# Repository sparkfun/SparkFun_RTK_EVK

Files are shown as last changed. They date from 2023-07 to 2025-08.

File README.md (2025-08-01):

SparkFun RTK EVK
========================================

SparkFun RTK EVK (https://www.sparkfun.com/sparkfun-rtk-evk.html)

[*SparkFun RTK EVK (GPS-24342)*](https://www.sparkfun.com/sparkfun-rtk-evk.html)

Designed and manufactured in Boulder, Colorado, USA, the SparkFun RTK Evaluation Kit is the perfect development platform for your fixed or mobile high-precision positioning and navigation needs. In terms of connectivity, the SparkFun RTK EVK has the lot: WiFi / BT, Ethernet and cellular!

Under the hood, the RTK EVK is based on the Espressif ESP32-WROVER processor with 16MB flash and 8MB PSRAM. The GNSS is the excellent dual-band ZED-F9P from u-blox. The u-blox NEO-D9S provides L-Band reception and access to correction services such as PointPerfect. The u-blox LARA-R6001D provides worldwide cellular connectivity; insert your nano SIM into the front panel and away you go! A WIZnet W5500 provides 10 / 100 megabit Ethernet connectivity. Data storage is micro-SD. The OLED display is 128x64 pixels. The EVK supports multiple power options, including: USB-C; Power over Ethernet (PoE); and DC voltages in the range 9V - 36V. 

Documentation
--------------

* **[Hookup Guide](http://docs.sparkfun.com/SparkFun_RTK_EVK/)** - Hookup Guide for the RTK EVK hosted by GitHub pages.
* **[RTK Everywhere Product Manual](https://docs.sparkfun.com/SparkFun_RTK_Everywhere_Firmware/)** - RTK Everywhere product manual hosted by GitHub Pages.

*Need to download or print our hookup guide?*

* [Print *(Print to PDF)* from Single-Page View](http://docs.sparkfun.com/SparkFun_RTK_EVK/print_view)

Repository Contents
-------------------

* **[/docs](/docs/)** - Online documentation files
    * **[assets](/docs/assets/)** - Assets files
        * **[RTK_EVK_Enclosure](/docs/assets/RTK_EVK_Enclosure/)**
            * **[/Front_Panel](/Front_Panel/)** - Eagle design files (.brd, .sch) for the prototype (PCB) enclosure panel used to validate the dimensions
            * **[/Front_Sticker](/Front_Sticker/)** - DXF and PDF files for the front sticker
            * **[/Rear_Panel](/Rear_Panel/)** - Eagle design files (.brd, .sch) for the prototype (PCB) enclosure panel used to validate the dimensions
            * **[/Rear_Sticker](/Rear_Sticker/)** - DXF and PDF files for the rear sticker
        * **[board_files](/docs/assets/board_files/)** - Files for the product design
        * **[img/](/docs/assets/img/hookup_guide/)** - Images for hookup guide documentation
* **[/Example_Sketches](/Example_Sketches/)** - Arduino IDE code examples
* **[/Hardware](/Hardware/)** - Eagle design files (.brd, .sch)
* **[/Production](/Production/)** - PCB panel production files

Firmware
----------------

The RTK Everywhere firmware has its own [dedicated repo](https://github.com/sparkfun/SparkFun_RTK_Everywhere_Firmware) as listed below.

* **[RTK Everywhere Firmware](https://github.com/sparkfun/SparkFun_RTK_Everywhere_Firmware)**
* **[RTK Everywhere Firmware Binaries](https://github.com/sparkfun/SparkFun_RTK_Everywhere_Firmware_Binaries)**

Product Variants
----------------

* [GPS-24342](https://www.sparkfun.com/sparkfun-rtk-evk.html)- v1.1, Initial Release

Version History
---------------

* v1.1- Initial Release

License Information
-------------------

This product is ***open source***!

Please review the [LICENSE.md](./LICENSE.md) file for license information.

If you have any questions or concerns about licensing, please contact technical support on our [SparkFun forums](https://forum.sparkfun.com/viewforum.php?f=152).

Distributed as-is; no warranty is given.

- Your friends at SparkFun.

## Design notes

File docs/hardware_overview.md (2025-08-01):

The electronics of the SparkFun RTK EVK is enclosed in a custom extruded aluminum case with machined end panels and slotted flanges.

<div style="text-align: center;">
  <table>
    <tr style="vertical-align:middle;">
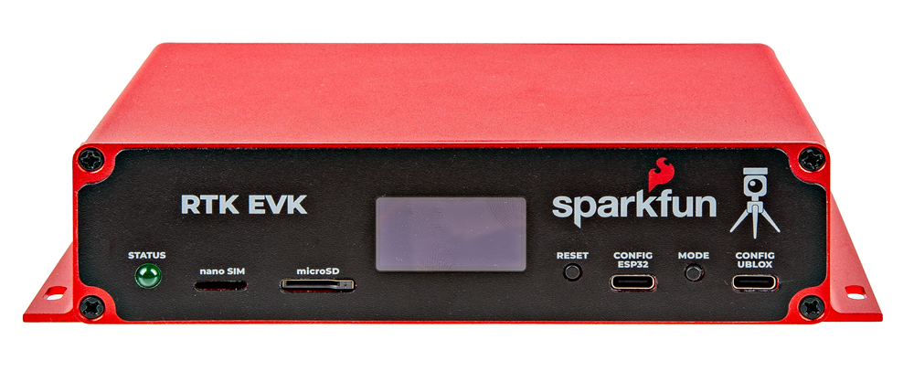
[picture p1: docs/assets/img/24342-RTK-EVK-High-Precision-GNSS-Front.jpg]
Front View
     <td style="text-align: center; vertical-align: middle; border: solid 1px #cccccc;"></td>
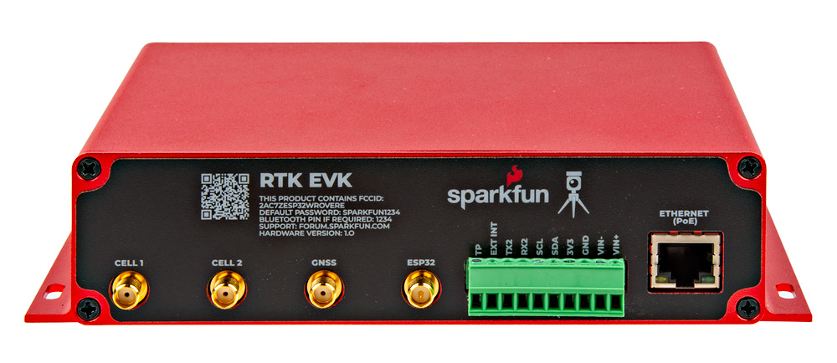
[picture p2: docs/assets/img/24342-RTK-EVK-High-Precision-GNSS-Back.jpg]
Back View
     <td style="text-align: center; vertical-align: middle; border: solid 1px #cccccc;"></td>
    </tr>
    <tr style="vertical-align:middle;">
     <td style="text-align: center; vertical-align: middle; border: solid 1px #cccccc;"><i>Front View</i></td>
     <td style="text-align: center; vertical-align: middle; border: solid 1px #cccccc;"><i>Back View</i></td>
    </tr>
  </table>
</div>

The image below shows a top and bottom view of the populated PCB without the enclosure.

<div style="text-align: center;">
  <table>
    <tr style="vertical-align:middle;">
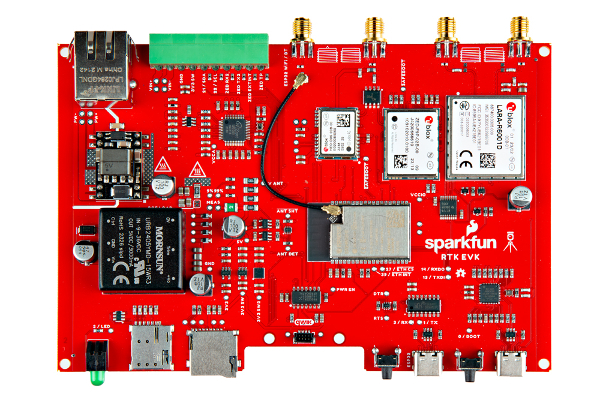
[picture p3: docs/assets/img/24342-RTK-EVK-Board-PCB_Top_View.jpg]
PCB Top View
     <td style="text-align: center; vertical-align: middle; border: solid 1px #cccccc;"></td>
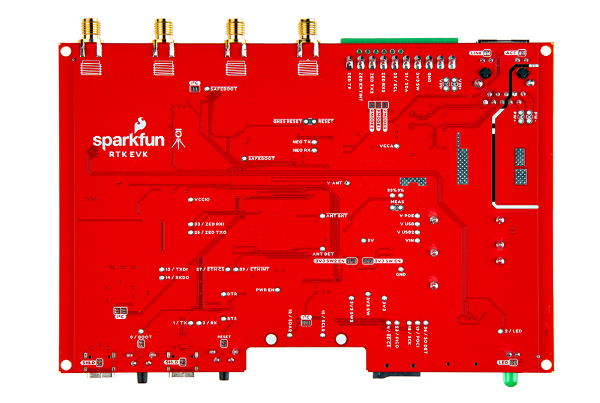
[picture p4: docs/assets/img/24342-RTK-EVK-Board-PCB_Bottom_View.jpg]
PCB Back View
     <td style="text-align: center; vertical-align: middle; border: solid 1px #cccccc;"></td>
    </tr>
    <tr style="vertical-align:middle;">
     <td style="text-align: center; vertical-align: middle; border: solid 1px #cccccc;"><i>PCB Top View</i></td>
     <td style="text-align: center; vertical-align: middle; border: solid 1px #cccccc;"><i>PCB Bottom View</i></td>
    </tr>
  </table>
</div>

### Power

The SparkFun RTK EVK can be powered from the connectors on the front or the back of the board. There is no internal battery. Schottky protection diodes and a resettable fuse are included to prevent conflicting voltages and overvoltage protection. Voltage is then regulated down to 3.3V through the three voltage regulators.

* **CONFIG ESP32** &mdash; The CONFIG ESP32 includes a USB C connector to power the RTK EVK. Users can also upload code or connect to the ESP32 to a serial terminal.
* **CONFIG UBLOX** &mdash; The CONFIG UBLOX includes a USB C connector to power the RTK EVK as well. A USB hub is connected to this port and connects to the ZED-F9P, NEO-D9S, and LARA-R6 for users that are interested in connecting them to u-center, m-center or updating the firmware.

<div style="text-align: center;">
  <table>
    <tr style="vertical-align:middle;">
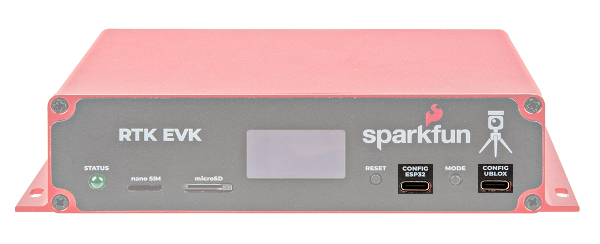
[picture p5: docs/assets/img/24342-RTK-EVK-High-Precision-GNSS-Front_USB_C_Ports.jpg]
USB Connectors Highlighted in Front
     <td style="text-align: center; vertical-align: middle; border: solid 1px #cccccc;"></td>
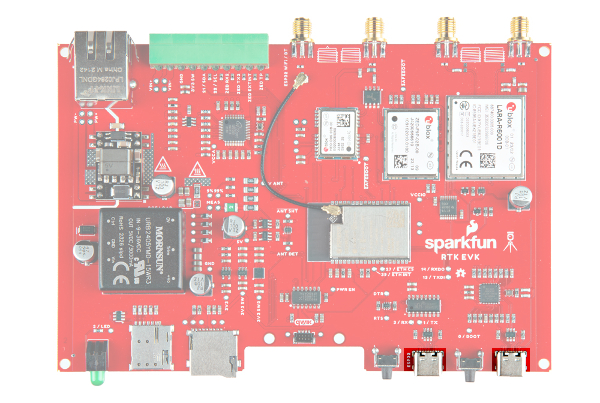
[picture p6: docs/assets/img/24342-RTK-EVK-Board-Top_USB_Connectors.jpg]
USB Connectors Highlighted PCB Top View
     <td style="text-align: center; vertical-align: middle; border: solid 1px #cccccc;"></td>
    </tr>
    <tr style="vertical-align:middle;">
     <td style="text-align: center; vertical-align: middle; border: solid 1px #cccccc;"><i>USB Connectors Highlighted in Front</i></td>
     <td style="text-align: center; vertical-align: middle; border: solid 1px #cccccc;"><i>USB Connectors Highlighted PCB Top View</i></td>
   </tr>
  </table>
</div>

Power can also be provided from the I/O screw terminals or PoE.

* **VIN+** &mdash; This terminal can be used to feed in external DC power between **+9V and +36V**. This is for users that want to power the unit from a vehicle battery or any other source in that voltage range. Connect VIN+ to the battery +ve. The voltage is first regulated to 5V by a fully-isolated DC-DC converter before being regulated again to 3.3V.
* **VIN-** &mdash; For external DC power, connect this terminal to the chassis, battery -ve or 0V. Note that there is no direct connection between VIN- and GND as the internal DC-DC converter is fully isolated. It is possible to link VIN- to the adjacent GND terminal, but doing so will bypass the voltage isolation and could introduce a ground loop.
* **GND** &mdash; The internal ground or 0V for the system.
* **Ethernet (PoE)** &mdash; The input voltage through the RJ45 connector can be between **+36V and +57V**. The voltage is first regulated down to 5V by the isolated PoE module before being regulated agin to 3.3V.

<div style="text-align: center;">
  <table>
    <tr style="vertical-align:middle;">
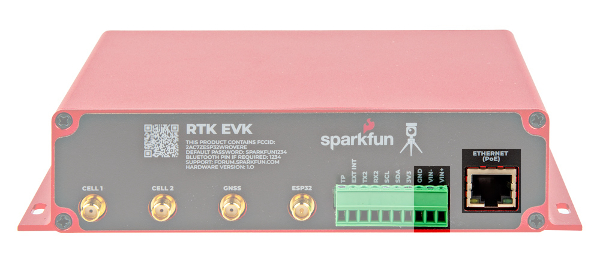
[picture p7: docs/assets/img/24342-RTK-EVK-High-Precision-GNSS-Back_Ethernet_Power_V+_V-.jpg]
USB Connector, Ethernet POE, and Power Input on Screw Terminals Highlighted in Back
     <td style="text-align: center; vertical-align: middle; border: solid 1px #cccccc;"></td>
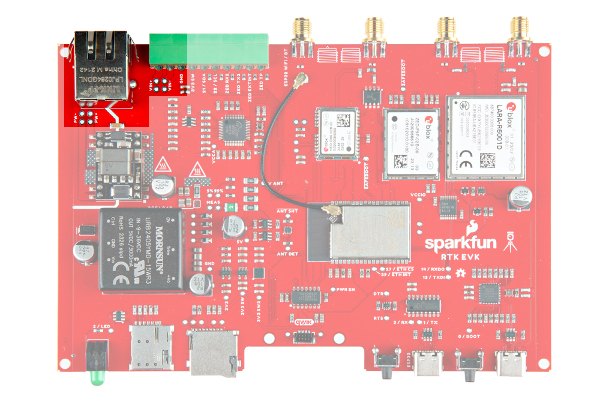
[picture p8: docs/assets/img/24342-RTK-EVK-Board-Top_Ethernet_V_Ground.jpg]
Ethernet POE, and Power Input on Screw Terminals Highlighted On PCB
     <td style="text-align: center; vertical-align: middle; border: solid 1px #cccccc;"></td>
    </tr>
    <tr style="vertical-align:middle;">
     <td style="text-align: center; vertical-align: middle; border: solid 1px #cccccc;"><i>USB Connector, Ethernet POE, and Power Input on Screw Terminals Highlighted in Back</i></td>
     <td style="text-align: center; vertical-align: middle; border: solid 1px #cccccc;"><i>Ethernet POE, and Power Input on Screw Terminals Highlighted on PCB</i></td>
    </tr>
    </tr>
  </table>
</div>

There is also an output power pin for 3.3V on the I/O screw terminal.

* **3V3** &mdash; This pin is the output of one of the 3.3V voltage regulators. Note that this is only connected to the secondary power. This net is also connected to the microSD card socket, ZED-F9P, NEO-D9S, USB Hub, MagJack RJ45 connector's LEDs, and WIZnet W5500.

<div style="text-align: center;">
  <table>
    <tr style="vertical-align:middle;">
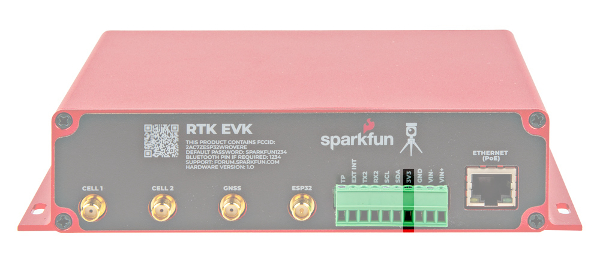
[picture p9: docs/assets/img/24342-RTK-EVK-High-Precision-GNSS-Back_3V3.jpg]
3.3V Input on Screw Terminals Highlighted in Back
     <td style="text-align: center; vertical-align: middle; border: solid 1px #cccccc;"></td>
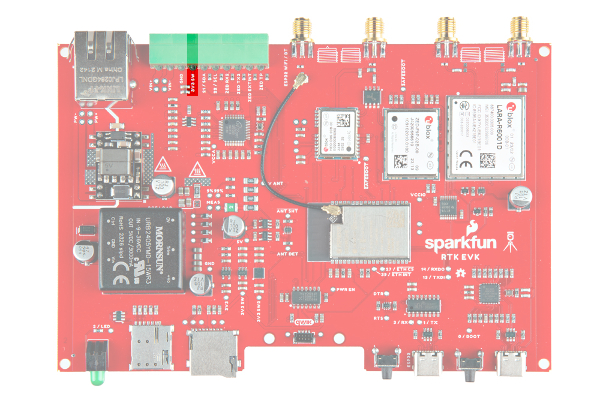
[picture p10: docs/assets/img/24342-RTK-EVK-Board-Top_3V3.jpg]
3.3V Input on Screw Terminals Highlighted on PCB
     <td style="text-align: center; vertical-align: middle; border: solid 1px #cccccc;"></td>
    </tr>
    <tr style="vertical-align:middle;">
     <td style="text-align: center; vertical-align: middle; border: solid 1px #cccccc;"><i>3.3V Input on Screw Terminals Highlighted in Back</i></td>
     <td style="text-align: center; vertical-align: middle; border: solid 1px #cccccc;"><i>3.3V Input on Screw Terminals Highlighted on PCB</i></td>
    </tr>
  </table>
</div>

### CH340 USB-to-Serial Converter

A CH340 USB-to-Serial converter is included between the USB-C connector and the ESP32. The chip can be used to send serial data between the RTK EVK and computer. You can view the output or configure the device through a serial terminal. You can also manually upload new firmware as well.

<div style="text-align: center;">
  <table>
    <tr style="vertical-align:middle;">
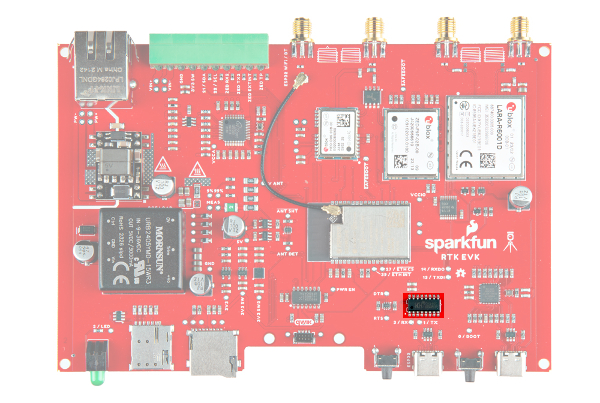
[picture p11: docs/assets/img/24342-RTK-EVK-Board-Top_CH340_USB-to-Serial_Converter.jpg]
CH340 USB-to-Serial Converter Highlighted
     <td style="text-align: center; vertical-align: middle; border: solid 1px #cccccc;"></td>
    </tr>
    <tr style="vertical-align:middle;">
     <td style="text-align: center; vertical-align: middle; border: solid 1px #cccccc;"><i>CH340 USB-to-Serial Converter Highlighted</i></td>
    </tr>
  </table>
</div>

The driver should automatically install on most operating systems. However, there is a wide range of operating systems out there. You may need to install drivers the first time you connect the chip to your computer's USB port or when there are operating system updates. For more information, check out our [How to Install CH340 Drivers Tutorial](https://learn.sparkfun.com/tutorials/how-to-install-ch340-drivers).

<div style="text-align: center">
  <table>
    <tr>
      <td style="text-align: center; vertical-align: middle; border: solid 1px #cccccc;">
        <a href="https://learn.sparkfun.com/tutorials/how-to-install-ch340-drivers">
          <div style="text-align: center">How to Install CH340 Drivers</div>
          <hr />
          <h3 style="text-align: left">
            <b>How to Install CH340 Drivers</b>
          </h3>
        </a>
      </td>
    </tr>
  </table>
</div>

### ESP32-WROVER Module

The [RTK Everywhere firmware](https://github.com/sparkfun/SparkFun_RTK_Everywhere_Firmware/tree/main/Firmware) is pre-loaded with the RTK EVK and flashed to the ESPRESSIF ESP32-WROVER module (with 16MB flash and 8MB PSRAM). The ESP32 handles all the processes. You can configure the EVK as a RTK base and push corrections to an NTRIP Caster. You can also configure the EVK as a RTK Rover and use corrections delivered over WiFi or Bluetooth. You can even update firmware over-the-air. For more information, we recommend checking out the [RTK Everywhere Product Manual](https://docs.sparkfun.com/SparkFun_RTK_Everywhere_Firmware/).

<div style="text-align: center;">
  <table>
    <tr style="vertical-align:middle;">
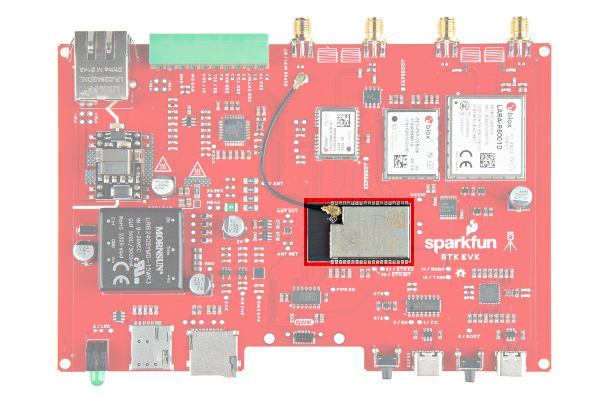
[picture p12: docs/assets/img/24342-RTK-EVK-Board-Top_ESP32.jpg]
ESP32 Highlighted
     <td style="text-align: center; vertical-align: middle; border: solid 1px #cccccc;"></td>
    </tr>
    <tr style="vertical-align:middle;">
     <td style="text-align: center; vertical-align: middle; border: solid 1px #cccccc;"><i>ESP32 Highlighted</i></td>
    </tr>
  </table>
</div>

!!! note
    The ESP32-WROVER module can only connect to a 2.4GHz WiFi network. Unfortunately, 5GHz is not supported on the ESP32-WROVER module.

For users that want to configure the ESP32 using a serial terminal, you will simply need to connect the CONFIG ESP32 to your computer's USB port. Once connected, open a serial terminal set to **115200 baud** and press any key to open the [serial configuration menu](https://docs.sparkfun.com/SparkFun_RTK_Everywhere_Firmware/configure_with_serial/#rtk-torch). Of course, this is only one method of adjusting the settings. You can also change the settings through WiFi, Bluetooth, and a text file saved on a microSD card.

### ESP32 Primary I<sup>2</sup>C Port

The screw terminal on the back includes an I<sup>2</sup>C port. This is connected to the ESP32&apos;s primary I<sup>2</sup>C port and is shared by the ZED-F9P and NEO-D9S.

* **SCL** &mdash; The ESP32 I<sup>2</sup>C bus clock on pin 22. The logic level is 3.3V. Currently, there are no pull-up resistors attached to this line. To configure, you will need to add a solder blob to the I<sup>2</sup>C jumper.
* **SDA** &mdash;ESP32 I<sup>2</sup>C bus data on pin 21. The logic level is 3.3V. Currently, there are no pull-up resistors attached to this line. To attach the 2.2k&ohm; pull-up resistors to the port, you will just need to add a solder blob to the I<sup>2</sup>C jumper.

!!! note
    3.3V and GND are also conveniently placed next to the SCL and SDA pins. These follow the same pinout as most of the SparkFun I<sup>2</sup>C breakout boards with PTHs.

<div style="text-align: center;">
  <table>
    <tr style="vertical-align:middle;">
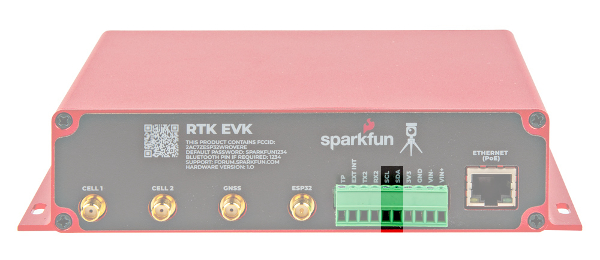
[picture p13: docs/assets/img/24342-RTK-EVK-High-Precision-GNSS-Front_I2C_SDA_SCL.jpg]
     <td style="text-align: center; vertical-align: middle; border: solid 1px #cccccc;"></td>
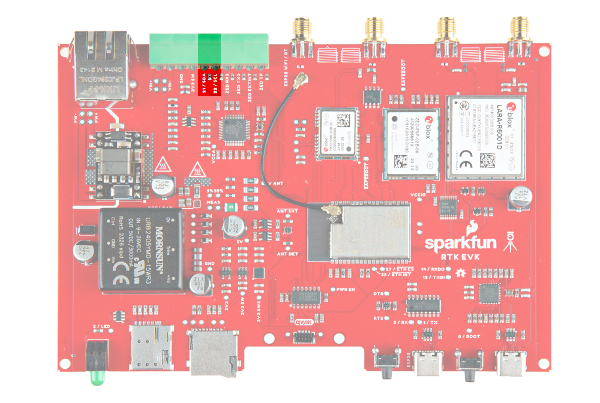
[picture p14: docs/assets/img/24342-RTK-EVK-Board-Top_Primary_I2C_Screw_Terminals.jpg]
     <td style="text-align: center; vertical-align: middle; border: solid 1px #cccccc;"></td>
    </tr>
    <tr style="vertical-align:middle;">
     <td style="text-align: center; vertical-align: middle; border: solid 1px #cccccc;"><i>I<sup>2</sup>C Port Highlighted</i></td>
     <td style="text-align: center; vertical-align: middle; border: solid 1px #cccccc;"><i>I<sup>2</sup>C Port Highlighted on PCB</i></td>
    </tr>
  </table>
</div>

The I<sup>2</sup>C peripherals connected to the primary I<sup>2</sup>C port and their address are listed below:

* ZED-F9P &mdash; 0x42 (default)
* NEO-D9S &mdash; 0x43 (default)

### ESP32 Secondary I<sup>2</sup>C Port

Inside of the enclosure, there is a Qwiic vertical port available. This is connected to the Qwiic OLED via a Qwiic cable. This port is connected to the ESP32's secondary I<sup>2</sup>C port with SCL connected to pin 15 and SDA connected to pin 12. The logic level is also 3.3V. Currently, there are no pull-up resistors attached to this line. To attach the 2.2k&ohm; pull-up resistors to the port, you will just need to add a solder blob to the I<sup>2</sup>C jumper.

<div style="text-align: center;">
  <table>
    <tr style="vertical-align:middle;">
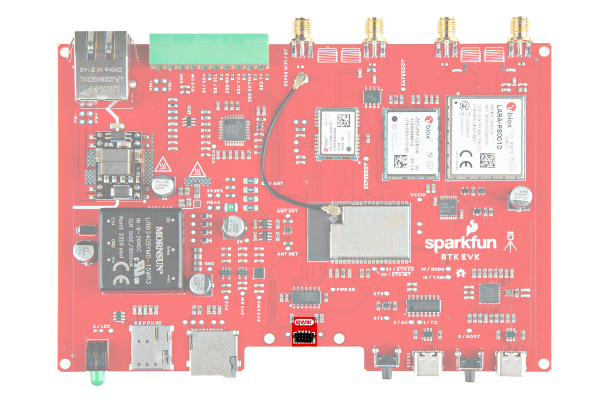
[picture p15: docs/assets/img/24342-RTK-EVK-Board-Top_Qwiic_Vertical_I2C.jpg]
     <td style="text-align: center; vertical-align: middle; border: solid 1px #cccccc;"></td>
    </tr>
    <tr style="vertical-align:middle;">
     <td style="text-align: center; vertical-align: middle; border: solid 1px #cccccc;"><i>I2C Port Highlighted</i></td>
    </tr>
  </table>
</div>

The I<sup>2</sup>C peripheral connected to the secondary I<sup>2</sup>C port and their address is listed below:

* Qwiic OLED - (1.3in., 128x64) &mdash; 0x3D (default)

### Qwiic OLED Display

The RTK EVK includes the SparkFun Qwiic OLED - (1.3in., 128x64). This is connected to the ESP32 via a Qwiic port contained within the enclosure. As stated earlier, the default address for the display is 0x3D. The display provides useful information about the RTK EVK without needing to connect to a serial terminal.

<div style="text-align: center;">
  <table>
    <tr style="vertical-align:middle;">
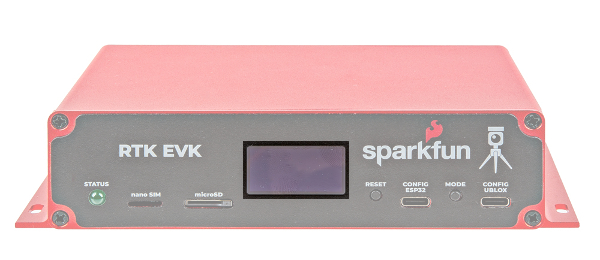
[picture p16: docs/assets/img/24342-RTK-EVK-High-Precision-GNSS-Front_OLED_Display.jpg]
OLED Display Highlighted
     <td style="text-align: center; vertical-align: middle; border: solid 1px #cccccc;"></td>
    </tr>
    <tr style="vertical-align:middle;">
     <td style="text-align: center; vertical-align: middle; border: solid 1px #cccccc;"><i>OLED Display Highlighted</i></td>
    </tr>
  </table>
</div>

Below show some of the possible outputs from the RTK EVK. The icons are explained further in the [RTK Everywhere Product Manual > Hardware > Displays](https://docs.sparkfun.com/SparkFun_RTK_Everywhere_Firmware/displays/).

The image below shows the Bluetooth MAC address of the RTK EVK on the upper left hand corner of the screen. If there is a Bluetooth connection, the Blueooth symbol will display. To the right is the WiFi symbol. To the right of the WiFi symbol is the icon indicating the selected dynamic model, in this case it's the default portable icon. On the upper far right, is the Ethernet connection symbol. Below the Bluetooth MAC address is the RTK float solution symbol. The number to the right indicates the horizontal position accuracy. In this case, there is an RTK float since the value is between 0.400 meters to 0.200 meters. To the right is the satellites in view symbol and number of satellites. The additional antenna lines indicates that the RTK EVK that there is successful reception and decryptions of L-band corrections. Finally, the rotating semi-circle indicates the RTK EVK firmware is running. This changes to a logging icon when data is being logged to microSD card.

<div style="text-align: center;">
  <table>
    <tr style="vertical-align:middle;">
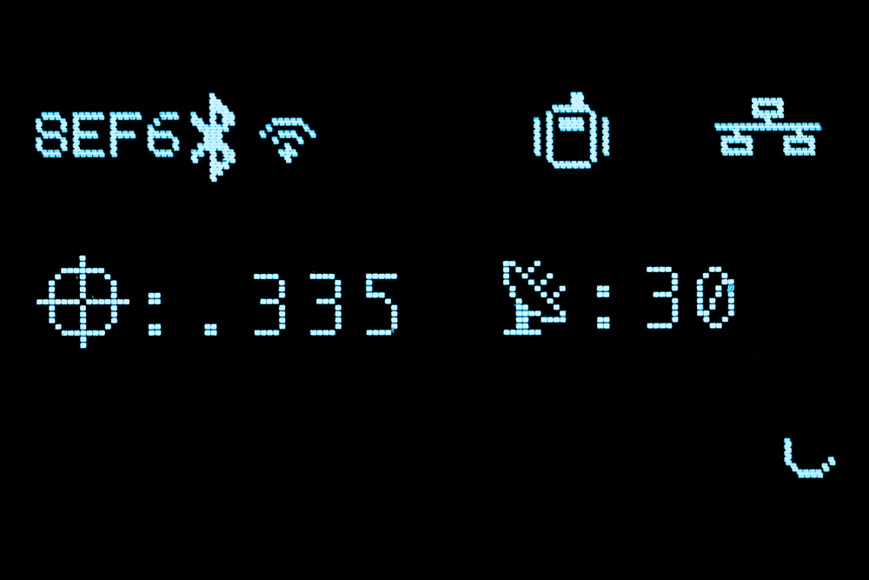
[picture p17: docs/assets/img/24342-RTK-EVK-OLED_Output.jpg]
OLED Output
     <td style="text-align: center; vertical-align: middle; border: solid 1px #cccccc;"></td>
    </tr>
    <tr style="vertical-align:middle;">
     <td style="text-align: center; vertical-align: middle; border: solid 1px #cccccc;"><i>OLED Display Output</i></td>
    </tr>
  </table>
</div>

The image below is similar to the previous display output. You&apos;ll notice a few differences. The arrow pointing down indicates that there are corrections being received. The Ethernet symbol is also not displaying since there was no Ethernet connection at that moment. The horizontal positional accuracy indicates that there is a RTK fixed solution with the double cross hairs since the value is below 0.200 meters. Finally, the display is showing 29 satellites in view and no L-band corrections.

<div style="text-align: center;">
  <table>
    <tr style="vertical-align:middle;">
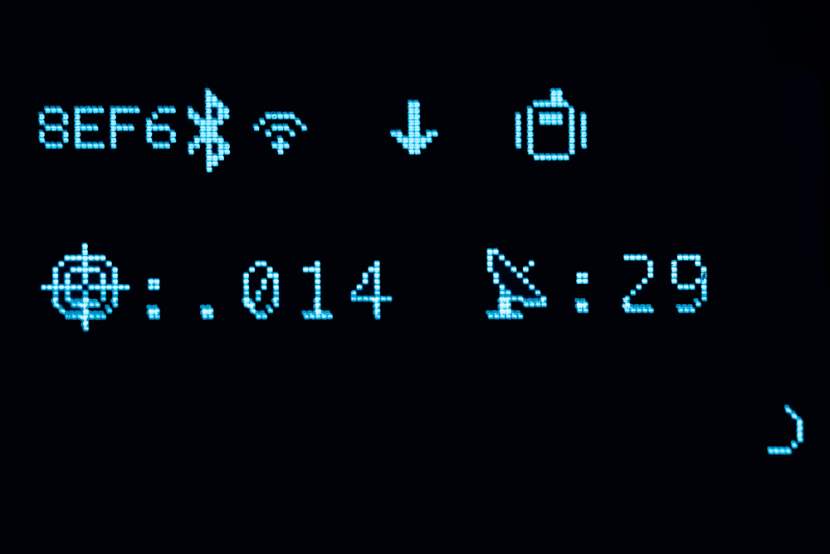
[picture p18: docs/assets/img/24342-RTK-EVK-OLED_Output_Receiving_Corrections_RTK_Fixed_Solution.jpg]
OLED Output with RTK Fixed Solution
     <td style="text-align: center; vertical-align: middle; border: solid 1px #cccccc;"></td>
    </tr>
    <tr style="vertical-align:middle;">
     <td style="text-align: center; vertical-align: middle; border: solid 1px #cccccc;"><i>OLED Display with RTK Fixed Solution</i></td>
    </tr>
  </table>
</div>

### ZED-F9P Module

The RTK EVK wouldn't be a an RTK without well... a high precision RTK. The RTK EVK includes a built-in u-blox ZED-F9P module for high precision GNSS. You will need to connect an active multiband antenna that is capable of receiving L1 and L2 signals. The ZED-F9P can be set as a base station or rover. There are several options to send or receive correction data depending on the mode: Ethernet, WiFi network, LTE cellular network, or the NEO-D9S. As stated earlier, the ZED-F9P is connected to the primary I<sup>2</sup>C port and uses the default address of 0x42.

<div style="text-align: center;">
  <table>
    <tr style="vertical-align:middle;">
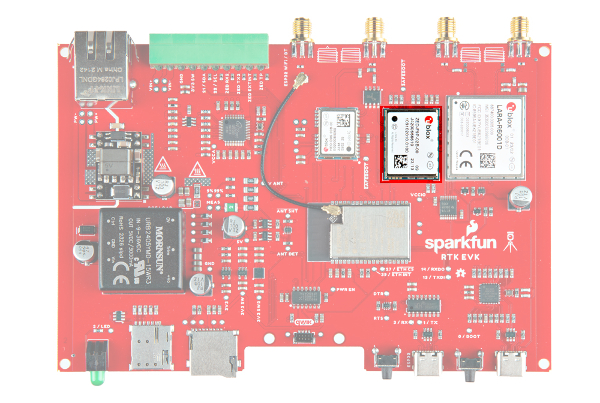
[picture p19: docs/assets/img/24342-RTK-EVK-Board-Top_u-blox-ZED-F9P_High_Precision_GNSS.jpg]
ZED-F9P Highlighted
     <td style="text-align: center; vertical-align: middle; border: solid 1px #cccccc;"></td>
    </tr>
    <tr style="vertical-align:middle;">
     <td style="text-align: center; vertical-align: middle; border: solid 1px #cccccc;"><i>ZED-F9P Highlighted</i></td>
    </tr>
  </table>
</div>

Below are a few specifications taken from the ZED-F9P&apos;s datasheet:

* Concurrent reception of GPS, GLONASS, Galileo, and BeiDou
* Receives both L1C/A and L2C bands
* 184-channel u-blox F9 engine
* Time to First Fix: 25s (cold), 2s (hot)
* Max Navigation Rate: 20Hz / 25Hz depending on mode
* Horizontal Position Accuracy: 2.5m without RTK; 0.010m with RTK
* Max Altitude: 50km (31 miles)
* Max Velocity: 500m/s (1118mph)

### ZED-F9P Secondary UART Port

The screw terminal on the back includes a UART port. This is connected to the ZED-F9P's secondary UART port (UART2) for users that want to connect to other high precision GNSS modules for correction data.

* **TX2** &mdash; The ZED-F9P's UART2 transmit pin. The logic level is 3.3V. Users can connect this pin to a radio module or directly to a high precision GNSS module's RX pin to provide correction data to other rovers.
* **RX2** &mdash; The ZED-F9P's UART2 receive pin. The logic level is 3.3V. Users can connect this pin to a radio module or directly to a high precision GNSS module's TX pin to receive correction data provided by another base station.

<div style="text-align: center;">
  <table>
    <tr style="vertical-align:middle;">
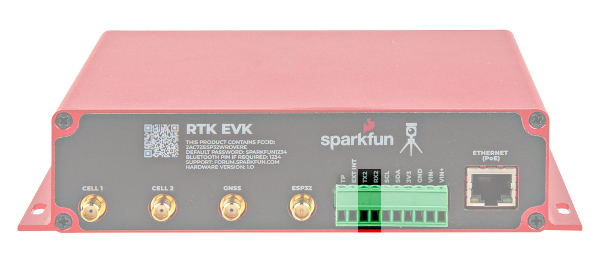
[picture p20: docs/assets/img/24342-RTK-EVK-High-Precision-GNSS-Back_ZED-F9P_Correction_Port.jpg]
ZED-F9P UART Correction Port Highlighted
     <td style="text-align: center; vertical-align: middle; border: solid 1px #cccccc;"></td>
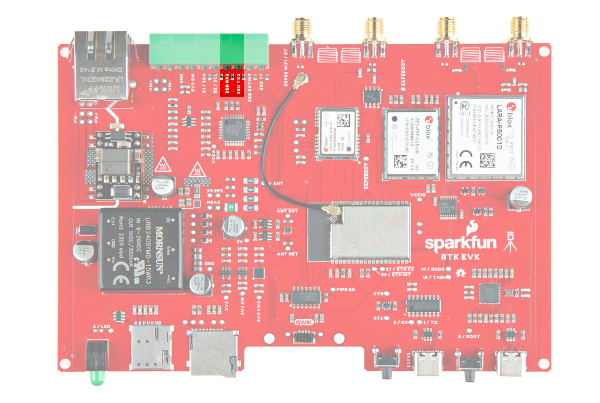
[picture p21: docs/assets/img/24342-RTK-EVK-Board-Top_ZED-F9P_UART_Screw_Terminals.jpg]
ZED-F9P UART Correction Port Highlighted on PCB
     <td style="text-align: center; vertical-align: middle; border: solid 1px #cccccc;"></td>
    </tr>
    <tr style="vertical-align:middle;">
     <td style="text-align: center; vertical-align: middle; border: solid 1px #cccccc;"><i>ZED-F9P UART Correction Port Highlighted</i></td>
     <td style="text-align: center; vertical-align: middle; border: solid 1px #cccccc;"><i>ZED-F9P UART Correction Port Highlighted on PCB</i></td>
    </tr>
  </table>
</div>

### ZED-F9P External Interrupt

The screw terminal on the back includes an external interrupt for the ZED-F9P. The interrupt can either be an input/output pin. This can be configured using u-center to bring the module out of deep sleep or to output an interrupt for various module states. In the RTK Everywhere firmware, this terminal can be used to trigger and log a UBX-TIM-TM2 timing message. The logic level is 3.3V.

<div style="text-align: center;">
  <table>
    <tr style="vertical-align:middle;">
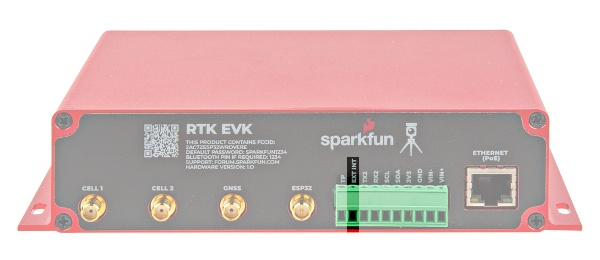
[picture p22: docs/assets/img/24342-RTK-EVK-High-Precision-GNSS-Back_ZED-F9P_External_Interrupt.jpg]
ZED-F9P External Interrupt Highlighted
     <td style="text-align: center; vertical-align: middle; border: solid 1px #cccccc;"></td>
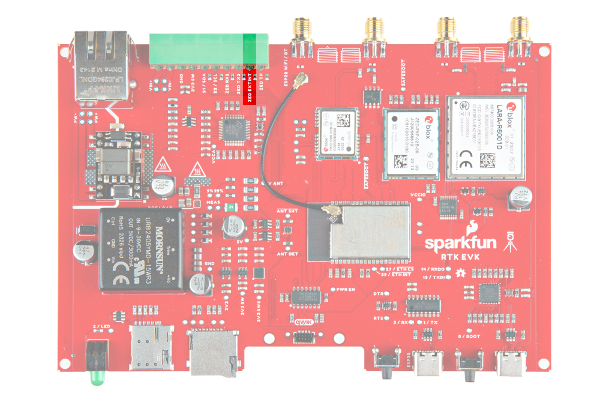
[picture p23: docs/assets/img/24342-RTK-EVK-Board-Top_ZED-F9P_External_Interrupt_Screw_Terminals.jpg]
ZED-F9P External Interrupt Highlighted on PCB
     <td style="text-align: center; vertical-align: middle; border: solid 1px #cccccc;"></td>
    </tr>
    <tr style="vertical-align:middle;">
     <td style="text-align: center; vertical-align: middle; border: solid 1px #cccccc;"><i>ZED-F9P External Interrupt Highlighted</i></td>
     <td style="text-align: center; vertical-align: middle; border: solid 1px #cccccc;"><i>ZED-F9P External Interrupt Highlighted on PCB</i></td>
    </tr>
  </table>
</div>

### ZED-F9P Time Pulse

The screw terminal on the back labeled as **TP** includes ZED-F9Ps time pulse output (i.e. the pulse-per-second or PPS output). This pulses at 1Hz when the module gets basic GPS/GNSS position lock and can be configured using the u-center. The logic level is 3.3V.

<div style="text-align: center;">
  <table>
    <tr style="vertical-align:middle;">
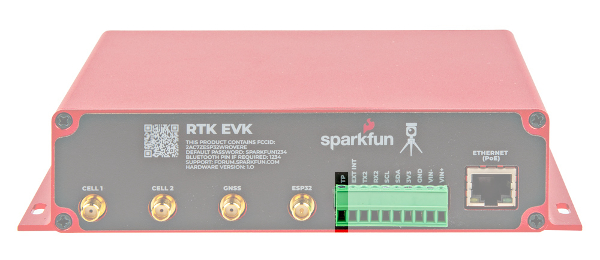
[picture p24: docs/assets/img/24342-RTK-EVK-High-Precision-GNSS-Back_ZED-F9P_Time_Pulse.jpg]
ZED-F9P Time Pulse Highlighted
     <td style="text-align: center; vertical-align: middle; border: solid 1px #cccccc;"></td>
     <td style="text-align: center; vertical-align: middle; border: solid 1px #cccccc;"><a href="../assets/img/24342-RTK-EVK-Board-Top_ZED-F9P_Time_Pulse_Screw_Terminals.jpg">ZED-F9P Time Pulse Highlighted on PCB</a></td>
    </tr>
    <tr style="vertical-align:middle;">
     <td style="text-align: center; vertical-align: middle; border: solid 1px #cccccc;"><i>ZED-F9P Time Pulse Highlighted</i></td>
     <td style="text-align: center; vertical-align: middle; border: solid 1px #cccccc;"><i>ZED-F9P Time Pulse Highlighted on PCB</i></td>
    </tr>
  </table>
</div>

### NEO-D9S

The RTK EVK includes the built-in u-blox NEO-D9S for correction data. You will need to connect an antenna that is capable of receiving signals from the L-band to access [u-blox PointPerfect correction service](https://www.u-blox.com/en/product/pointperfect). The NEO-D9S is connected to the primary I<sup>2</sup>C port and uses the default address of 0x43. You will need a service provider to access the correction data.

<div style="text-align: center;">
  <table>
    <tr style="vertical-align:middle;">
     <td style="text-align: center; vertical-align: middle; border: solid 1px #cccccc;"><a href="../assets/img/24342-RTK-EVK-Board-Top_u-blox-NEO-D9S_Correction_Data_Receiver.jpg">NEO-D9S Highlighted</a></td>
    </tr>
    <tr style="vertical-align:middle;">
     <td style="text-align: center; vertical-align: middle; border: solid 1px #cccccc;"><i>NEO-D9S Highlighted</i></td>
    </tr>
  </table>
</div>

Below are a few specifications taken from the NEO-D9S&apos;s datasheet:

* L-Band data receiver compliance: SESTB28A
* Frequency range: 1525 to 1559MHz
* Sensitivity: 133dBm
* Time to First Frame: <10s
* Receives PMP messages from Inmarsat Geosynchronous Satellites

### MicroSD Card Socket

The front of the RTK EVK includes a microSD card socket. Insert a microSD card into the socket until it clicks in place. Pushing the microSD card again will eject the memory card. This is connected to the ESP32&apos;s SPI port. Power is provided by the secondary power source. Users can manually flash the firmware binaries using the microSD card as opposed to over-the-air updates. Typically, the microSD card is for datalogging. The microSD card can also hold the user preferences for anyone that is interested in deploying multiple RTK EVKs with the same settings out in the field.

<div style="text-align: center;">
  <table>
    <tr style="vertical-align:middle;">
     <td style="text-align: center; vertical-align: middle; border: solid 1px #cccccc;"><a href="../assets/img/24342-RTK-EVK-High-Precision-GNSS-Front_MicroSD_Card_Slot.jpg">Back View</a></td>
     <td style="text-align: center; vertical-align: middle; border: solid 1px #cccccc;"><a href="../assets/img/24342-RTK-EVK-Board-Top_microSD_Card_Socket.jpg">Back View</a></td>
    </tr>
    <tr style="vertical-align:middle;">
     <td style="text-align: center; vertical-align: middle; border: solid 1px #cccccc;"><i>MicroSD Card Slot Highlighted</i></td>
     <td style="text-align: center; vertical-align: middle; border: solid 1px #cccccc;"><i>MicroSD Card Slot Highlighted on PCB</i></td>
    </tr>
  </table>
</div>

### LARA-R6 Cellular Module

The RTK EVK also includes the u-blox LARA-R6 cellular module for users that need to connect to a LTE cellular network. The module is connected to the ESP32 via UART.

<div style="text-align: center;">
  <table>
    <tr style="vertical-align:middle;">
     <td style="text-align: center; vertical-align: middle; border: solid 1px #cccccc;"><a href="../assets/img/24342-RTK-EVK-Board-Top_u-blox-LARA-R6_Cellular_Module.jpg">LARA-R6 Highlighted</a></td>
    </tr>
    <tr style="vertical-align:middle;">
     <td style="text-align: center; vertical-align: middle; border: solid 1px #cccccc;"><i>LARA-R6 Highlighted</i></td>
    </tr>
  </table>
</div>

Below are a few specifications taken from the LARA-R6&apos;s datasheet:

  * Region: Global
  * LTE FDD Bands: 1, 2, 3, 4, 5, 7, 8, 12, 13, 18, 19, 20, 26, & 28
  * Certifications and approvals:
  * PTCRB, GCF, FCC, ISED, RED, UKCA, NCC, RCM, Giteki, Anatel, KC, AT&T,
  * Verizon, T-Mobile, Deutsche Telekom, Telefonica, NTT DoCoMo, SBM, KDDI, Telstra

!!! note
    Although the LARA supports GSM/GPRS, the RTK EVK does not due to the high current required.

### Nano SIM Card Socket

To connect to an cellular network with the built-in u-blox LARA-R6 (specifically the LARA-R6001D), you will need a nano SIM card. The cellular module works with most major North American carriers (Verizon, T-Mobile, AT&T, etc.). Make sure to check with your network service provider for compatibility. You also may need approval with the service carrier before the service is activated. We recommend using the [Hologram SIM Card](https://www.sparkfun.com/products/17117). Insert the SIM with the contacts facing down, insert the edge with the chamfered corner first.

<div style="text-align: center;">
  <table>
    <tr style="vertical-align:middle;">
     <td style="text-align: center; vertical-align: middle; border: solid 1px #cccccc;"><a href="../assets/img/24342-RTK-EVK-High-Precision-GNSS-Front_Nano_SIM_Card_Slot.jpg">LED Highlighted</a></td>
     <td style="text-align: center; vertical-align: middle; border: solid 1px #cccccc;"><a href="../assets/img/24342-RTK-EVK-Board-Top_nano_SIM_Card_Socket.jpg">LED Highlighted</a></td>
    </tr>
    <tr style="vertical-align:middle;">
     <td style="text-align: center; vertical-align: middle; border: solid 1px #cccccc;"><i>Nano SIM Card Socket Highlighted</i></td>
     <td style="text-align: center; vertical-align: middle; border: solid 1px #cccccc;"><i>Nano SIM Card Socket Highlighted on PCB</i></td>
    </tr>
  </table>
</div>

### WIZnet W5500 IC, Ethernet Jack, and PoE

The RTK EVK includes a built-in Ethernet circuitry. You can connect an Ethernet cable to the back of the RTK EVK's RJ45 MagJack port. This connector includes status LEDs for Link and Activity. These LEDs can be disabled by cutting the jumpers on the back of the PCB. The port connects to the Power-over-Ethernet (PoE) module and WIZnet W5500 Ethernet transceiver. 10/100Mbps is supported with auto-negotiation. As stated earlier, the PoE module can be powered using the standard PoE voltages between +36V to +57V. Make sure to choose a PoE Ethernet Switch that meeds your needs. We have had good experience with the [TP Link TL-SG1005P](https://www.tp-link.com/us/business-networking/poe-switch/tl-sg1005p/) - available from many retailers including [Amazon](https://www.amazon.com/TP-Link-Compliant-Shielded-Optimization-TL-SG1005P/dp/B076HZFY3F).

<div style="text-align: center;">
  <table>
    <tr style="vertical-align:middle;">

     <td style="text-align: center; vertical-align: middle; border: solid 1px #cccccc;"><a href="../assets/img/24342-RTK-EVK-High-Precision-GNSS-Back_Ethernet_LEDs.jpg">Ethernet Jack</a></td>
     <td style="text-align: center; vertical-align: middle; border: solid 1px #cccccc;"><a href="../assets/img/24342-RTK-EVK-Board-Top_WIZnet_W5500_Ethernet_Jack_PoE_Module.jpg">WIZnet W5500 IC, Ethernet Jack, and PoE Module Highlighted</a></td>
    </tr>
    <tr style="vertical-align:middle;">
     <td style="text-align: center; vertical-align: middle; border: solid 1px #cccccc;"><i>Ethernet Jack Highlighted</i></td><td style="text-align: center; vertical-align: middle; border: solid 1px #cccccc;"><i>WIZnet W5500 IC, Ethernet Jack, and PoE Module Highlighted</i></td>
    </tr>
  </table>
</div>

### Antenna Connections

The back of the SparkFun RTK EVK includes a few connectors for cellular, GNSS, and WiFi antennas.

* **Cell 1** &mdash; The SMA Connector labeled as **Cell 1** is for the u-blox LARA-R6006. This connection represents the main RF input/output for LTE/3G/2G RF signals transmission and reception. This is intended to connect the LTE Hinged External Antenna - 698MHz-2.7GHz.
* **Cell 2** &mdash; The SMA Connector labled as **Cell 1** is for the u-blox LARA-R606. This connection represents the secondary RF input for LTE/3G Rx diversity and LTE MIMO 2x2 down-link RF signals reception. This is intended to connect the second LTE Hinged External Antenna - 698MHz-2.7GHz.
* **GNSS** &mdash; The SMA connector labeled as **GNSS** is for the u-blox ZED-F9P and NEO-D9S. This is connected to a GNSS splitter (Power Divider) and allows you to connect a single GNSS antenna for both modules. This is intended to connect an active multiband GNSS antenna using the SMA male to TNC male interface cable that is included in the kit. The RTK EVK provides 5V on this connector for an active multiband antenna instead of the usual 3.3V. Short-circuit and open-circuit detection is built into this connection as well. The following icons will flash whenever the RTK EVK does not detect an antenna (i.e. an open circuit) or if there is a short in the cable. Next to the icons will also indicate that there will be 0 satellites in view.

    <div style="text-align: center;">
      <table>
        <tr style="vertical-align:middle;">
         <td style="text-align: center; vertical-align: middle; border: solid 1px #cccccc;"><a href="../assets/img/24342-RTK-EVK-OLED_Antenna_Open_Highlighted.jpg">Antenna Open Circuit Highlighted</a></td>
         <td style="text-align: center; vertical-align: middle; border: solid 1px #cccccc;"><a href="../assets/img/24342-RTK-EVK-OLED_Antenna_Short_Highlighted.jpg">Antenna Short Circuit Highlighted</a></td>
        </tr>
        <tr style="vertical-align:middle;">
         <td style="text-align: center; vertical-align: middle; border: solid 1px #cccccc;"><i>Antenna Open Circuit Highlighted</i></td>
         <td style="text-align: center; vertical-align: middle; border: solid 1px #cccccc;"><i>Antenna Short Circuit Highlighted</i></td>
        </tr>
      </table>
    </div>

* **ESP32** &mdash; The RP-SMA connector labeled as **ESP32** is for the ESP32-WROVER. This is intended to connect the 2.4GHz WiFi/BT antenna.

<div style="text-align: center;">
  <table>
    <tr style="vertical-align:middle;">
     <td style="text-align: center; vertical-align: middle; border: solid 1px #cccccc;"><a href="../assets/img/24342-RTK-EVK-High-Precision-GNSS-Back_SMA_RPSMA_Antenna_Connectors.jpg">Antenna Connectors Highlighted on Back</a></td>
     <td style="text-align: center; vertical-align: middle; border: solid 1px #cccccc;"><a href="../assets/img/24342-RTK-EVK-Board-Top_SMA_RPSMA_Connectors.jpg">Antenna Connectors Highlighted on PCB</a></td>
    </tr>
    <tr style="vertical-align:middle;">
     <td style="text-align: center; vertical-align: middle; border: solid 1px #cccccc;"><i>Antenna Connectors Highlighted on Back</i></td>
     <td style="text-align: center; vertical-align: middle; border: solid 1px #cccccc;"><i>Antenna Connectors Highlighted on PCB</i></td>
    </tr>
  </table>
</div>

### Buttons

There are two buttons located on the front of the SparkFun RTK EVK.

* **RESET** &mdash; The reset button is available for users that need to manually reset the ESP32. The reset button sits flush against the front panel to prevent users from accidentally resetting the RTK EVK. You will need to press the button firmly or use a pen.
* **MODE** The mode button is available for users that want to change the mode. This button is connected to pin **0** on the ESP32 and can also be used as a boot button to set the ESP32 into bootloader mode when manually uploading code with the reset button.

<div style="text-align: center;">
  <table>
    <tr style="vertical-align:middle;">
     <td style="text-align: center; vertical-align: middle; border: solid 1px #cccccc;"><a href="../assets/img/24342-RTK-EVK-High-Precision-GNSS-Front_RESET_BOOT_MODE_Button.jpg">Reset and Mode/Boot Buttons Highlighted</a></td>
     <td style="text-align: center; vertical-align: middle; border: solid 1px #cccccc;"><a href="../assets/img/24342-RTK-EVK-Board-Top_Buttons.jpg">Reset and Mode/Boot Buttons Highlighted</a></td>
    </tr>
    <tr style="vertical-align:middle;">
     <td style="text-align: center; vertical-align: middle; border: solid 1px #cccccc;"><i>Reset and Mode/Boot Buttons Highlighted</i></td>
     <td style="text-align: center; vertical-align: middle; border: solid 1px #cccccc;"><i>Reset and Mode/Boot Buttons Highlighted on PCB</i></td>
    </tr>
  </table>
</div>

* **RTK Modes** &mdash; The available modes for the RTK Everywhere firmware are listed below. A single press brings up the mode menu. Press the button again to step through the available modes listed below. Pause on the highlighted mode then double-click to select it and change to that mode. For more information on the modes, make sure to check out the [RTK Everywhere Manual](https://docs.sparkfun.com/SparkFun_RTK_Everywhere_Firmware/).
    * **BASE**
        * This is the default mode as it is the mode we think most users will want to use - but you always surprise us with the novel ways you use our products!
        * The RTK EVK will perform a short 1-2 minute "survey-in" to establish the approximate position of the antenna (~1m accuracy).
        * It will then start generating RTCM correction data and - once configured - can send it to an NTRIP Caster over Ethernet or WiFi.
        * The RTCM data will also be output as 3.3V Serial (UART) data on the ZED-F9P TX2 I/O screw connection on the rear panel. You can connect a radio transceiver to that pin if desired.
        * You can establish the antenna position more accurately by collecting 'raw' satellite data for ~24 hours and post-processing it. You can find full instructions in the [RTK Everywhere Product Manual](https://docs.sparkfun.com/SparkFun_RTK_Everywhere_Firmware/menu_base/).
    * **ROVER**
        * The RTK EVK can of course also be used as a RTK Rover.
        * In Rover mode, the antenna position and other data is logged to microSD card.
        * Once configured, RTCM correction data can be received over Ethernet, WiFi or Bluetooth from a NTRIP Caster and used to achieve an accuracy of ~1.4cm under good conditions.
        * Use Rover mode to collect the 'raw' satellite data to establish your antenna's position accurately for Base mode.
    * **NTP**
        * The RTK EVK can also act as a Network Time Protocol Server - servicing NTP requests over Ethernet.
        * The firmware defaults to using DHCP to obtain an IP Address. But you can also configure it to use a fixed IP Address and can define the DNS, Gateway and Subnet Mask too.
        * You can find full instructions in the [RTK Everywhere Product Manual](https://docs.sparkfun.com/SparkFun_RTK_Everywhere_Firmware/menu_ntp/).
    * **Cfg Eth** (Configure-Via-Ethernet)
        * Abbreviated as "Cfg Eth", Configure-Via-Ethernet mode is a dedicated mode where the RTK EVK Station can be configured via a web page over Ethernet.
        * This mode works best with exclusive access to the WIZnet W5500 chip and the SPI bus and so the RTK EVK actually reboots when this mode is selected.
        * When leaving this mode - either by exiting the web page or by pressing the Mode button - the RTK EVK will reboot again into Base, Rover or NTP mode. The new mode is selected by the small drop-down box on the System tab.
        * You can find full instructions in the [RTK Everywhere Product Manual](https://docs.sparkfun.com/SparkFun_RTK_Everywhere_Firmware/menu_ethernet/).
    * **Cfg WiFi**
        * Abbreviated as "CfgWiFi", Configure-Via-WiFi mode is another dedicated mode where the RTK EVK can be configured via a web page over WiFi.
        * By default, the RTK EVK will appear as a WiFi Hot Spot / Access Point - but it can be configured to connect to your preferred WiFi network too.
        * The RTK EVK will reboot when leaving this mode - to apply any changes made.
        * You can find full instructions in the [RTK Everywhere Product Manual](https://docs.sparkfun.com/SparkFun_RTK_Everywhere_Firmware/menu_wifi/)** (Configure-Via-WiFi)
    * **Get Keys**
        * When there is an Ethernet or WiFi connection, the RTK EVK can access the PointPerfect system and automatically obtain keys to allow the decryption of corrections.
        * More details are provided in the [RTK Everywhere Product Manual](https://docs.sparkfun.com/SparkFun_RTK_Everywhere_Firmware/menu_pointperfect/)
    * **E-Pair** (ESP NOW Pairing)
        * Abbreviated as "E-Pair", ESP NOW is a way of linking two ESP32 processors via WiFi so that they can communicate with each other, line of sight up to approximately 250m.
        * The ESP NOW link allows a base to share correction data with a single rover.
        * More details are provided in the [RTK Everywhere Product Manual](https://docs.sparkfun.com/SparkFun_RTK_Everywhere_Firmware/menu_radios/)

    <div style="text-align: center;">
      <table>
        <tr style="vertical-align:middle;">
         <td style="text-align: center; vertical-align: middle; border: solid 1px #cccccc;"><a href="../assets/img/24342-RTK-EVK-Action-Screen_GIF_750ms.gif"><img src="../assets/img/24342-RTK-EVK-Action-Screen_GIF_750ms.gif" width="600px" height="600px" alt=OLED Cycling Through Modes"></a></td>
        </tr>
        <tr style="vertical-align:middle;">
         <td style="text-align: center; vertical-align: middle; border: solid 1px #cccccc;"><i>OLED Display Cycling Through Modes</i></td>
        </tr>
      </table>
    </div>

* **Bootloader Mode** &mdash; The boot button usually allows users to force the ESP32 into bootloader mode to manually upload new code to the ESP32.

### LEDs

There are three LEDs available:

* **STATUS** &mdash; The built-in STATUS LED is used to indicate when the BASE mode has completed its survey-in.
* **LINK** &mdash; The built-in LINK LED on the RJ45 MagJack connector is connected to the WIZnet 5500&apos;s LINKLED pin and is used to indicate when there is a Ethernet Link.
* **ACT** &mdash; The built-in ACT LED on the RJ45 MagJack connector is connected to the WIZnet 5500&apos;s ACTLED pin and used to indicate when there is Ethernet activity.

<div style="text-align: center;">
  <table>
    <tr style="vertical-align:middle;">
     <td style="text-align: center; vertical-align: middle; border: solid 1px #cccccc;"><a href="../assets/img/24342-RTK-EVK-High-Precision-GNSS-Front_LED.jpg">LEDs on Ethernet Connector</a></td>
     <td style="text-align: center; vertical-align: middle; border: solid 1px #cccccc;"><a href="../assets/img/24342-RTK-EVK-High-Precision-GNSS-Back_Ethernet_LEDs.jpg">LEDs on Ethernet Connector</a></td>
    </tr>
    <tr style="vertical-align:middle;">
     <td style="text-align: center; vertical-align: middle; border: solid 1px #cccccc;"><i>LED Highlighted</i></td>
     <td style="text-align: center; vertical-align: middle; border: solid 1px #cccccc;"><i>LEDs on Ethernet Connector Highlighted</i></td>
    </tr>
  </table>
</div>

### Jumpers

!!!note
    If this is your first time working with jumpers, check out the [How to Work with Jumper Pads and PCB Traces](https://learn.sparkfun.com/tutorials/how-to-work-with-jumper-pads-and-pcb-traces/all) tutorial for more information.

The RTK EVK includes various jumpers on the back of the PCB.

* **SHLD** &mdash; There are two jumpers labeled as SHLD on the back of the PCB. These jumpers connect the USB Type C connector's shield pin to GND. By default, these are closed. Cut this to isolate the USB Type C connector's shield pin for the ESP32 and the ZED-F9P.
* **MEAS** &mdash; To enable measurements and determine how much power the RTK EVK uses, we've added a NC (normally closed) jumper between the two MEAS PTH pins. By cutting this jumper, the voltage connecting to the 3.3V voltage regulator input is interrupted. Soldering in a male jumper or wires into the accompanying holes will give you the ability to insert a current meter and precisely monitor how much current your application is consuming.
* **VIN+** &mdash; The VIN+ jumper connects the I/O Screw Terminal to the 5V DC-DC converter's VIN+ pin. This is closed by default. Cut this trace to disable the connection.
* **VIN-** &mdash; The VIN- jumper connects the I/O Screw Terminal to the 5V DC-DC converter's VIN- pin. This is closed by default. Cut this trace to disable the connection.
* **PW+** &mdash; The PW+ jumper connects the RJ45 MagJack's PW+ pin to the DP9905 PoE's VIN+ pin. This is closed by default. Cut this trace to disable the connection.
* **PW-** &mdash; The PW- jumper connects the RJ45 MagJack's PW- pin to the DP9905 PoE's VIN- pin. This is closed by default. Cut this trace to disable the connection.
* <b><span STYLE="text-decoration:overline">GNSS Reset</span></b> &mdash; The GNSS reset jumper is open by default. Adding a solder blob will connect the reset button (which is currently only connected to the ESP32's reset pin) to the reset pins on both the ZED-F9P and NEO-D9S. Pulling the pin low by pressing the button will initiate a reset on the ZED-F9P and NEO-D9S. This will delete all information and trigger a cold start. As stated in the integration manual, this should only be used as a recovery option. Compared to the other jumpers, this jumper includes a 1x2 PTH. Users can also break off a [1x2 standard male header](https://www.sparkfun.com/products/116) and temporarily connect a [1x2 jumper](https://www.sparkfun.com/products/9044).
* **I<sup>2</sup>C** &mdash; This three way jumper labeled <code>I<sup>2</sup>C</code> will connect to two pull-up resistors to the I<sup>2</sup>C data and clock lines when closed. For advanced users that do not have pull-up resistors attached to the I<sup>2</sup>C lines on their microcontroller, make sure to close the jumpers with a little solder blob.
* **POE LOAD** &mdash; The POE LOAD creates a dummy load of 100mA on the DC/DC converter output. This is closed by default. Cut this trace to disable the dummy load.
* **WIZnet W5500 Mode Jumper** &mdash; For users that want to configure the WIZnet W5500 mode, there are three jumpers available to adjust the network mode. By default, the jumpers are set to 111 or "All capable, Auto-negotiation." For more information on the different modes, check out the WIZnet 5500 datasheet linked in the Resources.
    * **PMODE0** &mdash; Pulled high. Add as solder jumper to pull the pin low.
    * **PMODE1** &mdash; Pulled high. Add as solder jumper to pull the pin low.
    * **PMODE2** &mdash; Pulled high. Add as solder jumper to pull the pin low.
* **LED** &mdash; The LED jumper connects the status LED to the ESP32&apos;s pin 2. This is closed by default. Cut this trace to disable the status LED.
* **LINK** &mdash; The LINK jumper connects the RJ45 Link LED to the WIZnet 5500 LINKLED pin. This is closed by default. Cut this trace to disable the RJ45&apos;s Link LED.
* **ACT** &mdash;  The ACT jumper connects the RJ45 Activity LED to the WIZnet 5500 ACTLED pin. This is closed by default. Cut this trace to disable the RJ45&apos;s Link LED.
* **3V3 SW EN** &mdash; This three way jumper labeled **3V3 SW EN** enables the XC6222 3.3V/700mA voltage regulator for the RTK EVK's secondary power to provide power for the RJ45 MagJack LEDs, W5500, ZED-F9P, NEO-D9S, USB Hub, and Qwiic OLED.  By default, the trace is pulled high. Cut the trace and add a solder blob between the center pad and the other jumper to allow the ESP32 to toggle power using pin 32.
* **3V3 SW2 EN** &mdash; This three way jumper labeled **3V3 SW2 EN** enables the AP7361C 3.3V/1A voltage regulator for the RTK EVK's tertiary power to provide power for the LARA-R6. By default, the trace is pulled high. Cut the trace and add a solder blob between the center pad and the other jumper to allow the ESP32 to toggle power using pin 32.

<div style="text-align: center;">
  <table>
    <tr style="vertical-align:middle;">
     <td style="text-align: center; vertical-align: middle; border: solid 1px #cccccc;"><a href="../assets/img/24342-RTK-EVK-Board-Back_Jumpers-hi_res.jpg">Jumpers</a></td>
    </tr>
    <tr style="vertical-align:middle;">
     <td style="text-align: center; vertical-align: middle; border: solid 1px #cccccc;"><i>Jumpers</i></td>
    </tr>
  </table>
</div>

### Dimensions

The SparkFun RTK EVK is designed around the [Metal Enclosure - Custom Aluminum Extrusion (6in. x 4in. PCB)](https://www.sparkfun.com/products/22640). You can find the dimensions of the enclosure below.

<div style="text-align: center;">
  <table>
    <tr style="vertical-align:middle;">
     <td style="text-align: center; vertical-align: middle; border: solid 1px #cccccc;"><a href="../assets/img/RTK_EVK_Enclosure_Dimensions.jpg">Enclosure and Panel Dimensions</a></td>
    </tr>
    <tr style="vertical-align:middle;">
     <td style="text-align: center; vertical-align: middle; border: solid 1px #cccccc;"><i>Enclosure and Panel Dimensions</i></td>
    </tr>
  </table>
</div>

Within the enclosure is the RTK EVK PCB. You can find the board dimensions below.

<div style="text-align: center;">
  <table>
    <tr style="vertical-align:middle;">
     <td style="text-align: center; vertical-align: middle; border: solid 1px #cccccc;"><a href="../assets/img/24342_RTK_EVK_Board_Dimensions.png">Board Dimensions</a></td>
    </tr>
    <tr style="vertical-align:middle;">
     <td style="text-align: center; vertical-align: middle; border: solid 1px #cccccc;"><i>Board Dimensions</i></td>
    </tr>
  </table>
</div>

For users interested in the dimensions of the surveying antenna, it is also listed below from the [SPK6618H datasheet](https://cdn.sparkfun.com/assets/f/f/5/1/7/SparkFun_SPK6618H_Datasheet.pdf).

<div style="text-align: center;">
  <table>
    <tr style="vertical-align:middle;">
     <td style="text-align: center; vertical-align: middle; border: solid 1px #cccccc;"><a href="../assets/img/21801-Dimensional_Drawing_RTK_Mult-Band_Surveying_Antenna.jpg">SPK6618H Surveying Antenna Dimensions</a></td>
    </tr>
    <tr style="vertical-align:middle;">
     <td style="text-align: center; vertical-align: middle; border: solid 1px #cccccc;"><i>SPK6618H Surveying Antenna Dimensions</i></td>
    </tr>
  </table>
</div>

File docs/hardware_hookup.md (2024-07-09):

In this section, we'll go over how to connect to the SparkFun RTK EVK.

### Cellular Antenna

To take advantage of the LTE cellular network with the LARA-R6, you will need to connect to the two LTE antennas on the back panel. Insert the LTE Hinged External Antenna into the SMA connector labeled as **Cell 1** and rotate the threaded connector until it is finger tight. Repeat for the other SMA connector labeled as **Cell 2**. You will need to adjust the antenna as necessary depending on where you mount the RTK EVK.

<div style="text-align: center;">
  <table>
    <tr style="vertical-align:middle;">
     <td style="text-align: center; vertical-align: middle; border: solid 1px #cccccc;"><a href="../assets/img/24342-RTK-EVK-High-Precision-GNSS-Back_Cellular_Antenna_Connectors.jpg">LTE Cellular Antennas Ports Highlighted</a></td>
     <td style="text-align: center; vertical-align: middle; border: solid 1px #cccccc;"><a href="../assets/img/16432-698MHz-2.7GHz_LTE_Hinged_External_Antenna__with_SMA_Male_Connector-01.jpg">LTE Cellular Antennas Connected</a></td>
    </tr>
    <tr style="vertical-align:middle;">
     <td style="text-align: center; vertical-align: middle; border: solid 1px #cccccc;"><i>LTE Cellular Antenna</i></td>
     <td style="text-align: center; vertical-align: middle; border: solid 1px #cccccc;"><i>LTE Cellular Antenna Ports Highlighted</i></td>
    </tr>
  </table>
</div>

### Multi-Band GNSS Antenna

Of course, you will need to connect an active multi-band GNSS antenna to the RTK EVK. We recommend using the L1/L2/L5 Surveying Antenna (SPK6618H) that is included with the kit. This covers the L1 and L2 band for the ZED-F9P. This also includes a built-in ground plane to provide the best performance for GNSS. This antenna will also provide broad coverage of the L-Band for the correction signals. Insert the SMA connector from the interface cable to the SMA connector labeled as **GNSS**. Tighten the hex nut until it is finger tight. Connect the TNC connector side from the interface cable to the to the SPK6618H antenna. Tighten the threaded connector until it is finger tight.

<div style="text-align: center;">
  <table>
    <tr style="vertical-align:middle;">
     <td style="text-align: center; vertical-align: middle; border: solid 1px #cccccc;"><a href="../assets/img/24342-RTK-EVK-High-Precision-GNSS-Back_GNSS_Antenna_Connector.jpg">Cable and Survey Antenna Connected</a></td>
     <td style="text-align: center; vertical-align: middle; border: solid 1px #cccccc;"><a href="../assets/img/SparkFun_Reinforced_Interface_Cable_-_SMA_Male_to_TNC_Male_-_1.jpg">Cable</a></td>
     <td style="text-align: center; vertical-align: middle; border: solid 1px #cccccc;"><a href="../assets/img/SparkFun_GNSS_SPK6618H_Triband_Antenna_-_2.jpg">Survey Antenna</a></td>
    </tr>
    <tr style="vertical-align:middle;">
     <td style="text-align: center; vertical-align: middle; border: solid 1px #cccccc;"><i>GNSS Antenna Port Highlighted</i></td>
     <td style="text-align: center; vertical-align: middle; border: solid 1px #cccccc;"><i>Cable</i></td>
     <td style="text-align: center; vertical-align: middle; border: solid 1px #cccccc;"><i>Survey Antenna</i></td>
    </tr>
  </table>
</div>

You will need to mount the antenna in an area where it gest the best view of the sky (we recommend the roof). There is mounting hardware where you can permanently mount the antenna to a structure or support. There is also a magnetic mount to attach to a metal structure as well. For the scope of this tutorial, we will not go over the details of installing the antenna.

<div style="text-align: center;">
  <table>
    <tr style="vertical-align:middle;">
     <td style="text-align: center; vertical-align: middle; border: solid 1px #cccccc;"><a href="../assets/img/assembly-gnss-mount_location.jpg">Cable and Survey Antenna Connected</a></td>
    </tr>
    <tr style="vertical-align:middle;">
     <td style="text-align: center; vertical-align: middle; border: solid 1px #cccccc;"><i>Cable Connected and Survey Antenna Mounted on Magnetic Stand</i></td>
    </tr>
  </table>
</div>

### WiFi/Bluetooth Antenna

For WiFi and Bluetooth using the ESP32, you will need to connect the 2.4GHz Duck Antenna to the RPSMA connector labeled as **ESP32**. Insert the antenna into the RPSMA connector and tighten the threaded connector until it is finger tight.

<div style="text-align: center;">
  <table>
    <tr style="vertical-align:middle;">
     <td style="text-align: center; vertical-align: middle; border: solid 1px #cccccc;"><a href="../assets/img/24342-RTK-EVK-High-Precision-GNSS-Back_WiFI_Antenna_Connector.jpg"><img src="../assets/img/24342-RTK-EVK-High-Precision-GNSS-Back_WiFI_Antenna_Connector.jpg" width="600px" height="600px" alt="""></a></td>
    <td style="text-align: center; vertical-align: middle; border: solid 1px #cccccc;"><a href="../assets/img/00145-02-L.jpg">WiFi/Bluetooth Antenna</a></td>
   </tr>
    <tr style="vertical-align:middle;">
     <td style="text-align: center; vertical-align: middle; border: solid 1px #cccccc;"><i>WiFi/Bluetooth Connector Highlighted</i></td>
     <td style="text-align: center; vertical-align: middle; border: solid 1px #cccccc;"><i>WiFi/Bluetooth Antenna</i></td>
    </tr>
  </table>
</div>

!!! note
    For users that need an extension cable to mount the antenna to a location that is farther away from the RTK EVK, you could use the [Interface Cable - RP-SMA Male to RP-SMA Female (10M, RG58)](https://www.sparkfun.com/products/22038).

### Ethernet

For users that are connecting Ethernet or using power from the PoE, you will need to connect the Ethernet cable between the RTK EVK and your PoE network switch. Insert the Ethernet cable to the RJ45 MagJack connector until you hear a click. Then insert the other end into the network switch.

<div style="text-align: center;">
  <table>
    <tr style="vertical-align:middle;">
     <td style="text-align: center; vertical-align: middle; border: solid 1px #cccccc;"><a href="../assets/img/24342-RTK-EVK-High-Precision-GNSS-Back_Ethernet_LEDs.jpg">Ethernet Port Highlighted</a></td>
     <td style="text-align: center; vertical-align: middle; border: solid 1px #cccccc;"><a href="../assets/img/08915-03.jpg">Ethernet Cable</a></td>
    </tr>
    <tr style="vertical-align:middle;">
     <td style="text-align: center; vertical-align: middle; border: solid 1px #cccccc;"><i>Ethernet Port Highlighted</i></td>
     <td style="text-align: center; vertical-align: middle; border: solid 1px #cccccc;"><i>Ethernet Cable</i></td>
    </tr>
  </table>
</div>

### Connecting to the ESP32

You can connect to the ESP32 by inserting the USB-C connector into the port labeled as **CONFIG ESP32** and inserting the other end of the cable to your computer's USB port. This will power the RTK EVK, allow you to upload custom code, manually update the firmware binaries, or connect to a serial terminal.

<div style="text-align: center;">
  <table>
    <tr style="vertical-align:middle;">
     <td style="text-align: center; vertical-align: middle; border: solid 1px #cccccc;"><a href="../assets/img/24342-RTK-EVK-High-Precision-GNSS-Front_USB_ESP32.jpg">USB CONFIG ESP32 Port Highlighted</a></td>
     <td style="text-align: center; vertical-align: middle; border: solid 1px #cccccc;"><a href="../assets/img/15424-Reversible_USB_A_to_C_Cable_-_2m-01.jpg">USB C Cable</a></td>
    </tr>
    <tr style="vertical-align:middle;">
     <td style="text-align: center; vertical-align: middle; border: solid 1px #cccccc;"><i>USB CONFIG ESP32 Port Highlighted</i></td>
     <td style="text-align: center; vertical-align: middle; border: solid 1px #cccccc;"><i>USB C Cable</i></td>
    </tr>
  </table>
</div>

### Connecting to the u-blox Modules

You can connect to the ZED-F9P, NEO-D9S, or LARA-R6 by inserting the USB-C connector into the port labeled as **CONFIG UBLOX** and inserting the other end to your computer's USB port.  This will power the RTK EVK and allow you to connect the modules to u-center or m-center (for the LARA-R6).

<div style="text-align: center;">
  <table>
    <tr style="vertical-align:middle;">
     <td style="text-align: center; vertical-align: middle; border: solid 1px #cccccc;"><a href="../assets/img/24342-RTK-EVK-High-Precision-GNSS-Front_USB_ublox.jpg">USB CONFIG ESP32 Port Highlighted</a></td><td style="text-align: center; vertical-align: middle; border: solid 1px #cccccc;"><a href="../assets/img/15424-Reversible_USB_A_to_C_Cable_-_2m-01.jpg">USB C Cable</a></td>
    </tr>
    <tr style="vertical-align:middle;">
     <td style="text-align: center; vertical-align: middle; border: solid 1px #cccccc;"><i>USB CONFIG ESP32 Port Highlighted</i></td>
     <td style="text-align: center; vertical-align: middle; border: solid 1px #cccccc;"><i>USB C Cable</i></td>
    </tr>
  </table>
</div>

### Inserting a MicroSD Card

To insert a microSD card, slide the microSD card into the microSD socket until it clicks in place. Pushing the microSD card again will eject the memory card.

<div style="text-align: center;">
  <table>
    <tr style="vertical-align:middle;">
     <td style="text-align: center; vertical-align: middle; border: solid 1px #cccccc;"><a href="../assets/img/24342-RTK-EVK-High-Precision-GNSS-Front_MicroSD_Card_Slot.jpg">MicroSD Card Port Highlighted</a></td>
     <td style="text-align: center; vertical-align: middle; border: solid 1px #cccccc;"><a href="../assets/img/19041-microSD_Card_-_32GB__Class_10_-02.jpg">MicroSD Card Port Highlighted</a></td>
    </tr>
    <tr style="vertical-align:middle;">
     <td style="text-align: center; vertical-align: middle; border: solid 1px #cccccc;"><i>MicroSD Card Port Highlighted</i></td>
     <td style="text-align: center; vertical-align: middle; border: solid 1px #cccccc;"><i>MicroSD Card</i></td>
    </tr>
  </table>
</div>

### Inserting a Nano SIM Card

!!!note
    ####Activate Your Hologram SIM
    If you're using a SIM card from Hologram, you'll need to follow a few quick steps to activate your SIM card.
    <ol>
      <li><a href="https://dashboard.hologram.io/">Log in</a> to your Hologram account, or <a href="https://dashboard.hologram.io/account/register">create one</a>.</li>
      <li>Click the blue <strong>+ Activate SIM</strong> button in the upper-right-corner of your Dashboard.</li>
      <br>
      <p style="text-align:center;"> <a href="https://cdn.sparkfun.com/assets/learn_tutorials/8/1/6/hologram-activate-sim.png">Activate hologram SIM</a></p>
      <br>
      <li>Select your plan – in most cases “Maker Flexible” is the way to go, but you can upgrade.</li>
      <li>Enter your SIM card’s CCID. This number can be found printed on both your nano-SIM card and in the larger digits below the bar code. Then select continue.</li>
      <li>Next you can decide whether to enable auto-refill or not and continue. Finally, you’ll be greeted with a summary page – hit “Activate” and you’re ready to go!</li>
    </ol>
    <p>For more help activating your Hologram SIM card, check out their <a  href="https://hologram.io/docs/guide/connect/connect-device/">Connect Your Device</a> documentation.</p>

To take advantage of the LARA-R6, insert the nano SIM card into the nano SIM socket until it clicks. In this case, we used a [Hologram card](https://www.sparkfun.com/products/17117). Insert the SIM with the contacts facing down, insert the edge with the chamfered corner first.

<div style="text-align: center;">
  <table>
    <tr style="vertical-align:middle;">
     <td style="text-align: center; vertical-align: middle; border: solid 1px #cccccc;"><a href="../assets/img/24342-RTK-EVK-High-Precision-GNSS-Front_Nano_SIM_Card_Slot.jpg">Nano SIM Card Socket Highlighted</a></td>
     <td style="text-align: center; vertical-align: middle; border: solid 1px #cccccc;"><a href="../assets/img/17117-Hologram_eUICC_SIM_Card-01.jpg">Nano SIM Card Socket Highlighted</a></td>
    </tr>
    <tr style="vertical-align:middle;">
     <td style="text-align: center; vertical-align: middle; border: solid 1px #cccccc;"><i>Nano SIM Card Socket Highlighted</i></td>
     <td style="text-align: center; vertical-align: middle; border: solid 1px #cccccc;"><i>Nano SIM Card</i></td>
    </tr>
  </table>
</div>

!!!note
    You will need to remove the nano SIM card from the 3-in-1 SIM card holder when you initially receive the Hologram card. Just "punch" out the pre-cut nano SIM card size out by pushing it out with your fingers. Make sure to avoid touching the gold contacts with your bare hands.

### Inserting a Wire into the I/O Screw Terminal

To connect to a pin on the screw terminal block, insert a [stripped wire of any length](https://learn.sparkfun.com/tutorials/working-with-wire/how-to-strip-a-wire) into the I/O screw terminal. Of course, you could use jumper wires with pins as well. Secure the wire by tightening the screw using a precision 2.5mm flathead screw driver. Test the connection by gently pulling the wires to ensure that they are secure.

<div style="text-align: center;">
  <table>
    <tr style="vertical-align:middle;">
     <td style="text-align: center; vertical-align: middle; border: solid 1px #cccccc;"><a href="../assets/img/24342-RTK-EVK_Screw_Terminal_Wire.jpg">Wire Inserted into I/O and Screw Being Tightened</a></td>
    </tr>
    <tr style="vertical-align:middle;">
     <td style="text-align: center; vertical-align: middle; border: solid 1px #cccccc;"><i>Wire Inserted into I/O and Screw Being Tightened</i></td>
    </tr>
  </table>
</div>

If necessary, users can remove the terminal block off by wiggling the connector or using a spudger. When ready, users can slide the I/O terminal block back into the socket.

<div style="text-align: center;">
  <table>
    <tr style="vertical-align:middle;">
     <td style="text-align: center; vertical-align: middle; border: solid 1px #cccccc;"><a href="../assets/img/24342-RTK-EVK-Removing_IO_Screw_Terminal_Block.jpg">I/O Screw Terminal Block Removed</a></td>
    </tr>
    <tr style="vertical-align:middle;">
     <td style="text-align: center; vertical-align: middle; border: solid 1px #cccccc;"><i>I/O Screw Terminal Block Removed</i></td>
    </tr>
  </table>
</div>

!!! tip
    Don't have spudger? A good substitute includes a flathead screw driver, plastic card, or the PCB ruler. Using a tool will make it easier to remove the I/O terminal block.

### Connecting a Radio Transceiver

Users can connect a radio transceiver to the ZED-F9P UART2 port for correction data. We recommend using a [breadboard to JST-GHR-06V cable](https://www.sparkfun.com/products/23353) to connect the SiK Telemetry Radio. Note that the cable is included with the LoRaSerial Kit.

<div class="grid cards col-4" markdown>
<!-- ----------WHITE SPACE BETWEEN PRODUCTS---------- -->
-   <a href="https://www.sparkfun.com/products/19032">
      <figure markdown>
        SiK Telemetry Radio V3 - 915MHz, 100mW
      </figure>
    </a>

    ---

    <a href="https://www.sparkfun.com/products/19032">
      <b>SiK Telemetry Radio V3 - 915MHz, 100mW</b>
      <br />
      WRL-19032
    </a>
<!-- ----------WHITE SPACE BETWEEN PRODUCTS---------- -->
-   <a href="https://www.sparkfun.com/products/20029">
      <figure markdown>
        SparkFun LoRaSerial Kit - 915MHz (Enclosed)
      </figure>
    </a>

    ---

    <a href="https://www.sparkfun.com/products/20029">
      <b>SparkFun LoRaSerial Kit - 915MHz (Enclosed)</b>
      <br />
      KIT-20029
    </a>
<!-- ----------WHITE SPACE BETWEEN PRODUCTS---------- -->
-   <a href="https://www.sparkfun.com/products/23353">
      <figure markdown>
        Breadboard to JST-GHR-06V Cable - 6-Pin x 1.25mm Pitch (For LoRaSerial)
      </figure>
    </a>

    ---

    <a href="https://www.sparkfun.com/products/23353">
      <b>Breadboard to JST-GHR-06V Cable - 6-Pin x 1.25mm Pitch (For LoRaSerial)</b>
      <br />
      CAB-23353
    </a>
<!-- ----------WHITE SPACE BETWEEN PRODUCTS---------- -->
</div>

For users with the using a telemetry radio, you will need to connect the UART pins and ground to the screw terminal block. Note that this connection is only for the serial UART connection. To power, we recommend using an external 5V voltage source since 5V is not broken out. While there is a 3V3 pin available, the voltage will not be enough to fully power the radio module. One method is connecting a micro-B USB cable and 5V USB wall adapter to the Telemetry Radio.

<div style="text-align: center;">
    <table>
        <tr>
            <th style="text-align: center; border: solid 1px #cccccc;">RTK EVK<br />UART Pinout
            </th>
            <th style="text-align: center; border: solid 1px #cccccc;">Telemetry<br />UART Pinout
            </th>
        </tr>
        <tr>        
            <td style="text-align: center; border: solid 1px #cccccc;" bgcolor="#d4edda"><font color="#000000">ZED TX2</font>
            </td>
            <td style="text-align: center; border: solid 1px #cccccc;" bgcolor="#d4edda"><font color="#000000">RX</font>
            </td>
        </tr>
        <tr>
            <td style="text-align: center; border: solid 1px #cccccc;" bgcolor="#ffdaaf"><font color="#000000">ZED RX2</font>
            <td style="text-align: center; border: solid 1px #cccccc;" bgcolor="#ffdaaf"><font color="#000000">TX</font>
            </td>
        </tr>
        <tr>
            <td style="text-align: center; border: solid 1px #cccccc;" bgcolor="#DDDDDD"><font color="#000000">GND</font>
            </td>
            <td style="text-align: center; border: solid 1px #cccccc;" bgcolor="#DDDDDD"><font color="#000000">GND</font>
            </td>
        </tr>
    </table>
</div>

For users with the LoRaSerial, you will also be connecting the UART pins and ground to the screw terminal block. To power, we also recommend using an external 5V voltage source for power such as a USB C cable and 5V USB wall adapter.

<div style="text-align: center;">
    <table>
        <tr>
            <th style="text-align: center; border: solid 1px #cccccc;">RTK EVK<br />UART Pinout
            </th>
            <th style="text-align: center; border: solid 1px #cccccc;">LoRaSerial<br />UART Pinout
            </th>
        </tr>
        <tr>        
            <td style="text-align: center; border: solid 1px #cccccc;" bgcolor="#d4edda"><font color="#000000">ZED TX2</font>
            </td>
            <td style="text-align: center; border: solid 1px #cccccc;" bgcolor="#d4edda"><font color="#000000">RXI</font>
            </td>
        </tr>
        <tr>
            <td style="text-align: center; border: solid 1px #cccccc;" bgcolor="#ffdaaf"><font color="#000000">ZED RX2</font>
            <td style="text-align: center; border: solid 1px #cccccc;" bgcolor="#ffdaaf"><font color="#000000">TXO</font>
            </td>
        </tr>
        <tr>
            <td style="text-align: center; border: solid 1px #cccccc;" bgcolor="#DDDDDD"><font color="#000000">GND</font>
            </td>
            <td style="text-align: center; border: solid 1px #cccccc;" bgcolor="#DDDDDD"><font color="#000000">GND</font>
            </td>
        </tr>
    </table>
</div>

### Connecting via PTH

There are various PTHs throughout the PCB. Most are used with the testbeds for quality control but they are available for you to connect! For temporary connections to the PTHs, you could use IC hooks to test out the pins. However, you'll need to solder headers or wires of your choice to the board for a secure connection. You can choose between [header pins and jumper wires](https://learn.sparkfun.com/tutorials/how-to-solder-through-hole-soldering/all), or [stripping wire and soldering the wire](https://learn.sparkfun.com/tutorials/working-with-wire/all) directly to the board.

<div class="grid cards col-4" markdown>

-   <a href="https://learn.sparkfun.com/tutorials/how-to-solder-through-hole-soldering/all">
      <figure markdown>
        How to Solder: Through Hole Soldering
      </figure>
    </a>

    ---

    <a href="https://learn.sparkfun.com/tutorials/how-to-solder-through-hole-soldering/all">
      <b>How to Solder: Through Hole Soldering</b>
    </a>
<!-- ----------WHITE SPACE BETWEEN GRID CARDS---------- -->

-   <a href="https://learn.sparkfun.com/tutorials/working-with-wire/all">
      <figure markdown>
        Working with Wire
      </figure>
    </a>

    ---

    <a href="https://learn.sparkfun.com/tutorials/working-with-wire/all">
      <b>Working with Wire</b>
    </a>
<!-- ----------WHITE SPACE BETWEEN GRID CARDS---------- -->
</div>

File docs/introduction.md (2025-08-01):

The [SparkFun RTK EVK (Evaluation Kit)](https://www.sparkfun.com/sparkfun-rtk-evk.html) is the perfect development platform for your fixed or mobile high-precision positioning and navigation needs. In terms of connectivity, the SparkFun RTK EVK has the lot: WiFi / BT, Ethernet and LTE cellular! We called it the EVK (Evaluation Kit) as it truly covers all the options: L1 + L2 RTK GNSS, with L-Band correction built-in if needed, running on an agile processor with memory to spare!

<div class="grid cards desc" markdown>

- <figure markdown>
    SparkFun RTK EVK (GPS-24342) (https://www.sparkfun.com/sparkfun-rtk-evk.html)
		</figure>

    <center>
    [Purchase from SparkFun :fontawesome-solid-cart-plus:{ .heart }](https://www.sparkfun.com/sparkfun-rtk-evk.html){ .md-button .md-button--primary }
    </center>

- <iframe width="560" height="315" src="https://www.youtube.com/embed/1y_HtYCKhMY?si=tVzyihl2rgQKZFzz" title="YouTube video player" frameborder="0" allow="accelerometer; autoplay; clipboard-write; encrypted-media; gyroscope; picture-in-picture; web-share" referrerpolicy="strict-origin-when-cross-origin" allowfullscreen></iframe>

</div>

In this tutorial we'll go over the hardware, assembly, and how get started with the SparkFun RTK.

### Kit Contents

The SparkFun RTK EVK comes with everything you need to get up and running. Our kit includes:

* 1x Cased GNSS Receiver
* 1x L1/L2/L5 GNSS Surveying Antenna
* 1x Reinforced RG58 TNC-SMA Cable (10m)
* 1x RPSMA WiFi / Bluetooth Antenna
* 2x SMA LTE Cellular Antennas
* 1x 32GB microSD Card (Class 10)
* 1x USB-C Power Supply (5V, 1A wall charger)
* 1x USB-C Cable (A to C, 2m)
* 1x Ethernet Cable (CAT-6, 1m)
* 1x Hologram eUICC nano-SIM card

<div style="text-align: center;">
  <table>
    <tr style="vertical-align:middle;">
     <td style="text-align: center; vertical-align: middle; border: solid 1px #cccccc;"><a href="../assets/img/24342-RTK-EVK-Kit-Contents_Cropped.jpg">SparkFun RTK EVK and Included Parts</a></td>
    </tr>
    <tr>
      <td style="text-align: center; vertical-align: middle; border: solid 1px #cccccc;"><i>What's in the Box?</i>
      </td>
    </tr>
  </table>
</div>

#### GNSS Mounting Accessories

Depending on where you are installing the SparkFun RTK EVK, you also might need some mounting accessories to mount the GNSS antenna. You will want to mount the antenna in a location with the best view to of the sky (i.e. a roof).

<div class="grid cards col-4" markdown>

<!-- ----------WHITE SPACE BETWEEN PRODUCTS---------- -->
-   <a href="https://www.sparkfun.com/products/21257">
      <figure markdown>
        GNSS Magnetic Antenna Mount - 5/8
      <br />
      GPS-21257
    </a>
<!-- ----------WHITE SPACE BETWEEN PRODUCTS---------- -->
-   <a href="https://www.sparkfun.com/products/22197">
      <figure markdown>
        GNSS Antenna Mounting Hardware Kit
      </figure>
    </a>

    ---

    <a href="https://www.sparkfun.com/products/22197">
      <b>GNSS Antenna Mounting Hardware Kit</b>
      <br />
      KIT-22197
    </a>
<!-- ----------WHITE SPACE BETWEEN PRODUCTS---------- -->
</div>

The RTK EVK comes with a custom extruded aluminum enclosure. The slotted flanges make it easy to install and secure the enclosure in many locations. If you are going to permanently install it up on a roof, you're going to need a suitable weatherproof box too. We found that the [Orbit 57095](https://www.orbitonline.com/products/gray-outdoor-timer-cabinet) - also [available from Amazon](https://www.amazon.com/Orbit-57095-Weather-Resistant-Outdoor-Mounted-Controller/dp/B000VYGMF2) - was a good one back when we put together our first [DIY GNSS Reference Station](https://learn.sparkfun.com/tutorials/how-to-build-a-diy-gnss-reference-station#mini-computer-setup-option-1).

<div class="grid cards" style="width:500px; margin: 0 auto;" markdown>
<!-- ----------WHITE SPACE BETWEEN GRID CARDS---------- -->
-   <a href="https://learn.sparkfun.com/tutorials/how-to-build-a-diy-gnss-reference-station">
      <figure markdown>
        How to Build a DIY GNSS Reference Station
      </figure>
    </a>

    ---

    <a href="https://learn.sparkfun.com/tutorials/how-to-build-a-diy-gnss-reference-station">
      <b>How to Build a DIY GNSS Reference Station</b>
    </a>
<!-- ----------WHITE SPACE BETWEEN GRID CARDS---------- -->
</div>

!!! note "AC Not Required!"
    The Orbit enclosure comes with a built-in power outlet, but you don't actually need it! The RTK EVK can be powered by Power-over-Ethernet (PoE), meaning all you really need to run up to the roof is a standard 8-core CAT-6 Ethernet cable. Choose a PoE Ethernet Switch that meets your needs. We have had good experiences with the [TP-Link TL-SG1005P](https://www.tp-link.com/us/business-networking/poe-switch/tl-sg1005p/) - available from many retailers including [Amazon](https://www.amazon.com/TP-Link-Compliant-Shielded-Optimization-TL-SG1005P/dp/B076HZFY3F).

#### GNSS Interface Cable

The following interface cables are great if say you are mounting the SparkFun RTK EVK in your home on a desk or lab bench and installing the antenna outdoors.

<div class="grid cards col-4" markdown>

<!-- ----------WHITE SPACE BETWEEN PRODUCTS---------- -->
-   <a href="https://www.sparkfun.com/products/21281">
      <figure markdown>
        Interface Cable - SMA Female to SMA Male (10m, RG58)
      </figure>
    </a>

    ---

    <a href="https://www.sparkfun.com/products/21281">
      <b>Interface Cable - SMA Female to SMA Male (10m, RG58)</b>
      <br />
      CAB-21281
    </a>
<!-- ----------WHITE SPACE BETWEEN PRODUCTS---------- -->
-   <a href="https://www.sparkfun.com/products/22038">
      <figure markdown>
        Interface Cable - RP-SMA Male to RP-SMA Female (10M, RG58)
      </figure>
    </a>

    ---

    <a href="https://www.sparkfun.com/products/22038">
      <b>Interface Cable - RP-SMA Male to RP-SMA Female (10M, RG58)</b>
      <br />
      CAB-22038
    </a>
<!-- ----------WHITE SPACE BETWEEN PRODUCTS---------- -->
</div>

#### Memory Cards

Finally, if you're going to be logging a lot of data, you might want to stock up on 32GB microSD cards too. The RTK EVK can log 'raw' GNSS data messages (RAWX and SFRBX) at 4Hz if desired. At that rate, you're logging about 10kB per second, close to 40MB per hour or 1GB per day!

<div class="grid cards" style="width:500px; margin: 0 auto;" markdown>

<!-- ----------WHITE SPACE BETWEEN PRODUCTS---------- -->
-   <a href="https://www.sparkfun.com/products/19041">
      <figure markdown>
        microSD Card - 32GB (Class 10)
      </figure>
    </a>

    ---

    <a href="https://www.sparkfun.com/products/19041">
      <b>microSD Card - 32GB (Class 10)</b>
      <br />
      COM-19041
    </a>
<!-- ----------WHITE SPACE BETWEEN PRODUCTS---------- -->
</div>

### Tools

Below are a few tools and accessories that you may need when connecting to the I/O terminal block on the back of the RTK EVK.

<div class="grid cards col-4" markdown>

<!-- ----------WHITE SPACE BETWEEN PRODUCTS---------- -->
-   <a href="https://www.sparkfun.com/products/25568">
      <figure markdown>
        iFixit Moray Driver Kit
      </figure>
    </a>

    ---

    <a href="https://www.sparkfun.com/products/25568">
      <b>iFixit Moray Driver Kit</b>
      <br />
      TOL-25568
    </a>
<!-- ----------WHITE SPACE BETWEEN PRODUCTS---------- -->
-   <a href="https://www.sparkfun.com/products/12630">
      <figure markdown>
        Wire Strippers - 30AWG (Hakko)
      </figure>
    </a>

    ---

    <a href="https://www.sparkfun.com/products/12630">
      <b>Wire Strippers - 30AWG (Hakko)</b>
      <br />
      TOL-12630
    </a>
<!-- ----------WHITE SPACE BETWEEN PRODUCTS---------- -->
-   <a href="https://www.sparkfun.com/products/11367">
      <figure markdown>
        Hook-Up Wire - Assortment (Solid Core, 22 AWG)
      </figure>
    </a>

    ---

    <a href="https://www.sparkfun.com/products/11367">
      <b>Hook-Up Wire - Assortment (Solid Core, 22 AWG)</b>
      <br />
      PRT-11367
    </a>
<!-- ----------WHITE SPACE BETWEEN PRODUCTS---------- -->
</div>

### Suggested Reading

If you aren’t familiar with the following concepts, we also recommend checking out a few of these tutorials before continuing.

<div class="grid cards col-4" markdown>
<!-- ----------WHITE SPACE BETWEEN GRID CARDS---------- -->
-   <a href="https://learn.sparkfun.com/tutorials/what-is-gps-rtk">
      <figure markdown>
        What is GPS RTK?
      </figure>
    </a>

    ---

    <a href="https://learn.sparkfun.com/tutorials/what-is-gps-rtk">
      <b>What is GPS RTK?</b>
    </a>
<!-- ----------WHITE SPACE BETWEEN GRID CARDS---------- -->
-   <a href="https://learn.sparkfun.com/tutorials/getting-started-with-u-center-for-u-blox">
      <figure markdown>
        Getting Started with U-Center for u-blox
      </figure>
    </a>

    ---

    <a href="https://learn.sparkfun.com/tutorials/getting-started-with-u-center-for-u-blox">
      <b>Getting Started with U-Center for u-blox</b>
    </a>
<!-- ----------WHITE SPACE BETWEEN GRID CARDS---------- -->
-   <a href="https://learn.sparkfun.com/tutorials/gps-rtk2-hookup-guide">
      <figure markdown>
        GPS-RTK2 Hookup Guide
      </figure>
    </a>

    ---

    <a href="https://learn.sparkfun.com/tutorials/gps-rtk2-hookup-guide">
      <b>GPS-RTK2 Hookup Guide</b>
    </a>
<!-- ----------WHITE SPACE BETWEEN GRID CARDS---------- -->
-   <a href="https://learn.sparkfun.com/tutorials/setting-up-a-rover-base-rtk-system">
      <figure markdown>
        Setting up a Rover Base RTK System
      </figure>
    </a>

    ---

    <a href="https://learn.sparkfun.com/tutorials/setting-up-a-rover-base-rtk-system">
      <b>Setting up a Rover Base RTK System</b>
    </a>
<!-- ----------WHITE SPACE BETWEEN GRID CARDS---------- -->
-   <a href="https://learn.sparkfun.com/tutorials/how-to-build-a-diy-gnss-reference-station">
      <figure markdown>
        How to Build a DIY GNSS Reference Station
      </figure>
    </a>

    ---

    <a href="https://learn.sparkfun.com/tutorials/how-to-build-a-diy-gnss-reference-station">
      <b>How to Build a DIY GNSS Reference Station</b>
    </a>
<!-- ----------WHITE SPACE BETWEEN GRID CARDS---------- -->
</div>

You may also be interested in the following blog posts on GNSS technologies.

<div class="grid cards col-4" markdown align="center">

-   <a href="https://www.sparkfun.com/news/4276">
	<figure markdown>
	Tutorial Thumbnail
	</figure>

	---

	**GPS vs GNSS**</a>

-   <a href="https://www.sparkfun.com/news/7138">
	<figure markdown>
	Tutorial Thumbnail
	</figure>

	---

	**What is Correction Data?**</a>

-   <a href="https://www.sparkfun.com/news/7533">
	<figure markdown>
	Tutorial Thumbnail
	</figure>

	---

	**Real-Time Kinematics Explained**</a>

-   <a href="https://www.sparkfun.com/news/7401">
	<figure markdown>
	Tutorial Thumbnail
	</figure>

	---

	**New Video: Unlocking High-Precision RTK Positioning**</a>

</div>

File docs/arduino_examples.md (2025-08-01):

!!! arduino
    This example assumes you are using the latest version of the Arduino IDE on your desktop. If this is your first time using the Arduino IDE, library, or board add-on, please review the following tutorials.

    - [Installing the Arduino IDE](https://learn.sparkfun.com/tutorials/installing-arduino-ide)
    - [Installing Board Definitions in the Arduino IDE](https://learn.sparkfun.com/tutorials/installing-board-definitions-in-the-arduino-ide)
    - [Installing an Arduino Library](https://learn.sparkfun.com/tutorials/installing-an-arduino-library)

!!! note
    If you've never connected an CH340 device to your computer before, you may need to install drivers for the USB-to-serial converter. Check out our section on "[How to Install CH340 Drivers](https://learn.sparkfun.com/tutorials/how-to-install-ch340-drivers)" for help with the installation.

    - [How to Install CH340 Drivers](https://learn.sparkfun.com/tutorials/how-to-install-ch340-drivers/all)

Besides the 6x examples for the LARA-R6 cellular module, you will also notice several other examples such as using the ZED-F9P, NEO-D9S, Qwiic OLED, LEDs, antenna open/short circuit detection, Ethernet, WiFi, and datalogging using the microSD card. Head to the [SparkFun RTK EVK GitHub Repo](https://github.com/sparkfun/SparkFun_RTK_EVK/tree/main/Example_Sketches) to grab the files or download the .ZIP by clicking the button below.

<div style="text-align: center"><a href="https://github.com/sparkfun/SparkFun_RTK_EVK/archive/refs/heads/main.zip" target="rtk_evk_arduino_example_sketches" class="md-button">GitHub SparkFun RTK EVK Repo: Arduino Example Sketches</a></div>

For the scope of this tutorial, we will upload one of the examples to get started. After downloading the files, unzip the files and head to the following folder: **SparkFun_RTK_EVK-main** > **Example Sketches**. Let&apos;s test the connection between the ESP32-WROVER and LARA-R6 by clicking on the **8_1_LARA_UART_Test** > **8_1_LARA_UART_Test.ino**.

!!! note
    Some examples may include additional header files. You'll need to click on the example that has the same title as the folder's title. Certain examples may also require an additional Arduino Library. Make sure to check the example to see if there is a `#include` with the Arduino Library name near the top before compiling.  You may also need to update the examples to provide any secret keys, accounts, or passwords.

Then select the associated board definition (in this case the **ESP32 Wrover Module**) and COM port. With a USB C cable connected to the **CONFIG ESP32** port, click on the upload button. Opening the [Arduino Serial Terminal](https://learn.sparkfun.com/tutorials/terminal-basics/arduino-serial-monitor-windows-mac-linux) at **115200** baud, the output will provide the model and SIM card information.

!!! note
    At the time of writing, we used the following:
    <br />
    <ul>
      <li> Arduino IDE v2.3.2</li>
      <li>esp32 by Espressif v3.0.1</li>
      <li>u-blox Cellular library by SparkFun v1.0.1</li>
    </ul>

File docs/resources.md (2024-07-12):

Now that you've successfully got your SparkFun RTK EVK up and running, it's time to incorporate it into your own project! For more information, check out the resources below:

* [Schematic (PDF)](../assets/board_files/SparkFun_RTK_EVK_Schematic_v1_1.pdf)
* [Eagle Files (ZIP)](../assets/board_files/Eagle_Files-RTK_EVK_v1_1.zip)
* [Board Dimensions (PNG)](../assets/img/24342_RTK_EVK_Board_Dimensions.png)
* [Case Dimensions (ZIP)](../assets/RTK_EVK_Enclosure.zip)
* [RTK Everywhere Product Manual](https://docs.sparkfun.com/SparkFun_RTK_Everywhere_Firmware/)
* Datasheets
    * [ESP32-WROOM](../assets/component_documentation/esp32-wrover-e_esp32-wrover-ie_datasheet_en.pdf)
    * [ZED-F9P](../assets/component_documentation/ZED-F9P-02B_DataSheet_UBX-21023276.pdf)
    * [NEO-D9S](../assets/component_documentation/NEO-D9S-00B_DataSheet_UBX-18012996.pdf)
    * [LARA-R6](../assets/component_documentation/LARA-R6_DataSheet_UBX-21004391.pdf)
* Integration Manuals
    * [ZED-F9P](../assets/component_documentation/ZED-F9P_IntegrationManual_UBX-18010802.pdf)
    * [NEO-D9S](../assets/component_documentation/NEO-D9S_IntegrationManual_UBX-19026111.pdf)
    * [LARA-R6](../assets/component_documentation/LARA-R6-L6_SysIntegrManual_UBX-21010011.pdf)
* [LARA-R6 AT Commands Manual](../assets/component_documentation/LARA-R6-L6_ATCommands_UBX-21046719.pdf)
* [LARA-R6 firmware update package links and instructions](https://www.u-blox.com/sites/default/files/documents/LARA-R6-L6-01B-IP_IN_UBXDOC-686885345-1861.pdf)
    * Section 8 of the document contains links to m-center, EasyFlash and the USB driver
    * The firmware itself is available in the [u-blox documentation & resources](https://www.u-blox.com/en/product/lara-r6-series?legacy=Current#Documentation-&-resources). Be sure to select the **LARA-R6001D-01B-00**.
* [RTK Everywhere Firmware](https://github.com/sparkfun/SparkFun_RTK_Everywhere_Firmware)
* [RTK Everywhere Firmware Binaries](https://github.com/sparkfun/SparkFun_RTK_Everywhere_Firmware_Binaries)
* [Additional ESP32 Code Examples](https://github.com/sparkfun/SparkFun_RTK_EVK/tree/main/Example_Sketches)
* [GitHub Hardware Repo](https://github.com/sparkfun/SparkFun_RTK_EVK)
* [SFE Product Showcase](https://www.youtube.com/watch?v=1y_HtYCKhMY)

For user that are taking advantage of the Zero-Touch RTK for correction services, make sure to click on the link below! This link will allow you to register, reactivate, or cancel your RTK EVK's correction service.

* [SparkFun RTK EVK Correction Service Registration & Renewal](https://www.sparkfun.com/rtk_evk_registration)

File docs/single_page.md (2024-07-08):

---
hide:
  - navigation
  - toc
icon: fontawesome/solid/scroll
---

# Introduction
--8<-- "./docs/introduction.md"

# Hardware Overview
--8<-- "./docs/hardware_overview.md"

# Hardware Hookup
--8<-- "./docs/hardware_hookup.md"

# RTK Everywhere Firmware
--8<-- "./docs/product_manual.md"

# Arduino Examples
--8<-- "./docs/arduino_examples.md"

# Troubleshooting
--8<-- "./docs/troubleshooting.md"

# Resources
--8<-- "./docs/resources.md"

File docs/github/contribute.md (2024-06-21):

# Contribute: Help Fix our Mistake!
Spot something wrong? Feel free to contribute our open-source design and documentation. 

## Improve our Documentation
All of this documentation can be modified by you! Please help us make it better.

* These pages are contained in the [`docs` folder of the SparkFun RTK EVK repository](https://github.com/sparkfun/SparkFun_RTK_EVK/tree/main/docs).

### Submit a Correction
1. Fork this repo
2. Add your corrections or improvements to the markdown file
3. File a pull request with your changes, and enjoy making the ~~words~~ ~~worlds~~ world a better place.
    * Once received, the documentation specialist will automatically be notified.
    * We will review your suggested improvements to make sure they are correct and fit within our documentation standards.

## Improve our Hardware Design
All of our designs are open-source! Please help us make it better.

* Our board design files are contained in the [`Hardware` folder of the SparkFunRTK EVK Repository](https://github.com/sparkfun/SparkFun_RTK_EVK/tree/main/Hardware).

### Submit a Design Improvement
1. Fork this repo
2. Add your design improvements
3. File a pull request with your changes, and enjoy making the ~~words~~ ~~worlds~~ world a better place.
    * Once received, the engineer in charge of the original design will automatically be notified.
    * We will review your suggested improvements, if they are within our board design standards and meet our product design requirements, we will flag these changes for our next board revision. *(Please note, that even if your suggestion is accepted, these changes may not be immediate. We may have to cycle through our current product inventory first.)*

## Contributors
Let's provided some recognition to the contributors for this project!

GitHub Contributors Image
<br>


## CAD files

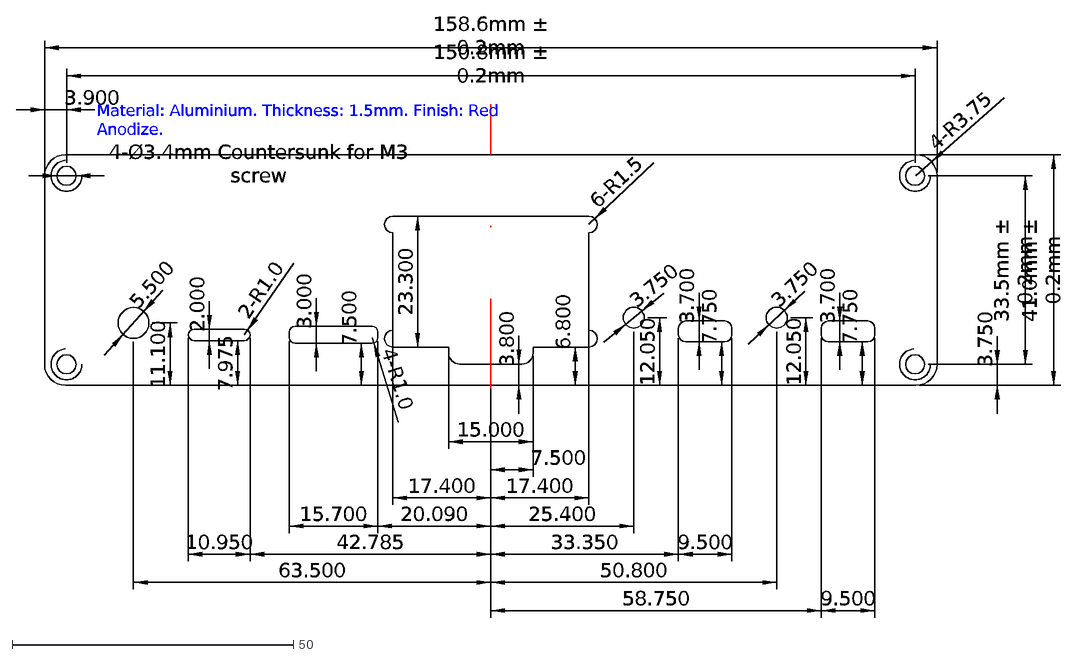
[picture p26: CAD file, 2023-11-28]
docs/assets/RTK_EVK_Enclosure/Front_Panel/RTK_EVK_Front_Panel.dxf
158.6mm ± 0.2mm
150.8mm ± 0.2mm
3.900
Material: Aluminium. Thickness: 1.5mm. Finish: Red Anodize.
3.750
33.5mm ± 0.2mm
41.0mm ± 0.2mm
4-Ø3.4mm Countersunk for M3 screw
4-R3.75
15.000
7.500
17.400
3.800
6.800
23.300
6-R1.5
33.350
9.500
58.750
25.400
50.800
12.050
7.750
3.700
20.090
15.700
3.000
4-R1.0
42.785
10.950
2-R1.0
7.975
2.000
63.500
5.500
11.100

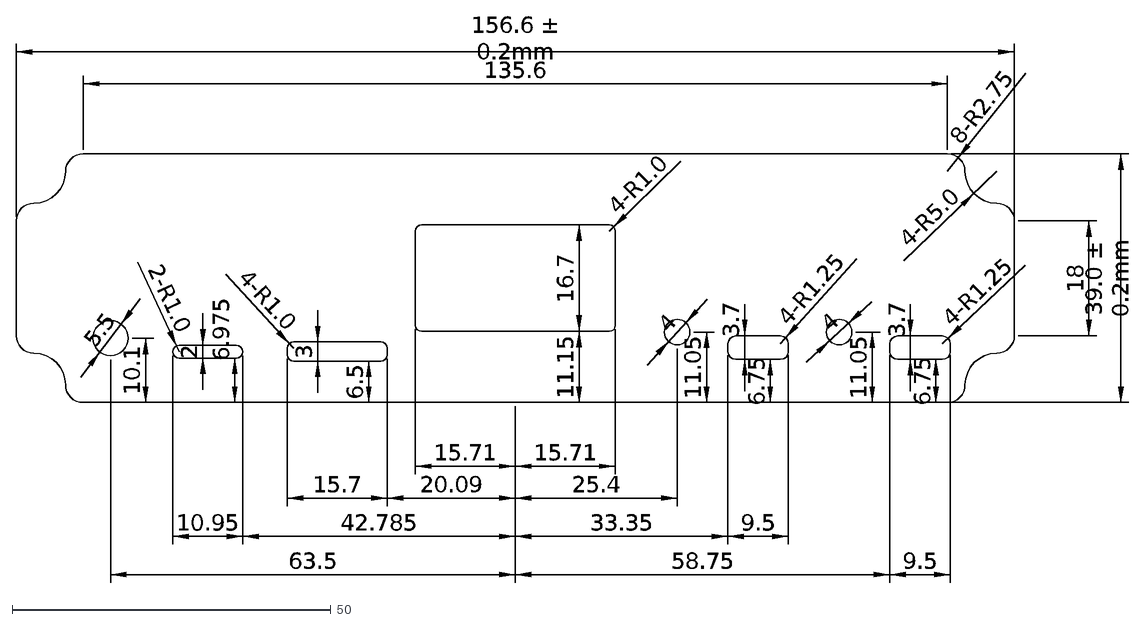
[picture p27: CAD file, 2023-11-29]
docs/assets/RTK_EVK_Enclosure/Front_Sticker/RTK_EVK_Front_Sticker_Dimensions.dxf
135.6
18
15.71
11.15
16.7
4-R1.0
25.4
11.05
33.35
9.5
58.75
6.75
3.7
4
4-R1.25
4-R5.0
8-R2.75
20.09
15.7
6.5
3
10.95
42.785
6.975
2
2-R1.0
63.5
10.1
5.5
156.6 ± 0.2mm
39.0 ± 0.2mm

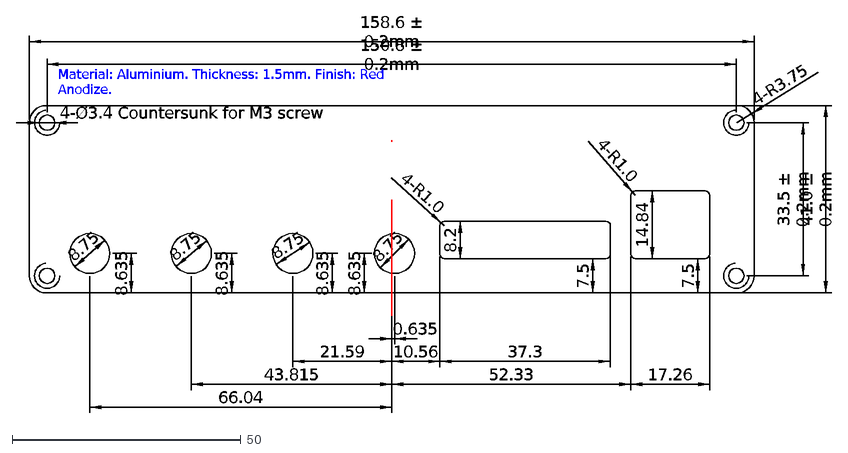
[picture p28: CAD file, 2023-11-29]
docs/assets/RTK_EVK_Enclosure/Rear_Panel/RTK_EVK_Rear_Panel.dxf
4-R3.75
158.6 ± 0.2mm
150.8 ± 0.2mm
4-Ø3.4 Countersunk for M3 screw
Material: Aluminium. Thickness: 1.5mm. Finish: Red Anodize.
33.5 ± 0.2mm
41.0 ± 0.2mm
0.635
21.59
43.815
66.04
8.635
8.75
10.56
37.3
52.33
17.26
7.5
8.2
14.84
4-R1.0

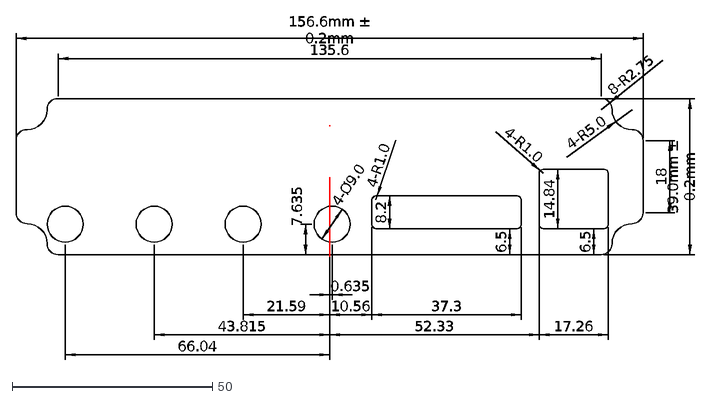
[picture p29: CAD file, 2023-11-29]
docs/assets/RTK_EVK_Enclosure/Rear_Sticker/RTK_EVK_Rear_Sticker_Dimensions.dxf
135.6
4-R5.0
8-R2.75
156.6mm ± 0.2mm
18
39.0mm ± 0.2mm
0.635
7.635
4-Ø9.0
21.59
43.815
66.04
10.56
37.3
6.5
8.2
4-R1.0
52.33
17.26
14.84

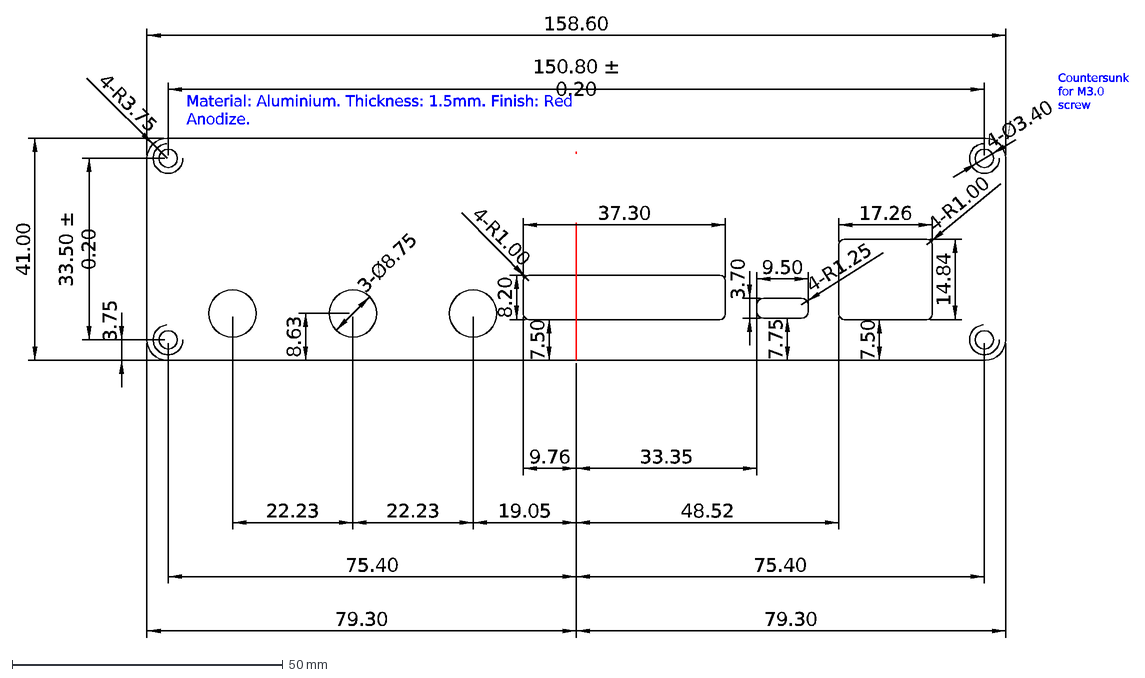
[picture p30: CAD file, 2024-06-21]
docs/assets/RTK_EVK_Enclosure/SparkFun_HF-A_Custom_Enclosure_Drawings/SparkFun_HF-A_Custom__Rear_Panel__v3.dxf
158.60
4-R3.75
150.80 ± 0.20
33.50 ± 0.20
41.00
9.76
37.30
7.50
8.20
4-R1.00
33.35
9.50
7.75
3.70
48.52
17.26
14.84
4-R1.25
19.05
22.23
8.63
79.30
75.40
3.75
3-Ø8.75
4-Ø3.40
Countersunk for M3.0 screw
Material: Aluminium. Thickness: 1.5mm. Finish: Red Anodize.

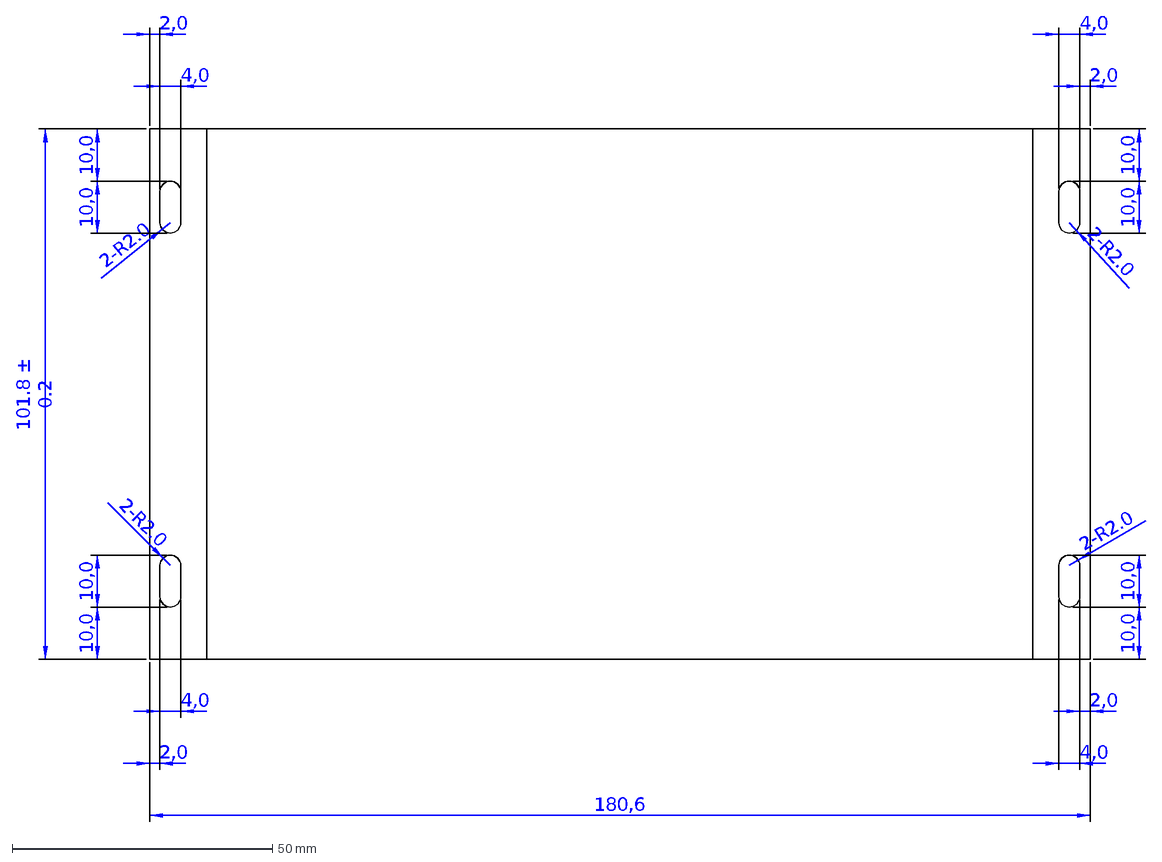
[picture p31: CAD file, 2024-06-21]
docs/assets/RTK_EVK_Enclosure/SparkFun_HF-A_Custom_Enclosure_Drawings/SparkFun_HF-A_Custom__Top_View__v3.dxf
101.8 ± 0.2
10,0
4,0
2,0
180,6
2-R2.0

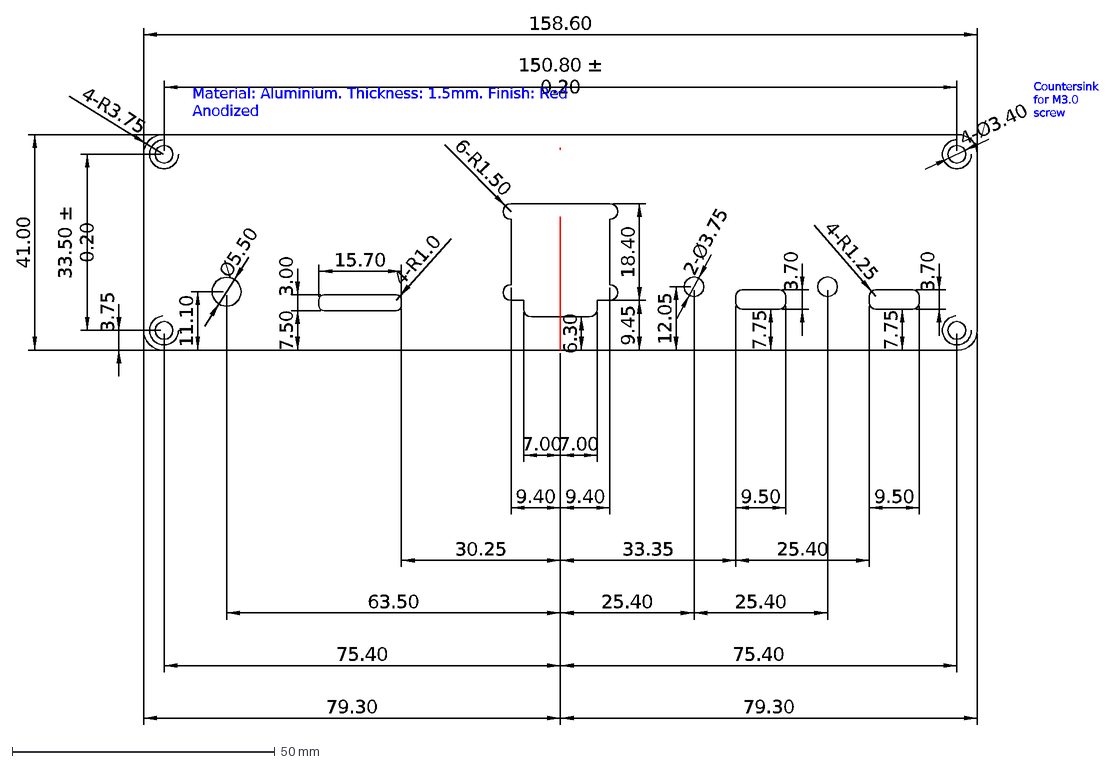
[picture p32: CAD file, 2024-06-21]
docs/assets/RTK_EVK_Enclosure/SparkFun_HF-A_Custom_Enclosure_Drawings/SparkFun_HF-A_Custom__Front_Panel__v3.dxf
41.00
158.60
4-R3.75
63.50
11.10
Ø5.50
25.40
3.00
15.70
30.25
7.50
4-R1.0
33.35
9.50
3.70
7.75
4-R1.25
12.05
2-Ø3.75
7.00
9.40
6.30
9.45
18.40
6-R1.50
4-Ø3.40
Countersink for M3.0 screw
33.50 ± 0.20
150.80 ± 0.20
3.75
75.40
79.30
Material: Aluminium. Thickness: 1.5mm. Finish: Red Anodized

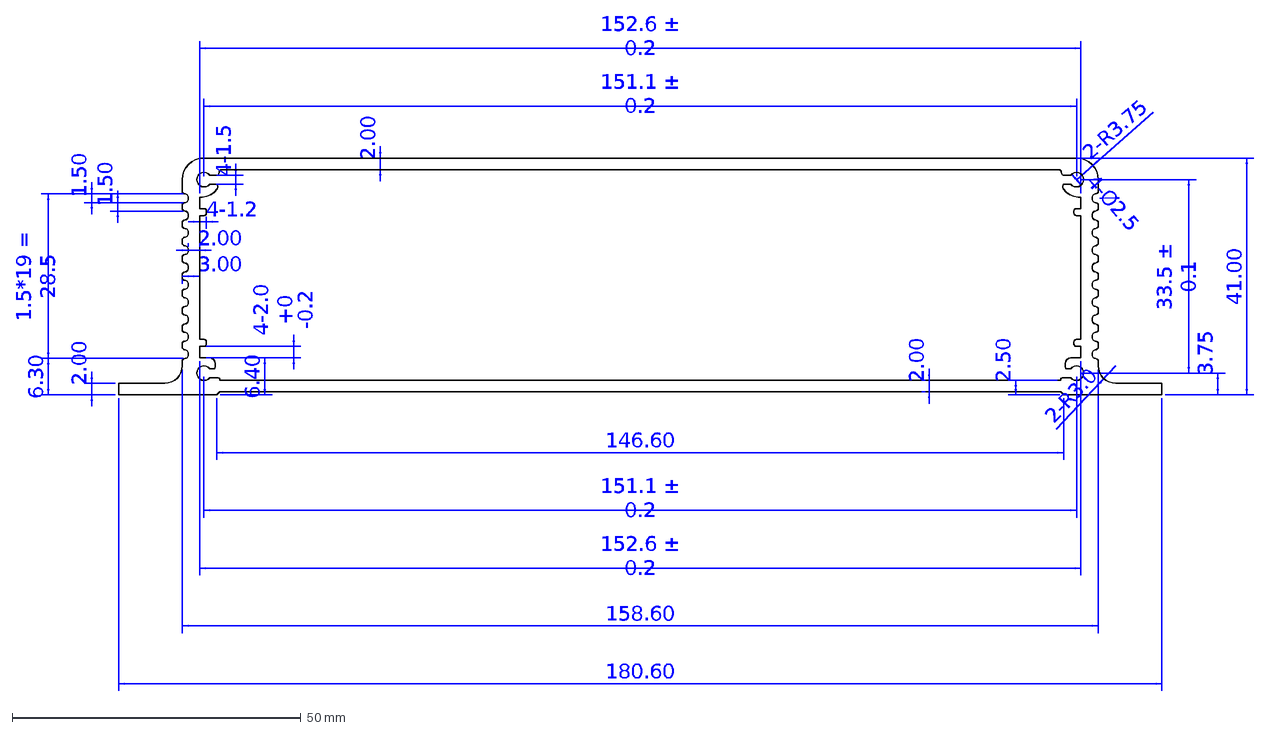
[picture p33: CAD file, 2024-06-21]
docs/assets/RTK_EVK_Enclosure/SparkFun_HF-A_Custom_Enclosure_Drawings/SparkFun_HF-A_Custom__Crossection__v3.dxf
1.5*19 = 28.5
6.30
1.50
180.60
158.60
3.00
4-1.5
4-1.2
2.00
2-R3.75
4-Ø2.5
6.40
4-2.0+0^-0.2
151.1 ± 0.2
152.6 ± 0.2
2.50
33.5 ± 0.1
3.75
41.00
146.60
2-R3.0

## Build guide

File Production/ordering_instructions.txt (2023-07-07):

panel size, 166x126mm
PCB thickness, 1.6mm
number of layers, 4
controlled impedance, JLC7628
material, TG155
soldermask color, Red
silkscreen color, White
oz copper, 1oz
finish, HASL lead free
stencils, top
pcs per panel, 1
min trace width, 0.1524mm / 0.0060in
min drill size, 0.3000mm / 0.0118in
filename to layer stackup 1/2/3/4: GTL, GL2, GL3, GBL

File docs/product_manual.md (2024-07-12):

The SparkFun RTK EVK runs on universal firmware created by SparkFun called RTK Everywhere. You can find its source through the [RTK Everywhere GitHub repo](https://github.com/sparkfun/SparkFun_RTK_Everywhere_Firmware).

<div style="text-align: center;">
  <table>
    <tr style="vertical-align:middle;">
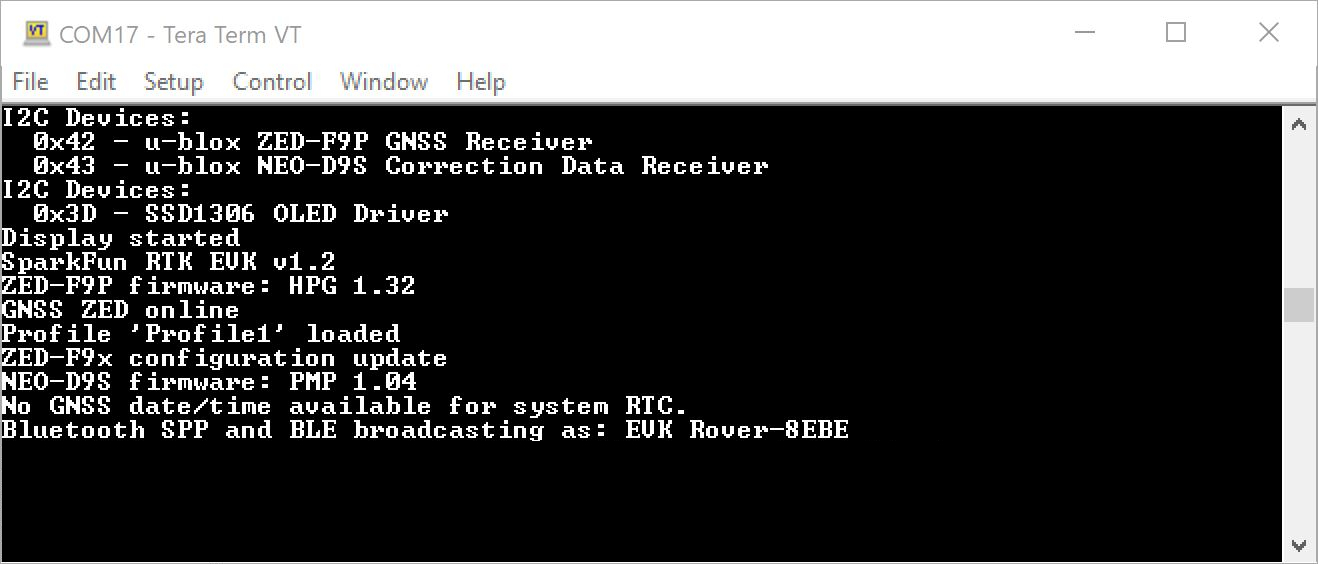
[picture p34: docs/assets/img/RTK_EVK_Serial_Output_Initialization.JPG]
Screenshot Firmware through Serial Terminal
     <td style="text-align: center; vertical-align: middle; border: solid 1px #cccccc;"></td>
    </tr>
    <tr style="vertical-align:middle;">
     <td style="text-align: center; vertical-align: middle; border: solid 1px #cccccc;"><i>Screenshot Firmware through Serial Terminal</i></td>
    </tr>
  </table>
</div>

Make sure to check out the Quick Start Guide for the RTK EVK for a summary of how to get it connected over Bluetooth. You will also find more information about navigating through the configuration menu, updating firmware, and more in the product manual!

<div style="text-align: center">
  <a href="https://docs.sparkfun.com/SparkFun_RTK_Everywhere_Firmware/quickstart-evk/" target="rtk_everywhere_product_manual" class="md-button">RTK Everywhere Product Manual: Quickstart Guide</a>
</div>

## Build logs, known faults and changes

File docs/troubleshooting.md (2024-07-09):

### General Troubleshooting Help

!!! note
    <span class="glyphicon glyphicon-question-sign" aria-hidden="true"></span>
        <strong> Not working as expected and need help? </strong> <br /><br />

    If you need technical assistance and more information on a product that is not working as you expected, we recommend heading on over to the <a href="https://www.sparkfun.com/technical_assistance">SparkFun Technical Assistance</a> page for some initial troubleshooting. <br /><br />

    <div style="text-align: center"><a href="https://www.sparkfun.com/technical_assistance" target="sfe_technical_assistance" class="md-button">SparkFun Technical Assistance Page</a></div>

    If you don't find what you need there, the <a href="https://forum.sparkfun.com/">SparkFun Forums</a> are a great place to find and ask for help. If this is your first visit, you'll need to <a href="https://forum.sparkfun.com/ucp.php?mode=register">create a Forum Account</a> to search product forums and post questions.<br /><br />

    <div style="text-align: center"><a href="https://forum.sparkfun.com/ucp.php?mode=register" class="md-button">Create New Forum Account</a>&nbsp;&nbsp;&nbsp;<a href="https://forum.sparkfun.com/viewforum.php?f=116" class="md-button md-button--primary">Log Into SparkFun Forums</a></div>

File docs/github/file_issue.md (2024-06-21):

# Did we make a mistake?

Spot something wrong? Please let us know. 

!!! attention
    This is not where customers should seek assistance on a product. If you require technical assistance or have questions about a product that is not working as expected, please head over to the [SparkFun Technical Assistance](https://www.sparkfun.com/technical_assistance) page for some initial troubleshooting.
    <center>
    [SparkFun Technical Assistance Page](https://www.sparkfun.com/technical_assistance){ .md-button .md-button--primary }
    </center>

    If you can't find what you need there, you'll need a [Forum Account](https://forum.sparkfun.com/ucp.php?mode=register) to search product forums and post questions.

## Discrepancies in the Documentation

All of this documentation can be modified by you! Please help us make it better.

* The documentation files for these pages are contained in the [`docs` folder of the SparkFun RTK EVK repository](https://github.com/sparkfun/SparkFun_RTK_EVK/tree/main/docs).

### Spot something wrong?
If a section of the documentation is incorrect, please [open an issue](https://github.com/sparkfun/SparkFun_RTK_EVK/issues) and let us know.

### Do you have a suggested correction?
1. With a GitHub account, fork this repo
2. Add your correction(s) or improvement(s) to the markdown file(s)
3. File a pull request with your changes, and enjoy making the ~~words~~ ~~worlds~~ world a better place.
    * Once received, the documentation specialist will automatically be notified.
    * We will review your suggested improvement(s) to make sure they are correct and fit within our documentation standards.

## Problems in the Hardware Design

All of our designs are open-source! Please help us make it better.

* Our board design files are contained in the [`Hardware` folder of the SparkFun RTK EVK repository](https://github.com/sparkfun/SparkFun_RTK_EVK/tree/main/Hardware).

### Does something not make sense?
If part of the design is confusing, please [open an issue](https://github.com/sparkfun/SparkFun_RTK_EVK/issues) and let us know.

### Did we forget to include an important function of the board?
* Please keep in mind that we may intentionally exclude certain functions of the board to meet our product design requirements. *(For example, our Qwiic Micro boards are intended to fit on a small board layout and only use I<sup>2</sup>C communication; therefore, we may not have the SPI and interrupt pins available for users.)*
* If part of the board's functionality is missing, please [open an issue](https://github.com/sparkfun/SparkFun_RTK_EVK/issues) and file a feature request.

### Do you wish to contribute directly to improving the board design?
1. With a GitHub account, Fork this repo
2. Add your design improvement(s)
3. File a pull request with your changes, and enjoy making the ~~words~~ ~~worlds~~ world a better place.
    * Once received, the engineer in charge of the original design will automatically be notified.
    * We will review your suggested improvement(s), if they are within our board design standards and meet our product design requirements, we will flag these changes for our next board revision. *(Please note, that even if your suggestion is accepted, these changes may not be immediate. We may have to cycle through our current product inventory first.)*

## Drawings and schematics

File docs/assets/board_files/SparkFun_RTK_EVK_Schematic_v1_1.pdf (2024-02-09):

# IOA27 12 SCK2/IOA14 13 POCI2/IOA12 14 PICO2/IOA13 16 PICO3/IO23 37 SCL/IO22 36

# TX-IO1 35 RX-IO3 34 SDA/IO21 33 POCI3/IO19 31 SCK3/IO18 30 CS3/IO5 29

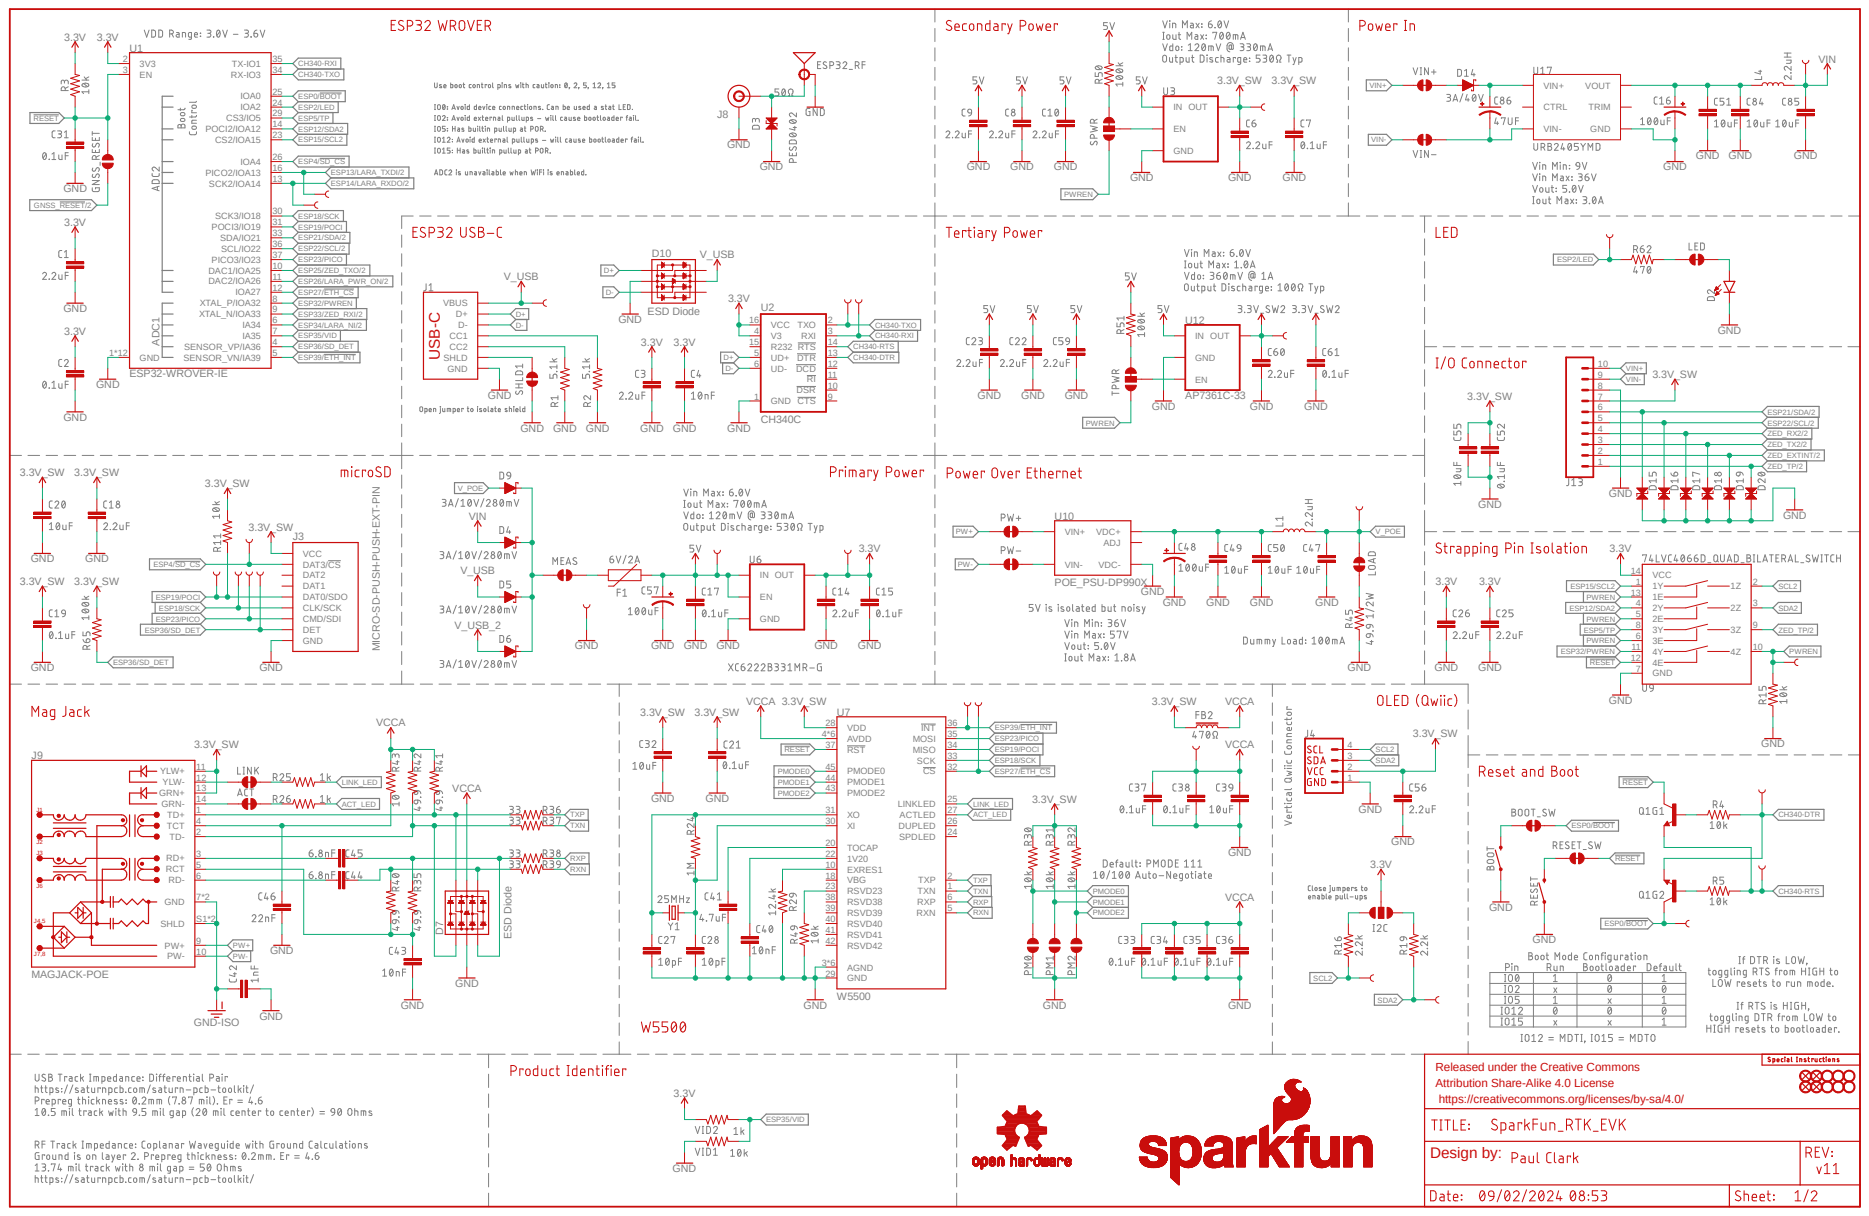
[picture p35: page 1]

DAT2 DAT1 CLK/SCK DET VCC
DAT3/CS CMD/SDI DAT0/SDO

VDC- VDC+ ADJ VIN- VIN+ U10 D⁷

U7 TD+ 1 TCT 4 TD- 2 RD+ 3 RCT 5 RD- 6 GND 7*2 SHLD S1*2 PW+ 9 PW- 10 YLW+ 11 YLW- 12 GRN+ 13 GRN- 14

TXN 1 TXP 2 RXN 5 RXP 6 EXRES1 10 AVDD 4*6 VBG 18 TOCAP 20

Released under the Creative Commons
Attribution Share-Alike 4.0 License
https://creativecommons.org/licenses/by-sa/4.0/

# VCC 51*3 GND 1*51 PWR_ON 15 RESET_N 18 VUSB_DET 17 USB_D- 28 USB_D+ 29

I2S_WA 34 I2S_TXD 35 I2S_CLK 36 I2S_RXD 37 GPIO6 19 GPIO4 25 GPIO3 24 SCL 27 SDA 26 GPIO2 23 | SIM_RST 40 SIM_CLK 38 SIM_IO 39 VSIM 41 GPIO5 42 V_INT 4 | ANT_DET 59 ANT 56 GPIO1 16 | ANT2 62

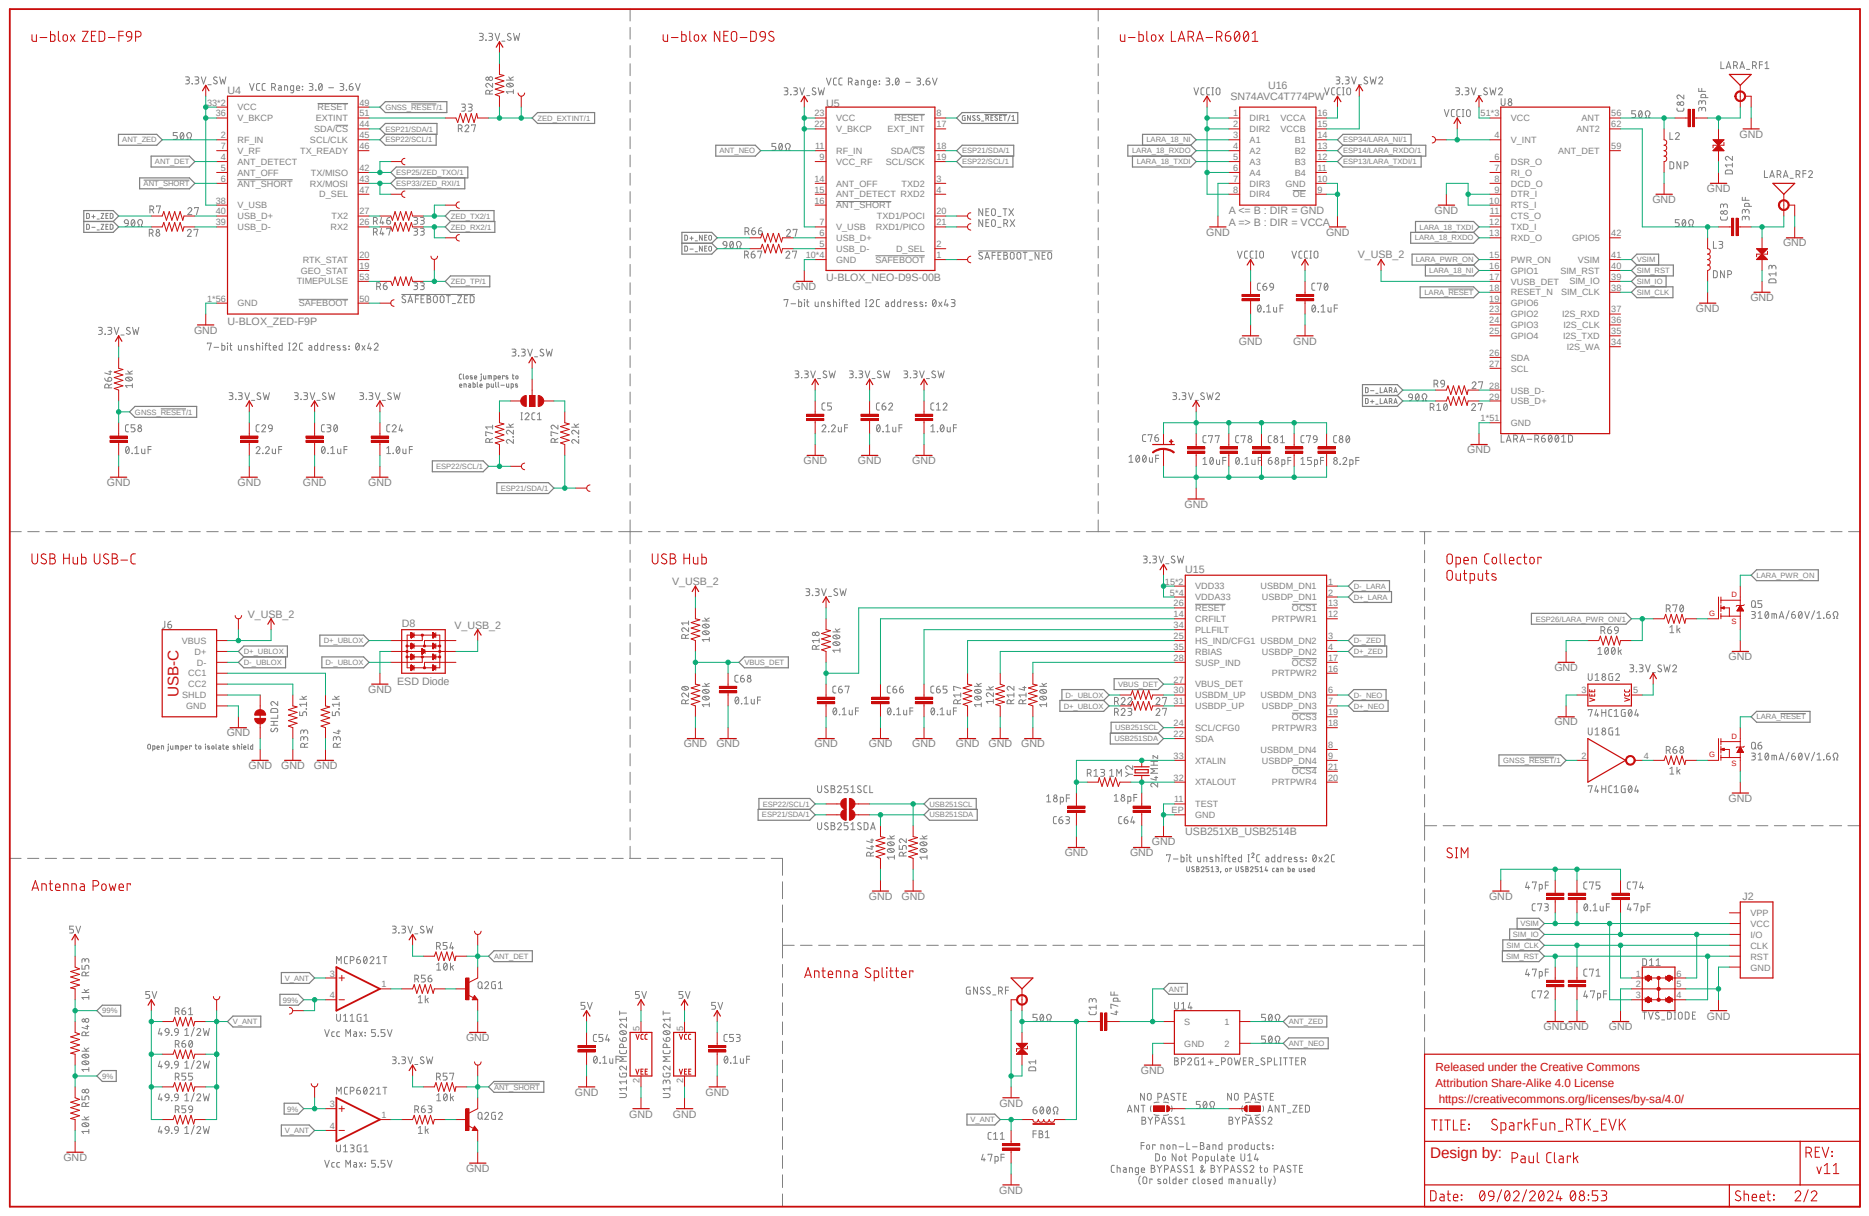
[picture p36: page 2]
A <= B : DIR = GND A => B : DIR = VCCA; GND; U-BLOX_ZED-F9P; U-BLOX_NEO-D9S-00B; GND GND; V_USB_2; ESD Diode; USB251XB_USB2514B; GND GND GND; SN74AVC4T774PW; GNDGND; TXD_I 12 RXD_O 13 RTS_I 10 CTS_O 11 DTR_I 9 DSR_O 6 RI_O 7 DCD_O 8; GND 1*56; VCC 33*2; RESET 49 TX/MISO 42 RX/MOSI 43 SDA/CS 44 SCL/CLK 45 TX_READY 46 D_SEL 47 SAFEBOOT 50 EXTINT 51 TIMEPULSE 53 RF_IN 2 ANT_DETECT 4 ANT_OFF 5 ANT_SHORT 6 V_RF 7; GEO_STAT 19 RTK_STAT 20 V_BKCP 36 V_USB 38 USB_D- 39 USB_D+ 40; GND 10*4 VCC 23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

V_USB_2
VBUS CC1 D+D- CC2 SHLD
Design by: USB⁻C

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

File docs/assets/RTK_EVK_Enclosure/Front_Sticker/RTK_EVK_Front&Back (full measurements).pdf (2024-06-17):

## FRONT

## Pantone 1795 C

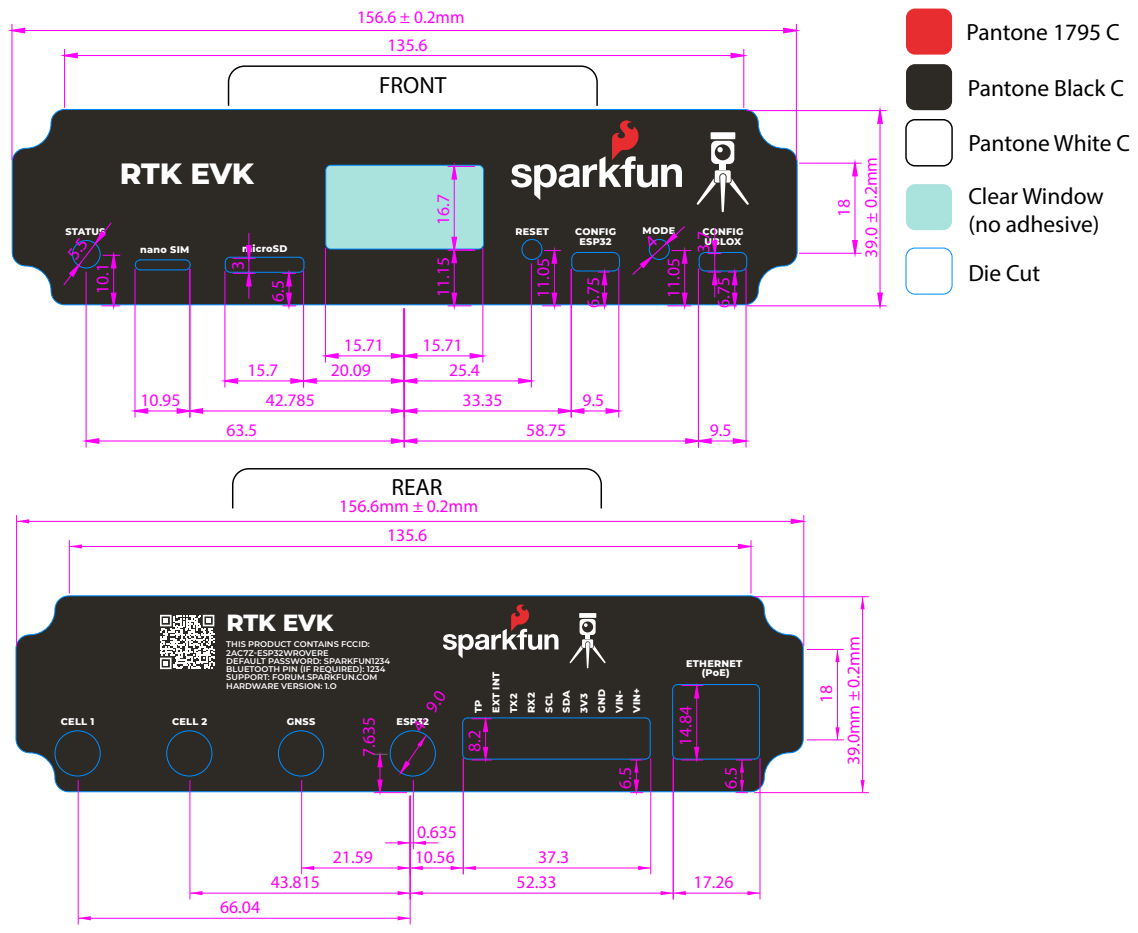
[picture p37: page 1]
REAR; Pantone Black C; Pantone White C; Clear Window (no adhesive); Die Cut; RTK EVK; nano SIM; microSD; STATUS; RESET; CONFIG; ESP32; CONFIG UBLOX; MODE; ETHERNET (PoE); CELL 1; CELL 2; GNSS; EXT INT; SCL; SDA; GND; VIN-; VIN+

THIS PRODUCT CONTAINS FCCID:
2AC7Z-ESP32WROVERE
DEFAULT PASSWORD: SPARKFUN1234
BLUETOOTH PIN (IF REQUIRED): 1234
SUPPORT: FORUM.SPARKFUN.COM
HARDWARE VERSION: 1.O

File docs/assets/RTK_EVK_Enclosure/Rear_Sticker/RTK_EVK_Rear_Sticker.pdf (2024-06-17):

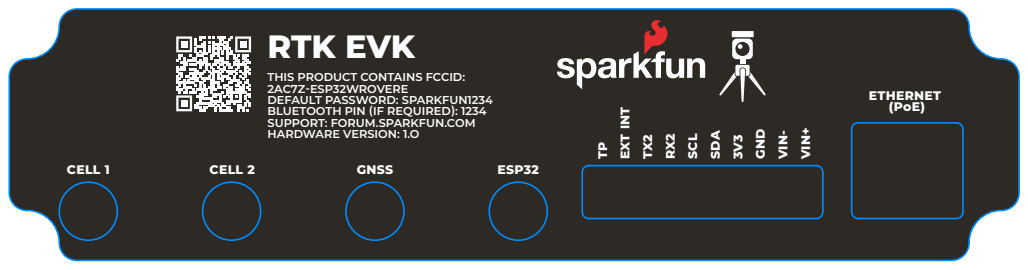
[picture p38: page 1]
RTK EVK; ETHERNET (PoE); CELL 1; CELL 2; GNSS; ESP32; EXT INT; SCL; SDA; GND; VIN-; VIN+

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

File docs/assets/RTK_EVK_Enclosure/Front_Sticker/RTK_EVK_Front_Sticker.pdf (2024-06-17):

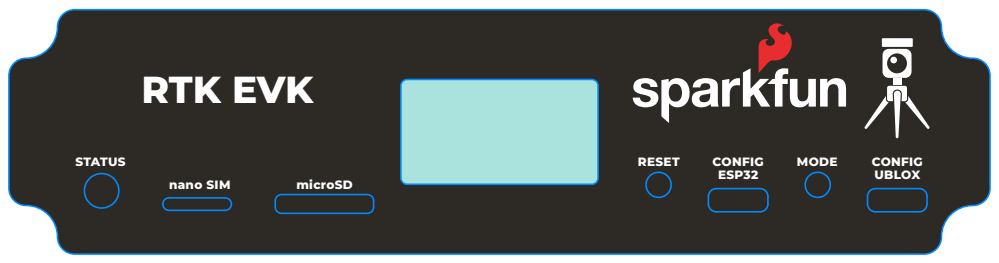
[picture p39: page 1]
RTK EVK; nano SIM; microSD; STATUS; RESET; CONFIG; ESP32; CONFIG UBLOX; MODE

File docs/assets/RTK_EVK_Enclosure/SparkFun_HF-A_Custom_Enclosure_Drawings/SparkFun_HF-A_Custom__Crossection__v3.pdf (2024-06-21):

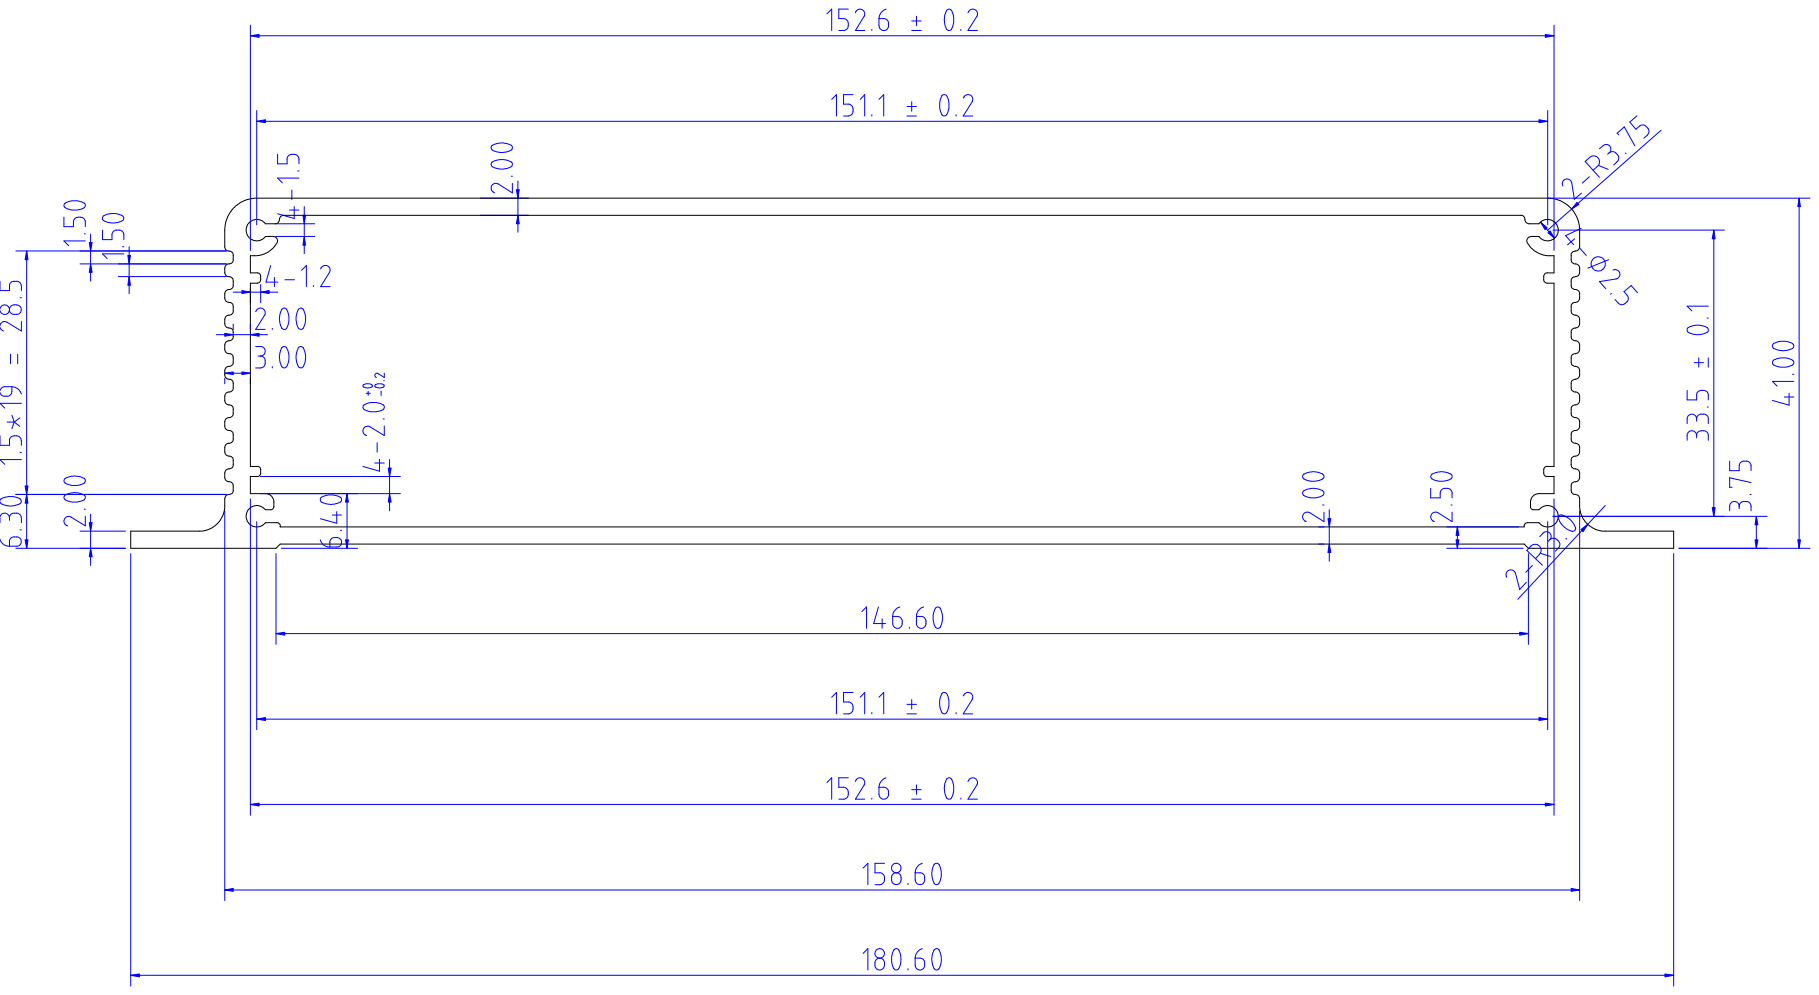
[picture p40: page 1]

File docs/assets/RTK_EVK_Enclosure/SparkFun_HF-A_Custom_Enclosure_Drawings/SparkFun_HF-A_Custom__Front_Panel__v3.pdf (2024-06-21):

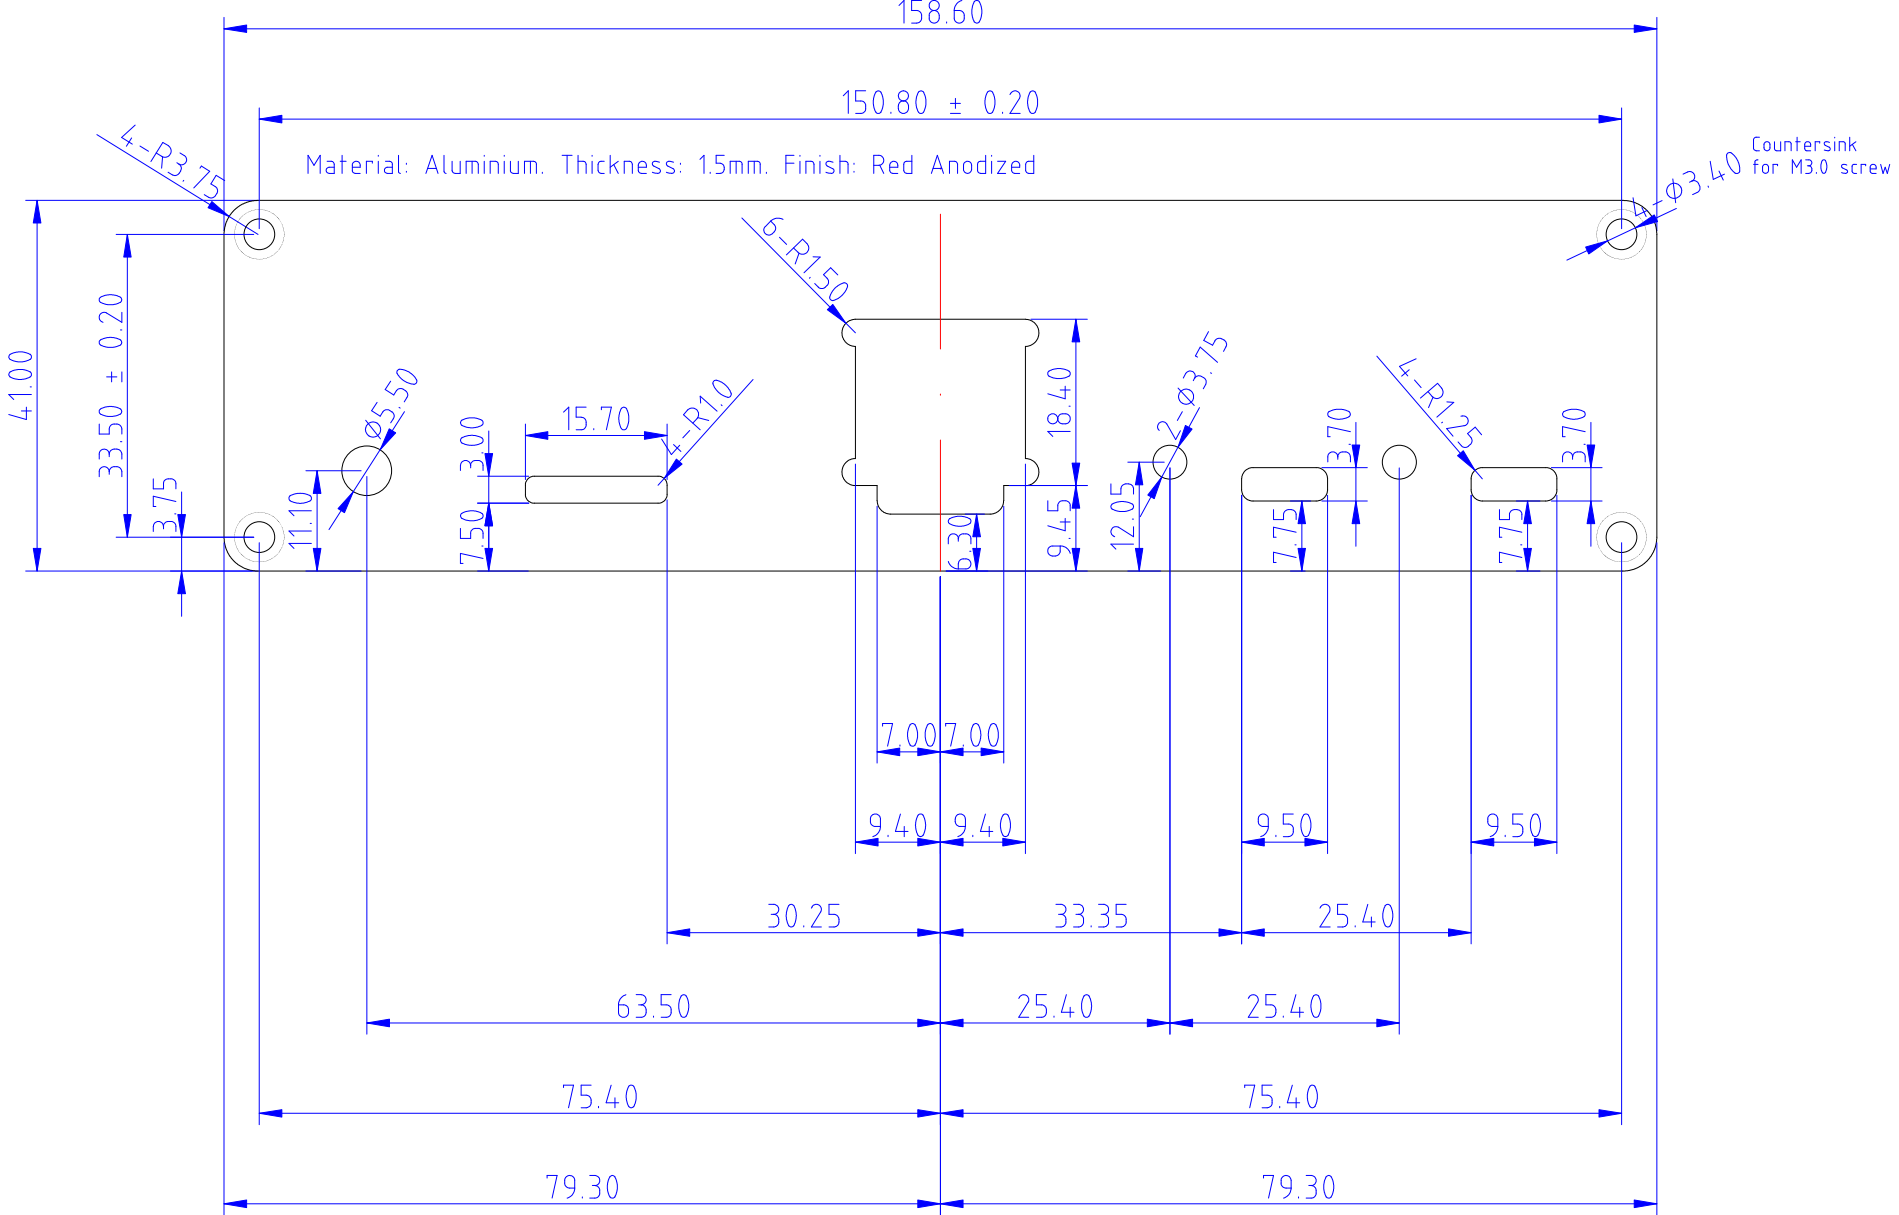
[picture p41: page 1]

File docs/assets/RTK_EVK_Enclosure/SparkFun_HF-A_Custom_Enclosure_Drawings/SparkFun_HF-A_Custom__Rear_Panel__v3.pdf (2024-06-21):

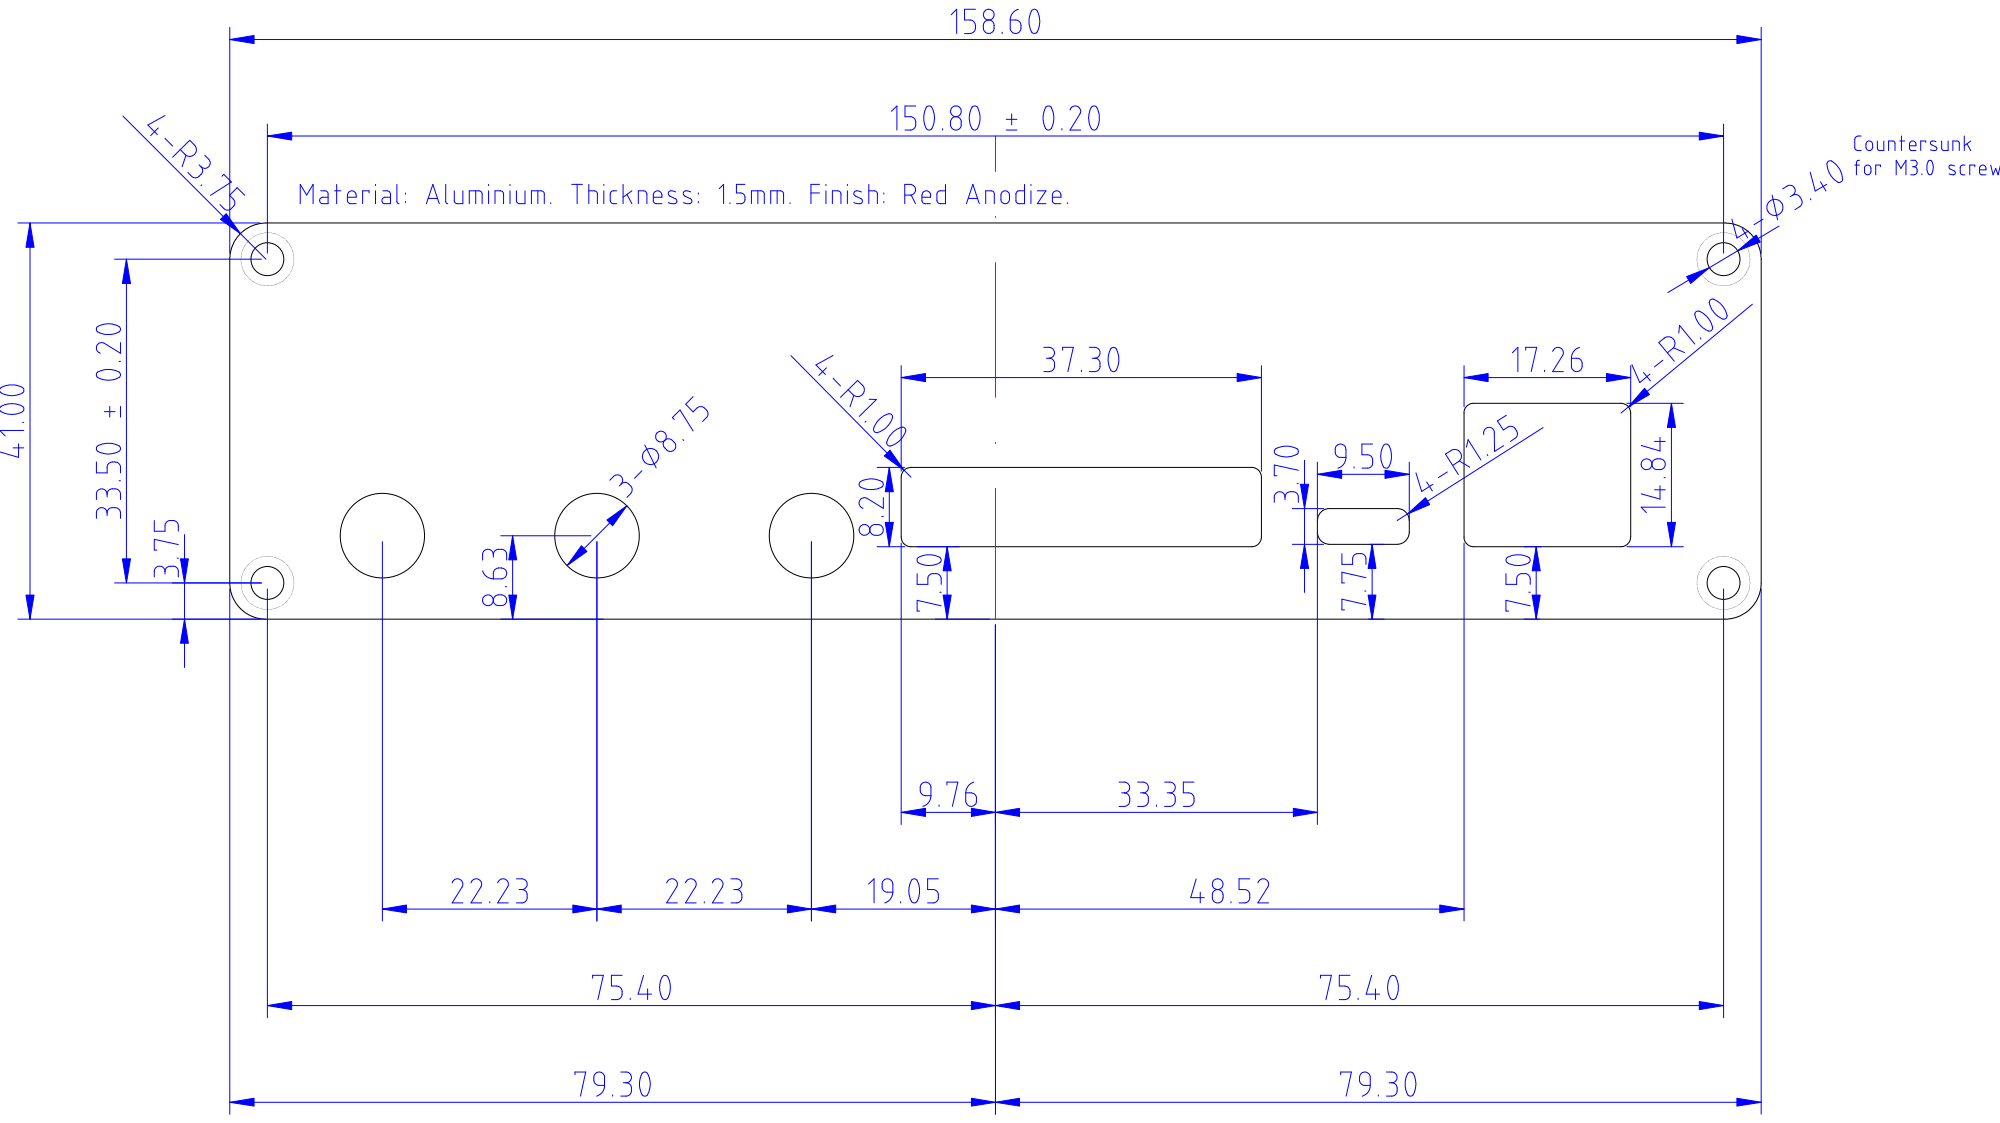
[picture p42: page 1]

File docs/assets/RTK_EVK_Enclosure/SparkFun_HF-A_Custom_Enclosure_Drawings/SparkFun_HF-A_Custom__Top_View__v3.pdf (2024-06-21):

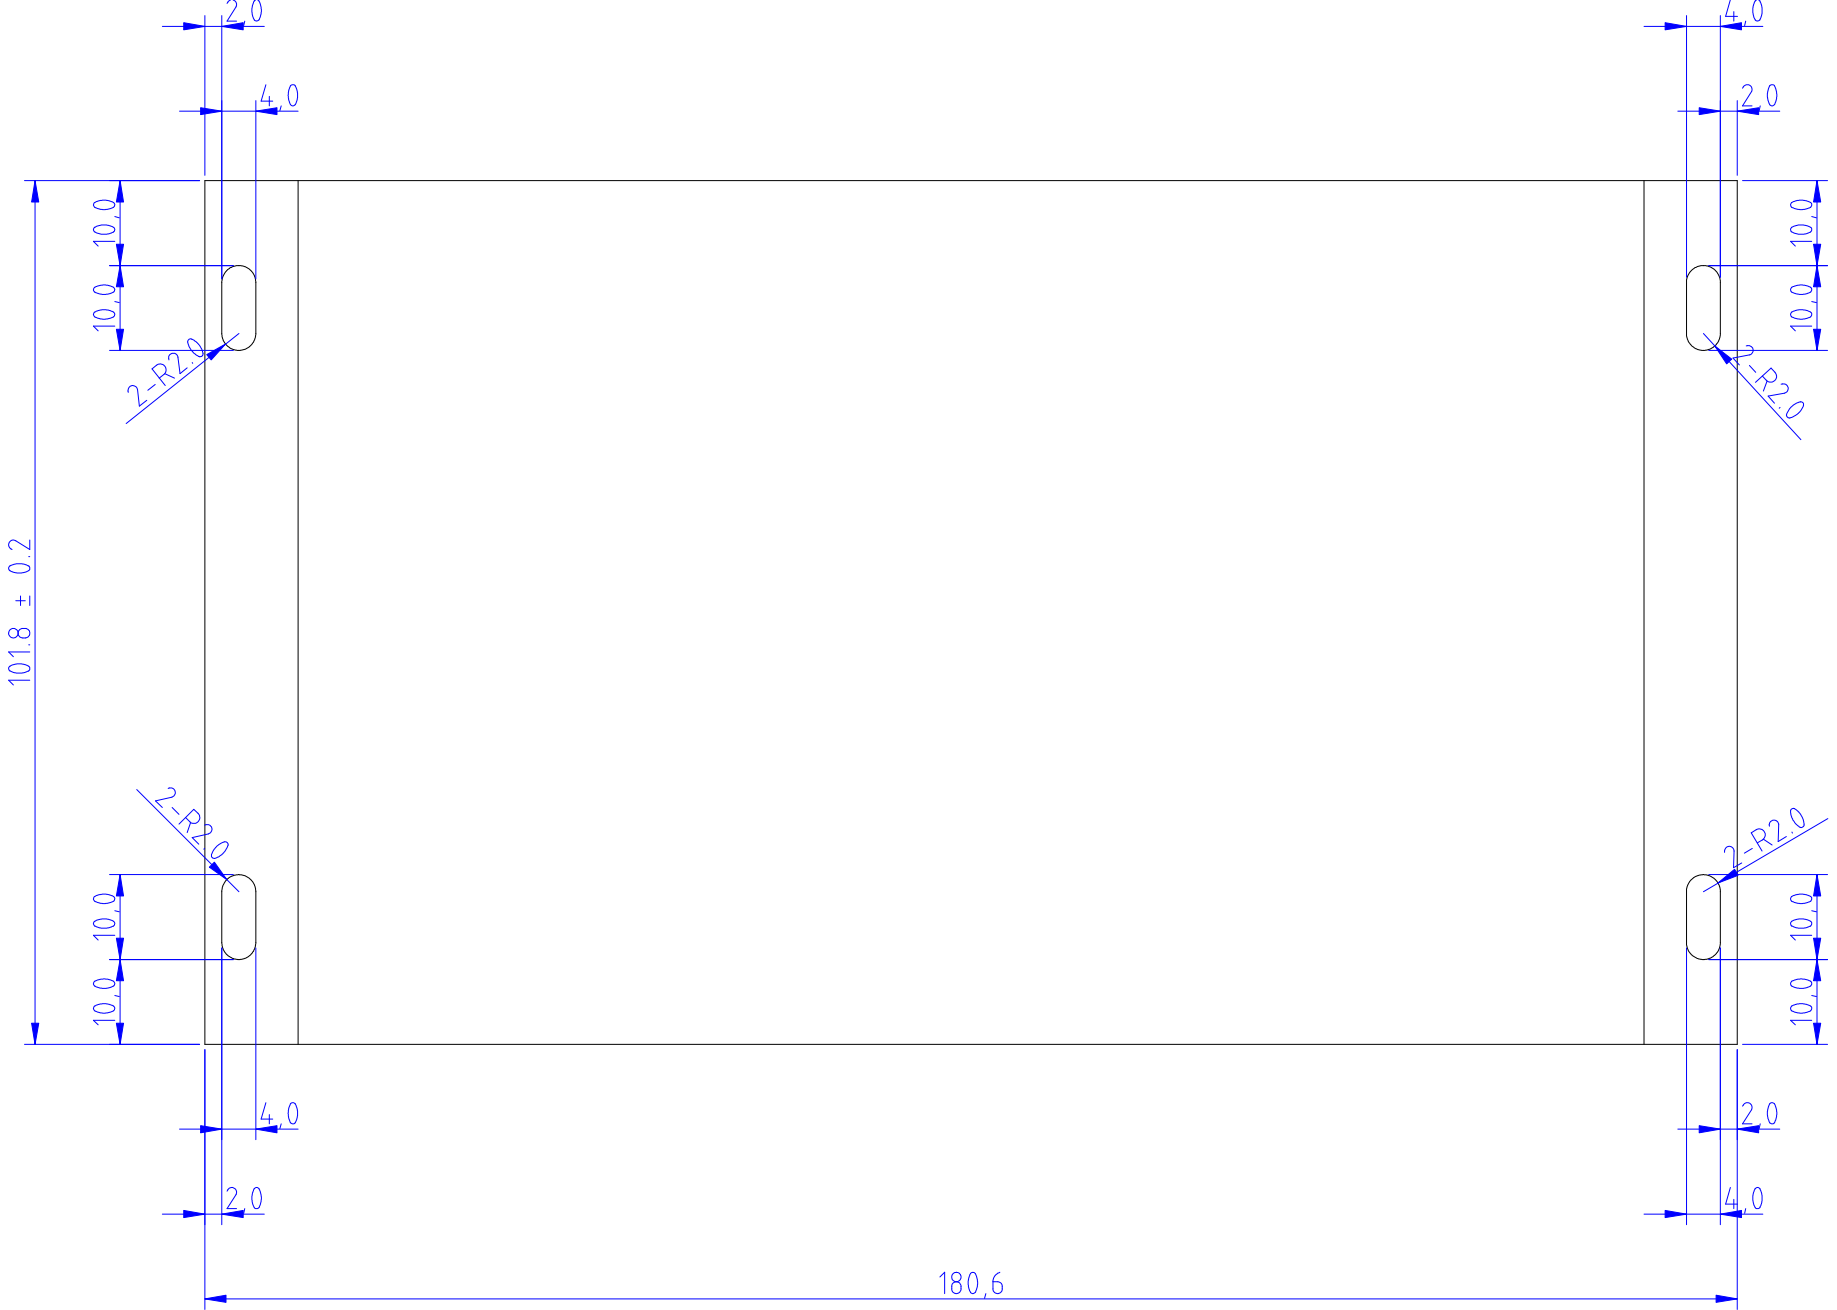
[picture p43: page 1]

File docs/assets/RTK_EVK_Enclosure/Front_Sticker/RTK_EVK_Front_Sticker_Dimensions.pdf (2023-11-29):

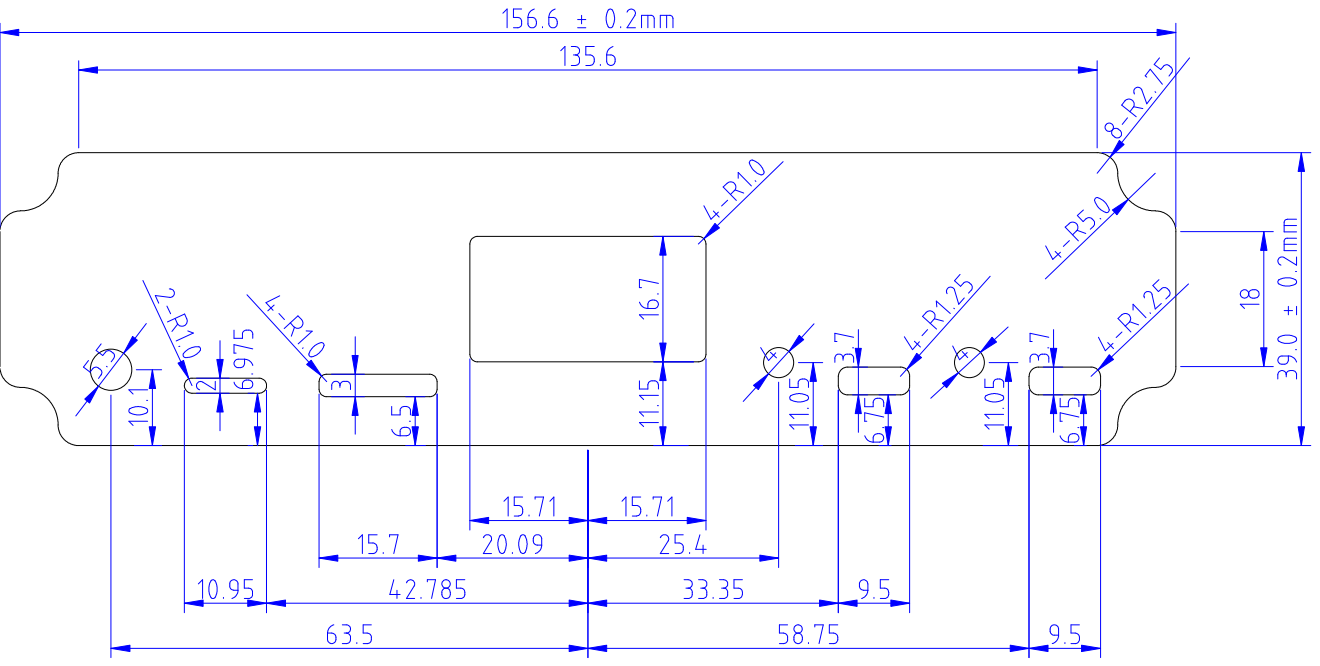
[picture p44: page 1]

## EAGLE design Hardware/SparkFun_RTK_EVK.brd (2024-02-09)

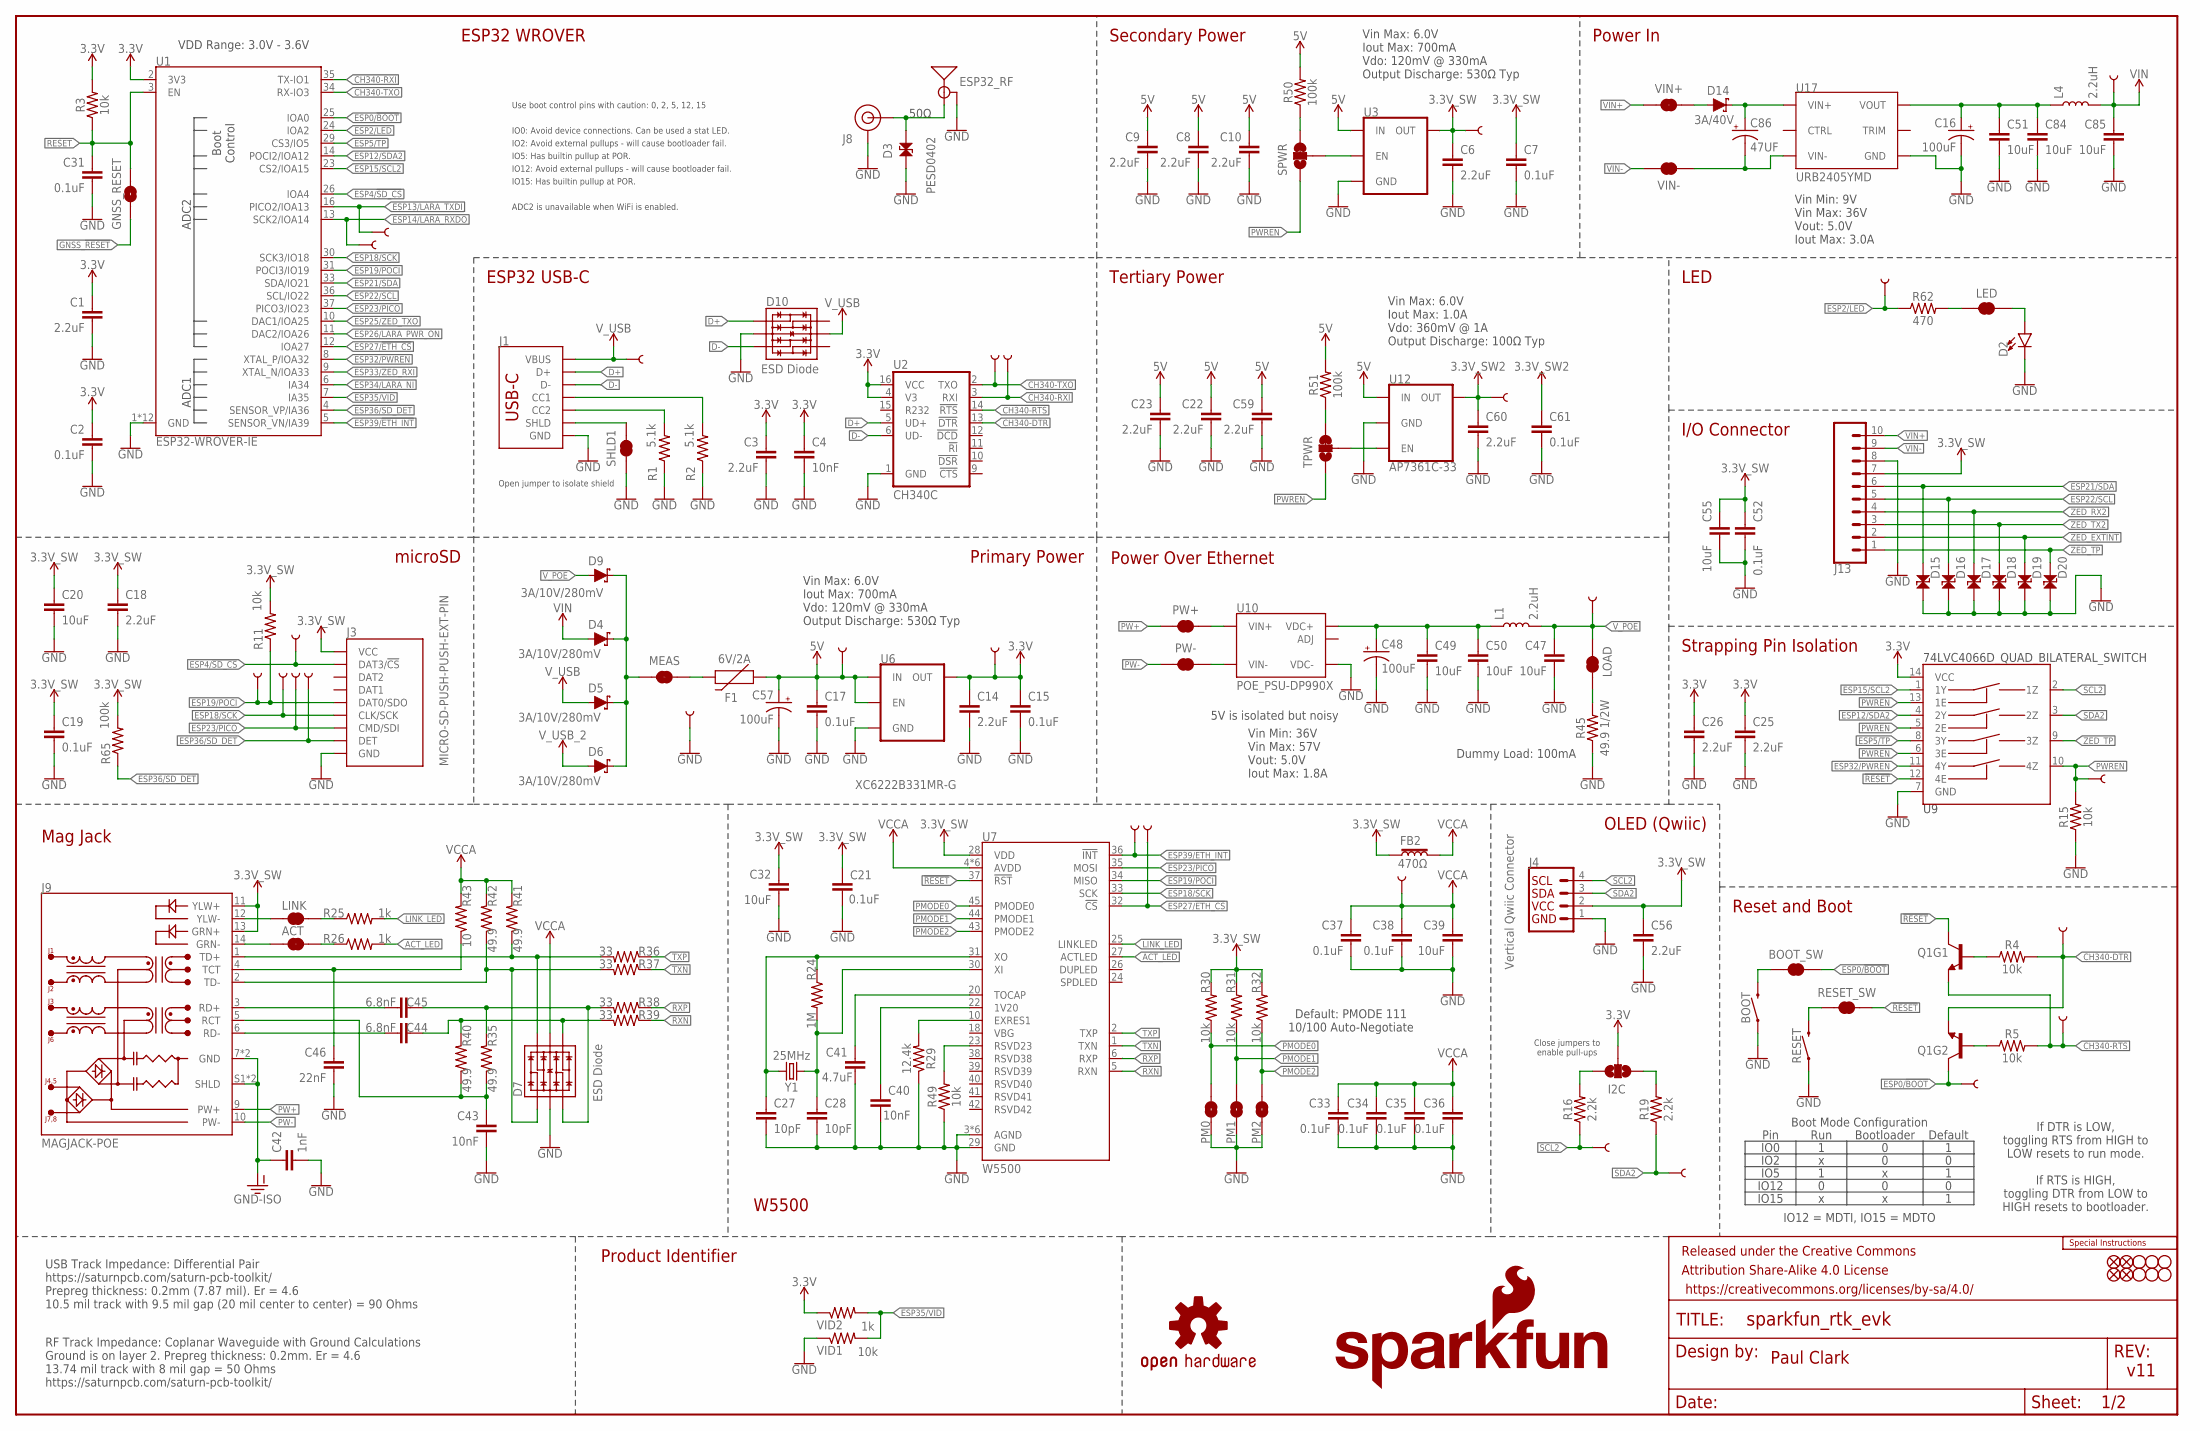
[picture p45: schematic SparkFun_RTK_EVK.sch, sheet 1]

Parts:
3V3, 3V3_SW, 3V3_SW2, 5V: TEST-POINTPOGO_PTH; 1X01_NO_SILK
ACT: JUMPER-SMT_2_NC_TRACE_SILK; SMT-JUMPER_2_NC_TRACE_SILK
BOOT: MOMENTARY-SWITCH-SPST-PTH-RIGHT-ANGLE-8-020; TACTILE_SWITCH_PTH_RA_8-020
BOOT_SW: JUMPER-SMT_2_NC_TRACE_SILK; SMT-JUMPER_2_NC_TRACE_SILK
C1, C3, C6, C8, C9, C10, C14, C18, C22, C23, C25, C26, C56, C59, C60: 2.2uF; 0603
C2, C7, C15, C17, C19, C21, C31, C33, C34, C35, C36, C37, C38, C52, C61: 0.1uF; 0603
C4, C40, C43: 10nF; 0603
C16, C48, C57: 100uF; PANASONIC_D
C20, C32, C39, C55: 10uF; 0603
C27, C28: 10pF; 0603
C41: 4.7uF; 0603
C42: 1nF; 1206
C44, C45: 6.8nF; 0603
C46: 22nF; 0603
C47, C49, C50, C51, C84, C85: 10uF; 0805
C86: 47UF; PANASONIC_D
D2: LED-RIGHT-ANGLE-PTH-GREEN; CBI-RIGHT-ANGLE-PTH
D3: PESD0402; 0402
D4, D5, D6, D9: 3A/10V/280mV; SOD-323
D7, D10: ESD Diode; SOT-23-6
D14: 3A/40V; SMA-DIODE
D15, D16, D17, D18, D19, D20: PESD0402-0402; 0402
DET: TEST-POINTPOGO_PTH; 1X01_NO_SILK
DTR: TEST-POINTPOGO_PTH; 1X01_NO_SILK
ESP32_RF: ANTENNA-SMA-GROUNDEDEDGE_RPSMA; RP-SMA-EDGE
ETH_CS: TEST-POINTPOGO_PTH; 1X01_NO_SILK
ETH_INT: TEST-POINTPOGO_PTH; 1X01_NO_SILK
F1: 6V/2A; 1210
FB2: 470Ω; 0603
FD1, FD2, FD3, FD4: FIDUCIAL1X2; FIDUCIAL-1X2
FRAME1: FRAME-LEDGER; CREATIVE_COMMONS
GND: TEST-POINTPOGO_PTH; 1X01_NO_SILK
GNSS_RESET: JUMPER-COMBO_2_NO; COMBO-JUMPER_2_NO
H1, H2, H3, H4, H5, H6: STAND-OFFTIGHT; STAND-OFF-TIGHT
I2C: JUMPER-SMT_3_NO_SILK; SMT-JUMPER_3_NO_SILK
J1: USB_C_4-LAYER_PADS; USB-C-16P_4LAYER-PADS
J3: MICRO-SD-PUSH-PUSH-EXT-PIN; MICROSD-EXTERNALPIN
J4: Vertical Qwiic Connector; JST04_1MM_VERT
J8: U.FL2PIN-REDUCED-FOOTPRINT; U.FL_REDUCED_FOOTPRINT
J9: MAGJACK-POE; MAGJACK-SYM_LED
J13: CONN_10_3.5MM_RA_HEADER; 1X10_SCREW_TERMINAL_3.5MM
L1, L4: 2.2uH; 0805-WIDE
LED: JUMPER-SMT_2_NC_TRACE_SILK; SMT-JUMPER_2_NC_TRACE_SILK
LINK: JUMPER-SMT_2_NC_TRACE_SILK; SMT-JUMPER_2_NC_TRACE_SILK
LOAD: JUMPER-SMT_2_NC_TRACE_SILK; SMT-JUMPER_2_NC_TRACE_SILK
LOGO1: SPECIAL_INSTRUCTIONS-ORDERING; ORDERING_INSTRUCTIONS
LOGO4: OSHW-LOGOS; OSHW-LOGO-S
LOGO5: SFE_LOGO_NAME.2_INCH; SFE_LOGO_NAME_.2
LOGO6: SFE_LOGO_FLAME.2_INCH; SFE_LOGO_FLAME_.2
MEAS: JUMPER-COMBO_2_NC_TRACE; COMBO-JUMPER_2_NC_TRACE
PICO: TEST-POINTPOGO_PTH; 1X01_NO_SILK
PM0, PM1, PM2: JUMPER-SMT_2_NO_SILK; SMT-JUMPER_2_NO_SILK
POCI: TEST-POINTPOGO_PTH; 1X01_NO_SILK
PW+: JUMPER-COMBO_2_NC_TRACE; COMBO-JUMPER_2_NC_TRACE
PW-: JUMPER-COMBO_2_NC_TRACE; COMBO-JUMPER_2_NC_TRACE
PWREN: TEST-POINTPOGO_PTH; 1X01_NO_SILK
Q1: TRANS_NPN_DUAL-MBT3904DW1T1; SC70-6
R1, R2: 5.1k; 0603
R3, R4, R5, R11, R15, R30, R31, R32, R49: 10k; 0603
R16, R19: 2.2k; 0603
R24: 1M; 0603
R25, R26: 1k; 0603
R29: 12.4k; 0603
R35, R40, R41, R42: 49.9; 0603
R36, R37, R38, R39: 33; 0603
R43: 10; 0603
R45: 49.9 1/2W; 1206
R50, R51, R65: 100k; 0603
R62: 470; 0603
RESET: MOMENTARY-SWITCH-SPST-PTH-RIGHT-ANGLE-8-020; TACTILE_SWITCH_PTH_RA_8-020
RESET_SW: JUMPER-SMT_2_NC_TRACE_SILK; SMT-JUMPER_2_NC_TRACE_SILK
RTS: TEST-POINTPOGO_PTH; 1X01_NO_SILK
RX: TEST-POINTPOGO_PTH; 1X01_NO_SILK
RXD: TEST-POINTPOGO_PTH; 1X01_NO_SILK
SCK: TEST-POINTPOGO_PTH; 1X01_NO_SILK
SCL2: TEST-POINTPOGO_PTH; 1X01_NO_SILK
SDA2: TEST-POINTPOGO_PTH; 1X01_NO_SILK
SD_CS: TEST-POINTPOGO_PTH; 1X01_NO_SILK
SHLD1: JUMPER-SMT_2_NC_TRACE_SILK; SMT-JUMPER_2_NC_TRACE_SILK
SPWR: JUMPER-SMT_3_1-NC_TRACE_SILK; SMT-JUMPER_3_1-NC_TRACE_SILK
TPWR: JUMPER-SMT_3_1-NC_TRACE_SILK; SMT-JUMPER_3_1-NC_TRACE_SILK
TP_BOOT: TEST-POINTPOGO_PTH; 1X01_NO_SILK
TP_LED: TEST-POINTPOGO_PTH; 1X01_NO_SILK
TX: TEST-POINTPOGO_PTH; 1X01_NO_SILK
TXD: TEST-POINTPOGO_PTH; 1X01_NO_SILK
U1: ESP32-WROVER-IE; ESP32-WROVER-E/IE
U2: CH340C; SO016
U3, U6: XC6222B331MR-G; SOT23-5
U7: W5500; LQFP-48
U9: 74LVC4066D_QUAD_BILATERAL_SWITCH; SO14
U10: POE_PSU-DP990X; DP990X
U12: AP7361C-33; UDFN-8
U17: URB2405YMD; URB_YMD-15WR3
VCCA: TEST-POINTPOGO_PTH; 1X01_NO_SILK
VID1: 10k; 0603
VID2: 1k; 0603
VIN: TEST-POINTPOGO_PTH; 1X01_NO_SILK
VIN+: JUMPER-COMBO_2_NC_TRACE; COMBO-JUMPER_2_NC_TRACE
VIN-: JUMPER-COMBO_2_NC_TRACE; COMBO-JUMPER_2_NC_TRACE
VPOE: TEST-POINTPOGO_PTH; 1X01_NO_SILK
VUSB: TEST-POINTPOGO_PTH; 1X01_NO_SILK
Y1: 25MHz; CRYSTAL-SMD-2.0X1.6MM

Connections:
3.3V: 3V3.1, C1.1, C2.1, C3.1, C4.1, C14.1, C15.1, C25.1, C26.1, I2C.2, R3.2, U1.2 (3V3), U2.4 (V3), U2.16 (VCC), U6.5 (OUT), U9.14 (VCC), VID2.1
3.3V_SW: 3V3_SW.1, C6.1, C7.1, C18.1, C19.1, C20.1, C21.1, C32.1, C52.1, C55.1, C56.1, FB2.1, J3.4 (VCC), J4.2, J9.11 (YLW+), J9.13 (GRN+), J13.7, R11.2, R30.2, R31.2, R32.2, R65.2, U3.5 (OUT), U7.28 (VDD); also elsewhere on the board
3.3V_SW2: 3V3_SW2.1, C60.1, C61.1, U12.1 (OUT); also elsewhere on the board
5V: 5V.1, C8.1, C9.1, C10.1, C17.1, C22.1, C23.1, C57.+, C59.1, F1.1, R50.2, R51.2, U3.1 (IN), U6.1 (IN), U6.3 (EN), U12.8 (IN); also elsewhere on the board
5V_RAW: C48.+, C49.1, C50.1, L1.1, U10.1 (VDC+), U10.2 (VDC+)
5V_RAW1: C16.+, C51.1, C84.1, L4.1, U17.4 (VOUT)
!RESET!: C31.1, GNSS_RESET.2, GNSS_RESET.4 (2), Q1.3 (C), R3.1, RESET_SW.1, U1.3 (EN), U7.37 (!RST!), U9.12 (4E)
ACT: ACT.1, J9.14 (GRN-)
ACT_LED: R26.2, U7.27 (ACTLED)
CH340-DTR: DTR.1, Q1.1 (E), R4.2, U2.13 (!DTR)
CH340-RTS: Q1.4 (E), R5.2, RTS.1, U2.14 (!RTS)
CH340-RXI: TX.1, U1.35 (TX-IO1), U2.3 (RXI)
CH340-TXO: RX.1, U1.34 (RX-IO3), U2.2 (TXO)
D+: D10.1 (IO1), J1.A6 (D+), J1.B6 (D+), U2.5 (UD+)
D-: D10.3 (IO2), J1.A7 (D-), J1.B7 (D-), U2.6 (UD-)
ESP0/!BOOT!: BOOT_SW.1, Q1.6 (C), TP_BOOT.1, U1.25 (IOA0)
ESP2/LED: R62.1, TP_LED.1, U1.24 (IOA2)
ESP4/!SD_CS!: J3.2 (DAT3/!CS!), SD_CS.1, U1.26 (IOA4)
ESP5/TP: U1.29 (CS3/IO5), U9.8 (3Y)
ESP12/SDA2: U1.14 (POCI2/IOA12), U9.4 (2Y)
ESP13/LARA_TXDI: TXD.1, U1.16 (PICO2/IOA13); also elsewhere on the board
ESP14/LARA_RXDO: RXD.1, U1.13 (SCK2/IOA14); also elsewhere on the board
ESP15/SCL2: U1.23 (CS2/IOA15), U9.1 (1Y)
ESP18/SCK: J3.5 (CLK/SCK), SCK.1, U1.30 (SCK3/IO18), U7.33 (SCK)
ESP19/POCI: J3.7 (DAT0/SDO), POCI.1, R11.1, U1.31 (POCI3/IO19), U7.34 (MISO)
ESP21/SDA: D15.1, J13.6, U1.33 (SDA/IO21); also elsewhere on the board
ESP22/SCL: D16.1, J13.5, U1.36 (SCL/IO22); also elsewhere on the board
ESP23/PICO: J3.3 (CMD/SDI), PICO.1, U1.37 (PICO3/IO23), U7.35 (MOSI)
ESP25/ZED_TXO: U1.10 (DAC1/IOA25); also elsewhere on the board
ESP26/LARA_PWR_ON: U1.11 (DAC2/IOA26); also elsewhere on the board
ESP27/!ETH_CS!: ETH_CS.1, U1.12 (IOA27), U7.32 (!CS!)
ESP32/PWREN: U1.8 (XTAL_P/IOA32), U9.11 (4Y)
ESP33/ZED_RXI: U1.9 (XTAL_N/IOA33); also elsewhere on the board
ESP34/LARA_NI: U1.6 (IA34); also elsewhere on the board
ESP35/VID: U1.7 (IA35), VID1.2, VID2.2
ESP36/SD_DET: DET.1, J3.9 (DET), R65.1, U1.4 (SENSOR_VP/IA36)
ESP39/!ETH_INT!: ETH_INT.1, U1.5 (SENSOR_VN/IA39), U7.36 (!INT!)
GND: BOOT.1, C1.2, C2.2, C3.2, C4.2, C6.2, C7.2, C8.2, C9.2, C10.2, C14.2, C15.2, C16.-, C17.2, C18.2, C19.2, C20.2, C21.2, C22.2, C23.2, C25.2, C26.2, C27.2, C28.2, C31.2, C32.2, C33.2, C34.2, C35.2, C36.2, C37.2, C38.2, C39.2, C40.2, C41.2, C42.2, C43.2, C46.2, C47.2, C48.-, C49.2, C50.2, C51.2, C52.2, C55.2, C56.2, C57.-, C59.2, C60.2, C61.2, C84.2, C85.2, D2.C, D3.2, D7.2 (VSS), D10.2 (VSS), D15.2, D16.2, D17.2, D18.2, D19.2, D20.2, ESP32_RF.GND@0 (GND), ESP32_RF.GND@1 (GND), ESP32_RF.GND@2 (GND), ESP32_RF.GND@3 (GND), GND.1, J1.GND, J1.GND2 (GND), J3.6 (GND), J3.10 (GND), J3.11 (GND), J3.12 (GND), J3.13 (GND), J4.1, J8.1 (GND), J8.2 (GND), J13.8, PM0.1, PM1.1, PM2.1, R1.1, R2.1, R15.1, R29.1, R45.1, R49.1, RESET.1, SHLD1.1, U1.1 (GND), U1.15 (GND), U1.38 (GND), U1.GND, U1.GNDT1 (GND), U1.GNDT2 (GND), U1.GNDT3 (GND), U1.GNDT4 (GND), U1.GNDT5 (GND), U1.GNDT6 (GND), U1.GNDT7 (GND), U1.GNDT8 (GND), U2.1 (GND), U3.2 (GND), U6.2 (GND), U7.3 (AGND), U7.9 (AGND), U7.14 (AGND), U7.16 (AGND), U7.19 (AGND), U7.29 (GND), U7.48 (AGND), U9.7 (GND), U10.3 (VDC-), U12.4 (GND), U12.EP (GND), U17.6 (GND), VID1.1; also elsewhere on the board
GND-ISO: C42.1, J9.7 (GND), J9.8 (GND), J9.S1 (SHLD), J9.S2 (SHLD)
GNSS_!RESET!: GNSS_RESET.1, GNSS_RESET.3 (1); also elsewhere on the board
LINK: J9.12 (YLW-), LINK.1
LINK_LED: R25.2, U7.25 (LINKLED)
MEAS: D4.C, D5.C, D6.C, D9.C, MEAS.2, MEAS.4 (2)
unnamed: J1.B5 (CC2), R1.2
unnamed: J1.A5 (CC1), R2.2
unnamed: Q1.2 (B), R5.1
unnamed: Q1.5 (B), R4.1
unnamed: LED.2, R62.2
unnamed: F1.2, MEAS.1, MEAS.3 (1)
unnamed: ACT.2, R26.1
unnamed: D3.1, ESP32_RF.SIG (SIGNAL), J8.FEED (SIGNAL)
unnamed: I2C.3, R16.2
unnamed: I2C.1, R19.2
unnamed: C27.1, R24.1, U7.31 (XO), Y1.1
unnamed: C28.1, R24.2, U7.30 (XI), Y1.3 (2)
unnamed: LINK.2, R25.1
unnamed: R50.1, SPWR.3
unnamed: R29.2, U7.10 (EXRES1)
unnamed: C40.1, U7.22 (1V20)
unnamed: C41.1, U7.20 (TOCAP)
unnamed: SPWR.2, U3.3 (EN)
unnamed: LOAD.1, R45.2
unnamed: RESET.2, RESET_SW.2
unnamed: BOOT.2, BOOT_SW.2
unnamed: R49.2, U7.23 (RSVD23)
unnamed: R51.1, TPWR.3
unnamed: TPWR.2, U12.5 (EN)
unnamed: D2.A, LED.1
PMODE0: PM0.2, R30.1, U7.45 (PMODE0)
PMODE1: PM1.2, R31.1, U7.44 (PMODE1)
PMODE2: PM2.2, R32.1, U7.43 (PMODE2)
PW1+: PW+.1, PW+.3 (1), U10.5 (VIN+), U10.6 (VIN+)
PW1-: PW-.1, PW-.3 (1), U10.7 (VIN-), U10.8 (VIN-)
PW+: J9.9 (PW+), PW+.2, PW+.4 (2)
PW-: J9.10 (PW-), PW-.2, PW-.4 (2)
PWREN: PWREN.1, R15.2, SPWR.1, TPWR.1, U9.5 (2E), U9.6 (3E), U9.10 (4Z), U9.13 (1E)
RCT: C43.1, J9.5 (RCT), R35.1, R40.1
RD+: C45.2, J9.3 (RD+)
RD-: C44.2, J9.6 (RD-)
RXN: R39.1, U7.5 (RXN)
RXN1: C44.1, D7.4 (IO3), R39.2, R40.2
RXP: R38.1, U7.6 (RXP)
RXP1: C45.1, D7.3 (IO2), R35.2, R38.2
SCL2: J4.4, R16.1, SCL2.1, U9.2 (1Z)
SDA2: J4.3, R19.1, SDA2.1, U9.3 (2Z)
SHIELD: J1.SHLD1 (SHLD), J1.SHLD2 (SHLD), J1.SHLD3 (SHLD), J1.SHLD4 (SHLD), SHLD1.2
TCT: C46.1, J9.4 (TCT), R43.1
TD+: D7.6 (IO4), J9.1 (TD+), R36.2, R41.1
TD-: D7.1 (IO1), J9.2 (TD-), R37.2, R42.1
TXN: R37.1, U7.1 (TXN)
TXP: R36.1, U7.2 (TXP)
VCCA: C33.1, C34.1, C35.1, C36.1, C37.1, C38.1, C39.1, D7.5 (VCC), FB2.2, R41.2, R42.2, R43.2, U7.4 (AVDD), U7.8 (AVDD), U7.11 (AVDD), U7.15 (AVDD), U7.17 (AVDD), U7.21 (AVDD), VCCA.1
VIN: C85.1, D4.A, L4.2, VIN.1
VIN1+: D14.A, VIN+.1, VIN+.3 (1)
VIN1-: C86.-, U17.2 (VIN-), VIN-.2, VIN-.4 (2)
VIN2+: C86.+, D14.C, U17.3 (VIN+)
VIN+: J13.10, VIN+.2, VIN+.4 (2)
VIN-: J13.9, VIN-.1, VIN-.3 (1)
V_POE: C47.1, D9.A, L1.2, LOAD.2, VPOE.1
V_USB: D5.A, D10.5 (VCC), J1.VBUS1 (VBUS), J1.VBUS2 (VBUS), VUSB.1
V_USB_2: D6.A; also elsewhere on the board
ZED_EXTINT: D19.1, J13.2; also elsewhere on the board
ZED_RX2: D17.1, J13.4; also elsewhere on the board
ZED_TP: D20.1, J13.1, U9.9 (3Z); also elsewhere on the board
ZED_TX2: D18.1, J13.3; also elsewhere on the board

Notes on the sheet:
ESP32 WROVER
ESP32 USB-C
Paul Clark
v11
Reset and Boot
LED
Secondary Power
Primary Power
microSD
Strapping Pin Isolation
W5500
Mag Jack
VDD Range: 3.0V - 3.6V
Vin Max: 6.0V Iout Max: 700mA Vdo: 120mV @ 330mA Output Discharge: 530Ω Typ
If DTR is LOW, toggling RTS from HIGH to LOW resets to run mode. If RTS is HIGH, toggling DTR from LOW to HIGH resets to bootloader.
Pin
IO0
IO2
IO12
IO15
IO5
Run
Bootloader
Default
IO12 = MDTI, IO15 = MDTO
Boot Mode Configuration
IO0: Avoid device connections. Can be used a stat LED.
ADC2 is unavailable when WiFi is enabled.
IO12: Avoid external pullups - will cause bootloader fail.
Use boot control pins with caution: 0, 2, 5, 12, 15
IO2: Avoid external pullups - will cause bootloader fail.
IO15: Has builtin pullup at POR.
IO5: Has builtin pullup at POR.
Close jumpers to enable pull-ups
Open jumper to isolate shield
RF Track Impedance: Coplanar Waveguide with Ground Calculations Ground is on layer 2. Prepreg thickness: 0.2mm. Er = 4.6 13.74 mil track with 8 mil gap = 50 Ohms https://saturnpcb.com/saturn-pcb-toolkit/
USB Track Impedance: Differential Pair https://saturnpcb.com/saturn-pcb-toolkit/ Prepreg thickness: 0.2mm (7.87 mil). Er = 4.6 10.5 mil track with 9.5 mil gap (20 mil center to center) = 90 Ohms
50Ω
Power Over Ethernet
5V is isolated but noisy

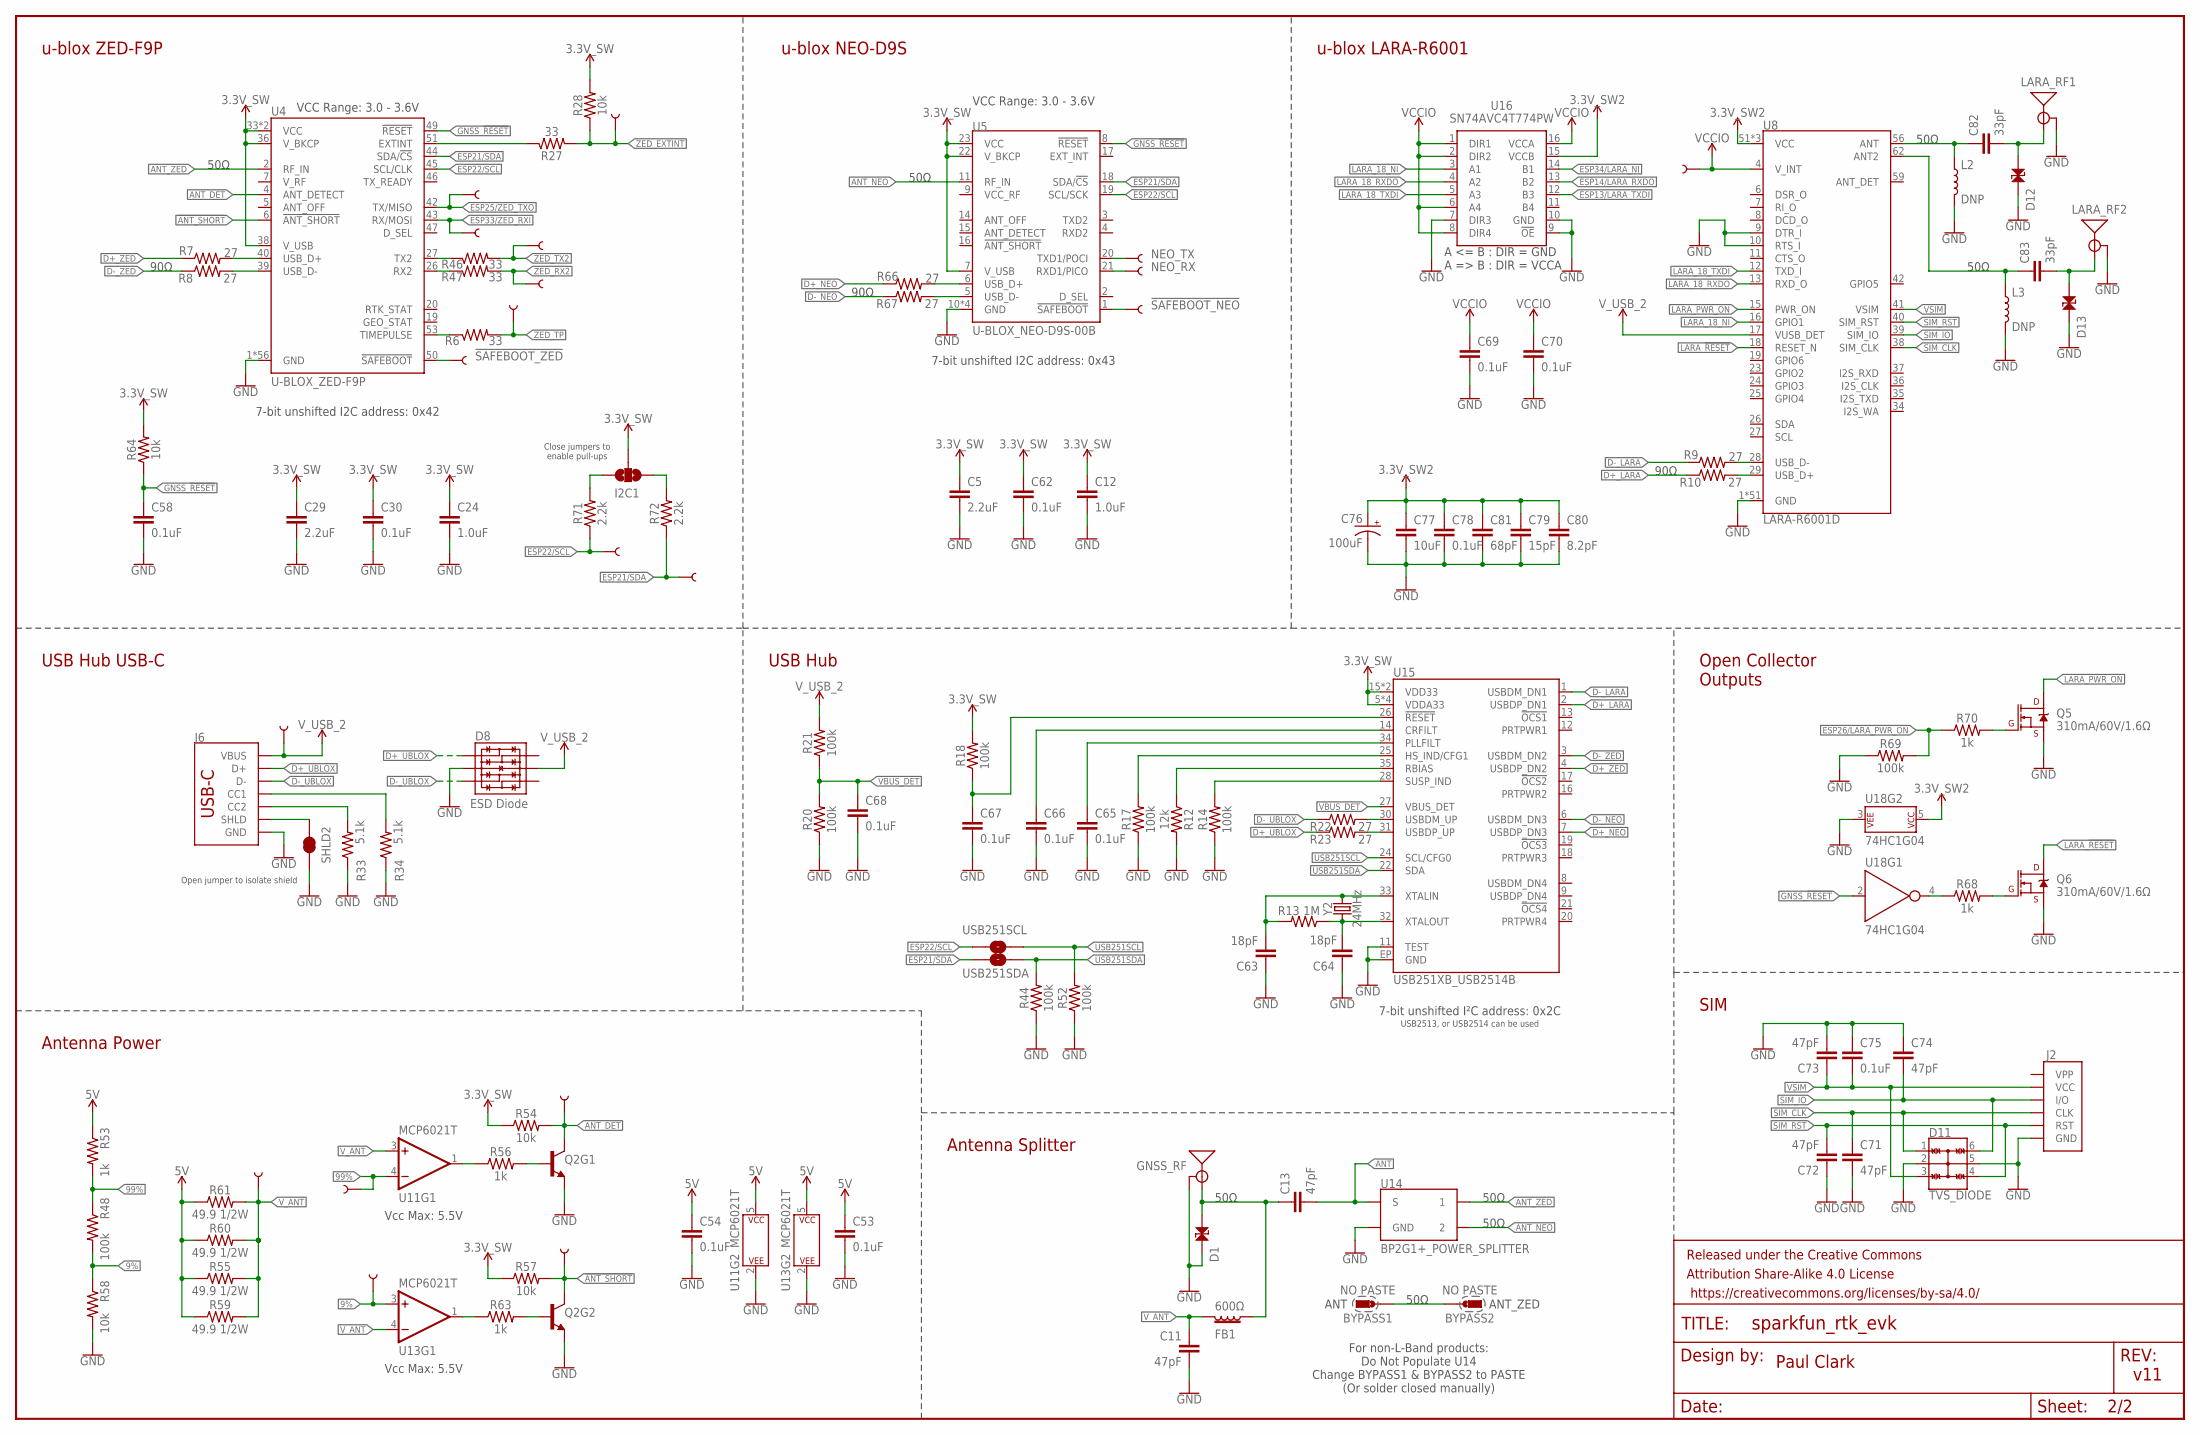
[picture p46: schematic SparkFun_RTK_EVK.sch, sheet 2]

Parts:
9%, 99%: TEST-POINTPOGO_PTH; 1X01_NO_SILK
!SAFEBOOT_NEO!: TEST-POINTPOGO_PTH; 1X01_NO_SILK
!SAFEBOOT_ZED!: TEST-POINTPOGO_PTH; 1X01_NO_SILK
ANT_DET: TEST-POINTPOGO_PTH; 1X01_NO_SILK
ANT_SHT: TEST-POINTPOGO_PTH; 1X01_NO_SILK
BYPASS1, BYPASS2: NO PASTE; SMT-JUMPER_2_SOIC-PAD_NO-PASTE
C5, C29: 2.2uF; 0603
C11, C13, C71, C72, C73, C74: 47pF; 0603
C12, C24: 1.0uF; 0603
C30, C53, C54, C58, C62, C65, C66, C67, C68, C69, C70, C75, C78: 0.1uF; 0603
C63, C64: 18pF; 0603
C76: 100uF; PANASONIC_D
C77: 10uF; 0805
C79: 15pF; 0603
C80: 8.2pF; 0603
C81: 68pF; 0603
C82, C83: 33pF; 0603
D1, D12, D13: PESD0402-0402; 0402
D8: ESD Diode; SOT-23-6
D11: TVS_DIODE; SOT23-6L
FB1: 600Ω; 0805
FRAME2: FRAME-LEDGERNO_FOOTPRINT; DUMMY
GNSS_RF: ANTENNA-SMA-GROUNDEDEDGE_SMA; SMA-EDGE
I2C1: JUMPER-SMT_3_NO_SILK; SMT-JUMPER_3_NO_SILK
J2: SIMHOLDER-PUSHPUSH; NANO_SIM_PP
J6: USB_C_4-LAYER_PADS; USB-C-16P_4LAYER-PADS
L2, L3: DNP; 0603_NO-CREAM
LARA_RF1, LARA_RF2: ANTENNA-SMA-GROUNDEDEDGE_SMA; SMA-EDGE
NEO_RX: TEST-POINTPOGO_PTH; 1X01_NO_SILK
NEO_TX: TEST-POINTPOGO_PTH; 1X01_NO_SILK
Q2: TRANS_NPN_DUAL-MBT3904DW1T1; SC70-6
Q5, Q6: 310mA/60V/1.6Ω; SOT323
R6, R27, R46, R47: 33; 0603
R7, R8, R9, R10, R22, R23, R66, R67: 27; 0603
R12: 12k; 0603
R13: 1M; 0603
R14, R17, R18, R20, R21, R44, R48, R52, R69: 100k; 0603
R28, R54, R57, R58, R64: 10k; 0603
R33, R34: 5.1k; 0603
R53, R56, R63, R68, R70: 1k; 0603
R55, R59, R60, R61: 49.9 1/2W; 1206
R71, R72: 2.2k; 0603
RX2: TEST-POINTPOGO_PTH; 1X01_NO_SILK
SCL: TEST-POINTPOGO_PTH; 1X01_NO_SILK
SDA: TEST-POINTPOGO_PTH; 1X01_NO_SILK
SHLD2: JUMPER-SMT_2_NC_TRACE_SILK; SMT-JUMPER_2_NC_TRACE_SILK
TP: TEST-POINTPOGO_PTH; 1X01_NO_SILK
TX2: TEST-POINTPOGO_PTH; 1X01_NO_SILK
U4: U-BLOX_ZED-F9P; ZED-F9P
U5: U-BLOX_NEO-D9S-00B; NEO-M9N/M8T/M8U/D9S
U8: LARA-R6001D; LARA-LGA
U11, U13: MCP6021T; SOT23-5
U14: BP2G1+_POWER_SPLITTER; XX21
U15: USB251XB_USB2514B; QFN-36
U16: SN74AVC4T774PW; SOP65P640X120-16N
U18: 74HC1G04; SOT353
USB251SCL, USB251SDA: JUMPER-SMT_2_NO_SILK; SMT-JUMPER_2_NO_SILK
VANT: TEST-POINTPOGO_PTH; 1X01_NO_SILK
VCCIO: TEST-POINTPOGO_PTH; 1X01_NO_SILK
VUSB2: TEST-POINTPOGO_PTH; 1X01_NO_SILK
Y2: 24MHz; CRYSTAL-SMD-2.0X1.6MM
ZED_EXTINT: TEST-POINTPOGO_PTH; 1X01_NO_SILK
ZED_RXI: TEST-POINTPOGO_PTH; 1X01_NO_SILK
ZED_TXO: TEST-POINTPOGO_PTH; 1X01_NO_SILK

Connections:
3.3V_SW: C5.1, C12.1, C24.1, C29.1, C30.1, C62.1, I2C1.2, R18.2, R28.2, R54.1, R57.1, R64.2, U4.33 (VCC), U4.34 (VCC), U4.36 (V_BKCP), U4.38 (V_USB), U5.7 (V_USB), U5.22 (V_BKCP), U5.23 (VCC), U15.5 (VDDA33), U15.10 (VDDA33), U15.15 (VDD33), U15.23 (VDD33), U15.29 (VDDA33), U15.36 (VDDA33); also elsewhere on the board
3.3V_SW2: C76.+, C77.1, C78.1, C79.1, C80.1, C81.1, U8.51 (VCC), U8.52 (VCC), U8.53 (VCC), U16.15 (VCCB), U18.5 (P$V+); also elsewhere on the board
5V: C53.1, C54.1, R53.1, R55.1, R59.1, R60.1, R61.1, U11.5 (P$V+), U13.5 (P$V+); also elsewhere on the board
9%: 9%.1, R48.2, R58.1, U13.3 (+IN)
99%: 99%.1, R48.1, R53.2, U11.4 (-IN)
!ANT_SHORT!: ANT_SHT.1, Q2.6 (C), R57.2, U4.6 (!ANT_SHORT!)
!SAFEBOOT_NEO!: !SAFEBOOT_NEO!.1, U5.1 (!SAFEBOOT!)
!SAFEBOOT_ZED!: !SAFEBOOT_ZED!.1, U4.50 (!SAFEBOOT!)
ANT: C13.2, U14.2 (S)
ANT_DET: ANT_DET.1, Q2.3 (C), R54.2, U4.4 (ANT_DETECT)
ANT_NEO: U5.11 (RF_IN), U14.5 (2)
ANT_ZED: U4.2 (RF_IN), U14.8 (1)
BYPASS: BYPASS1.1, BYPASS2.1
D+_LARA: R10.1, U15.2 (USBDP_DN1)
D+_NEO: R66.1, U15.7 (USBDP_DN3)
D+_UBLOX: D8.1 (IO1), J6.A6 (D+), J6.B6 (D+), R23.1
D+_ZED: R7.1, U15.4 (USBDP_DN2)
D-_LARA: R9.1, U15.1 (USBDM_DN1)
D-_NEO: R67.1, U15.6 (USBDM_DN3)
D-_UBLOX: D8.3 (IO2), J6.A7 (D-), J6.B7 (D-), R22.1
D-_ZED: R8.1, U15.3 (USBDM_DN2)
ESP13/LARA_TXDI: U16.12 (B3); also elsewhere on the board
ESP14/LARA_RXDO: U16.13 (B2); also elsewhere on the board
ESP21/SDA: R72.1, SDA.1, U4.44 (SDA/!CS!), U5.18 (SDA/!CS!), USB251SDA.1; also elsewhere on the board
ESP22/SCL: R71.1, SCL.1, U4.45 (SCL/CLK), U5.19 (SCL/SCK), USB251SCL.1; also elsewhere on the board
ESP25/ZED_TXO: U4.42 (TX/MISO), ZED_TXO.1; also elsewhere on the board
ESP26/LARA_PWR_ON: R69.2, R70.1; also elsewhere on the board
ESP33/ZED_RXI: U4.43 (RX/MOSI), ZED_RXI.1; also elsewhere on the board
ESP34/LARA_NI: U16.14 (B1); also elsewhere on the board
GND: C5.2, C11.2, C12.2, C24.2, C29.2, C30.2, C53.2, C54.2, C58.2, C62.2, C63.1, C64.1, C65.2, C66.2, C67.2, C68.2, C69.2, C70.2, C71.2, C72.1, C73.2, C74.1, C75.1, C76.-, C77.2, C78.2, C79.2, C80.2, C81.2, D1.2, D8.2 (VSS), D11.2, D11.5, D12.2, D13.2, GNSS_RF.GND@0 (GND), GNSS_RF.GND@1 (GND), GNSS_RF.GND@2 (GND), GNSS_RF.GND@3 (GND), J2.C5 (GND), J6.GND, J6.GND2 (GND), L2.2, L3.2, LARA_RF1.GND@0 (GND), LARA_RF1.GND@1 (GND), LARA_RF1.GND@2 (GND), LARA_RF1.GND@3 (GND), LARA_RF2.GND@0 (GND), LARA_RF2.GND@1 (GND), LARA_RF2.GND@2 (GND), LARA_RF2.GND@3 (GND), Q2.1 (E), Q2.4 (E), Q5.2 (S), Q6.2 (S), R12.2, R14.1, R17.1, R20.1, R33.1, R34.1, R44.1, R52.1, R58.2, R69.1, SHLD2.1, U4.1 (GND), U4.3 (GND), U4.12 (GND), U4.14 (GND), U4.32 (GND), U4.37 (GND), U4.41 (GND), U4.48 (GND), U4.55 (GND), U4.56 (GND), U4.57 (GND), U4.58 (GND), U4.59 (GND), U4.60 (GND), U4.61 (GND), U4.62 (GND), U4.63 (GND), U4.64 (GND), U4.65 (GND), U4.66 (GND), U4.67 (GND), U4.68 (GND), U4.69 (GND), U4.70 (GND), U4.71 (GND), U4.72 (GND), U4.73 (GND), U4.74 (GND), U4.75 (GND), U4.76 (GND), U4.77 (GND), U4.78 (GND), U4.79 (GND), U4.80 (GND), U4.81 (GND), U4.82 (GND), U4.83 (GND), U4.84 (GND), U4.85 (GND), U4.86 (GND), U4.87 (GND), U4.88 (GND), U4.89 (GND), U4.90 (GND), U4.91 (GND), U4.92 (GND), U4.93 (GND), U4.94 (GND), U4.95 (GND), U4.96 (GND), U4.97 (GND), U4.98 (GND), U4.99 (GND), U4.100 (GND), U4.101 (GND), U4.102 (GND), U5.10 (GND), U5.12 (GND), U5.13 (GND), U5.24 (GND), U8.1 (GND), U8.3 (GND), U8.5 (GND), U8.9 (DTR_I), U8.10 (RTS_I), U8.14 (GND), U8.20 (GND), U8.21 (GND), U8.22 (GND), U8.30 (GND), U8.32 (GND), U8.43 (GND), U8.50 (GND), U8.54 (GND), U8.55 (GND), U8.57 (GND), U8.58 (GND), U8.60 (GND), U8.61 (GND), U8.63 (GND), U8.64 (GND), U8.65 (GND), U8.66 (GND), U8.67 (GND), U8.68 (GND), U8.69 (GND), U8.70 (GND), U8.71 (GND), U8.72 (GND), U8.73 (GND), U8.74 (GND), U8.75 (GND), U8.76 (GND), U8.77 (GND), U8.78 (GND), U8.79 (GND), U8.80 (GND), U8.81 (GND), U8.82 (GND), U8.83 (GND), U8.84 (GND), U8.85 (GND), U8.86 (GND), U8.87 (GND), U8.88 (GND), U8.89 (GND), U8.90 (GND), U8.91 (GND), U8.92 (GND), U8.93 (GND), U8.94 (GND), U8.95 (GND), U8.96 (GND), U11.2 (P$V-), U13.2 (P$V-), U14.1 (GND), U14.3 (GND), U14.4 (GND), U14.6 (GND), U14.7 (GND), U15.11 (TEST), U15.EP (GND), U16.7 (DIR3), U16.9 (!OE), U16.10 (GND), U18.3 (P$V-); also elsewhere on the board
GNSS_!RESET!: C58.1, R64.1, U4.49 (!RESET!), U5.8 (!RESET!), U18.2 (A); also elsewhere on the board
LARA_18_NI: U8.16 (GPIO1), U16.3 (A1)
LARA_18_RXDO: U8.13 (RXD_O), U16.4 (A2)
LARA_18_TXDI: U8.12 (TXD_I), U16.5 (A3)
LARA_!RESET!: Q6.3 (D), U8.18 (RESET_N)
LARA_PWR_ON: Q5.3 (D), U8.15 (PWR_ON)
unnamed: R7.2, U4.40 (USB_D+)
unnamed: R8.2, U4.39 (USB_D-)
unnamed: J6.SHLD1 (SHLD), J6.SHLD2 (SHLD), J6.SHLD3 (SHLD), J6.SHLD4 (SHLD), SHLD2.2
unnamed: R27.1, U4.51 (EXTINT)
unnamed: R46.1, U4.27 (TX2)
unnamed: R68.1, U18.4 (Y)
unnamed: R66.2, U5.6 (USB_D+)
unnamed: R67.2, U5.5 (USB_D-)
unnamed: R47.1, U4.26 (RX2)
unnamed: J6.B5 (CC2), R33.2
unnamed: J6.A5 (CC1), R34.2
unnamed: R56.1, U11.1 (OUT)
unnamed: R6.1, U4.53 (TIMEPULSE)
unnamed: Q2.5 (B), R56.2
unnamed: Q2.2 (B), R63.2
unnamed: R63.1, U13.1 (OUT)
unnamed: Q6.1 (G), R68.2
unnamed: I2C1.3, R71.2
unnamed: I2C1.1, R72.2
unnamed: R9.2, U8.28 (USB_D-)
unnamed: R10.2, U8.29 (USB_D+)
unnamed: C63.2, R13.2, U15.33 (XTALIN), Y2.3 (2)
unnamed: C64.2, R13.1, U15.32 (XTALOUT), Y2.1
unnamed: R12.1, U15.35 (RBIAS)
unnamed: R14.2, U15.28 (SUSP_IND)
unnamed: R17.2, U15.25 (HS_IND/CFG1)
unnamed: C65.1, U15.34 (PLLFILT)
unnamed: C66.1, U15.14 (CRFILT)
unnamed: R22.2, U15.30 (USBDM_UP)
unnamed: R23.2, U15.31 (USBDP_UP)
unnamed: C82.2, D12.1, LARA_RF1.SIG (SIGNAL)
unnamed: C82.1, L2.1, U8.56 (ANT)
unnamed: C83.2, D13.1, LARA_RF2.SIG (SIGNAL)
unnamed: C83.1, L3.1, U8.62 (ANT2)
unnamed: Q5.1 (G), R70.2
NEO_RXI: NEO_RX.1, U5.21 (RXD1/PICO)
NEO_TXO: NEO_TX.1, U5.20 (TXD1/POCI)
RF: C13.1, D1.1, FB1.2, GNSS_RF.SIG (SIGNAL)
SIM_CLK: C71.1, D11.1, J2.C3 (CLK), U8.38 (SIM_CLK)
SIM_IO: C74.2, D11.6, J2.C7 (I/O), U8.39 (SIM_IO)
SIM_RST: C72.2, D11.4, J2.C2 (RST), U8.40 (SIM_RST)
USB251SCL: R52.2, U15.24 (SCL/CFG0), USB251SCL.2
USB251SDA: R44.2, U15.22 (SDA), USB251SDA.2
USB_!RESET: C67.1, R18.1, U15.26 (!RESET)
VBUS_DET: C68.1, R20.2, R21.1, U15.27 (VBUS_DET)
VCCIO: C69.1, C70.1, U8.4 (V_INT), U16.1 (DIR1), U16.2 (DIR2), U16.6 (A4), U16.8 (DIR4), U16.16 (VCCA), VCCIO.1
VSIM: C73.1, C75.2, D11.3, J2.C1 (VCC), U8.41 (VSIM)
V_ANT: C11.1, FB1.1, R55.2, R59.2, R60.2, R61.2, U11.3 (+IN), U13.4 (-IN), VANT.1
V_USB_2: D8.5 (VCC), J6.VBUS1 (VBUS), J6.VBUS2 (VBUS), R21.2, U8.17 (VUSB_DET), VUSB2.1; also elsewhere on the board
ZED_EXTINT: R27.2, R28.1, ZED_EXTINT.1; also elsewhere on the board
ZED_RX2: R47.2, RX2.1; also elsewhere on the board
ZED_TP: R6.2, TP.1; also elsewhere on the board
ZED_TX2: R46.2, TX2.1; also elsewhere on the board

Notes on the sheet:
Vcc Max: 5.5V
50Ω
90Ω
u-blox ZED-F9P
VCC Range: 3.0 - 3.6V
u-blox LARA-R6001
Antenna Power
7-bit unshifted I2C address: 0x43
u-blox NEO-D9S
USB Hub USB-C
Open jumper to isolate shield
Antenna Splitter
7-bit unshifted I2C address: 0x42
7-bit unshifted I²C address: 0x2C
USB2513, or USB2514 can be used
USB Hub
SIM
Open Collector Outputs
Close jumpers to enable pull-ups
For non-L-Band products: Do Not Populate U14 Change BYPASS1 & BYPASS2 to PASTE (Or solder closed manually)
ANT
ANT_ZED
Paul Clark
v11

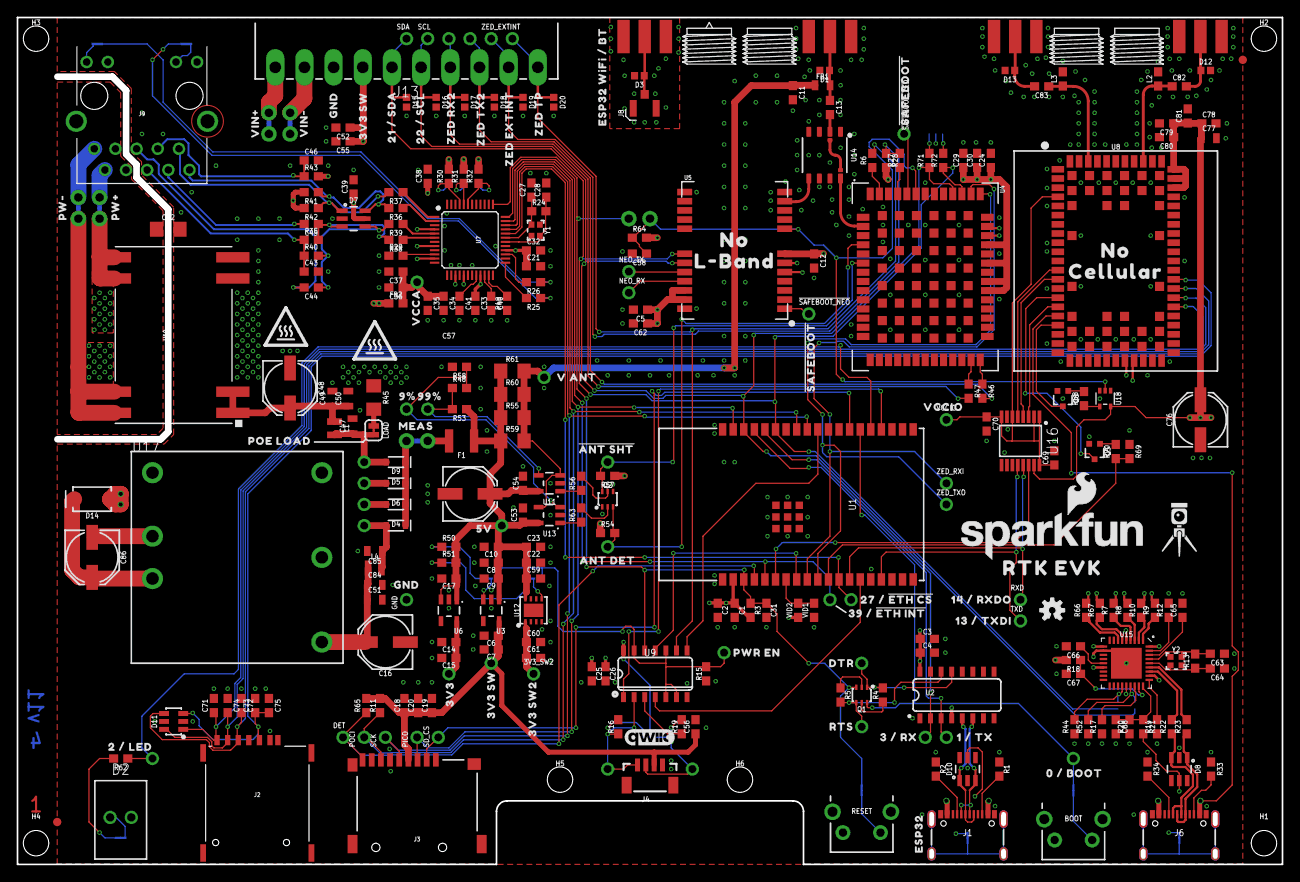
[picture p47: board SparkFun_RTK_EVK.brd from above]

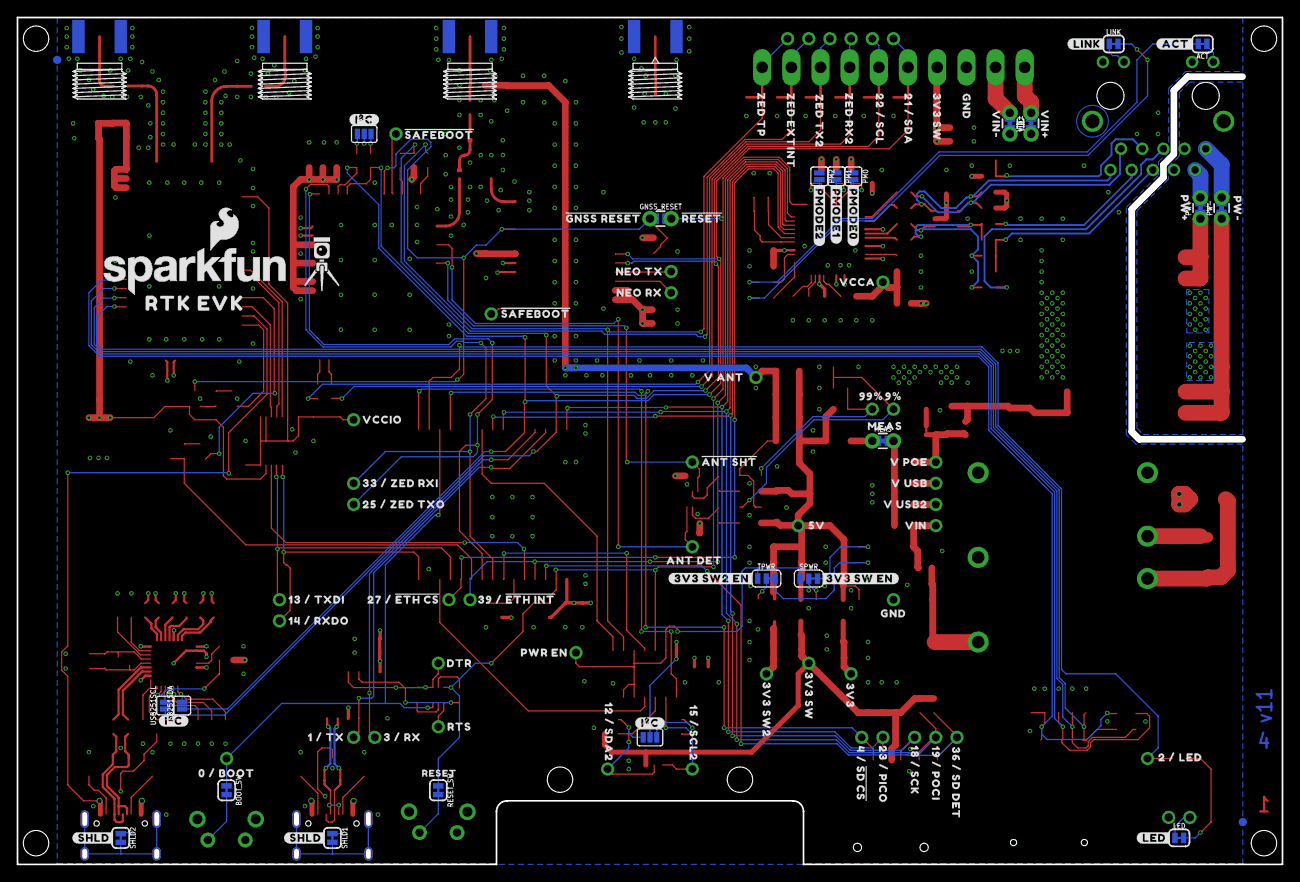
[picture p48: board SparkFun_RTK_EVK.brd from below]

Board: 4 copper layers, 151.8 x 101.6 mm, 435 parts (97 on the bottom side), 176 nets.

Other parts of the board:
LOGO2: QWIIC_LOGO_6MM; QWIIC_6MM
LOGO7: SFE_LOGO_NAME.2_INCH; SFE_LOGO_NAME_.2
LOGO8: SFE_LOGO_FLAME.2_INCH; SFE_LOGO_FLAME_.2
U$2: 33_#_ZED_RXI0
U$3, U$45: #SHLD#0
U$4, U$46, U$48: #I�C#0
U$5, U$113: PW#0
U$6, U$114: PW#1
U$7, U$149: 0_#_BOOT0
U$8, U$12, U$41, U$93: #SAFEBOOT#2226
U$9: #ACT#0
U$10: #LINK#1
U$11, U$13: RTK_EVK0
U$14: NEO_TX2
U$15: NEO_RX3
U$16, U$18: GND2
U$17, U$65: 3V3_SW20
U$19: 12_#_SDA20
U$20: 15_#_SCL213
U$21: ESP32_WIFI_#_BT0
U$22, U$23: 3V3_SW3
U$24, U$107: VCCA0
U$25, U$26: 21_#_SDA4
U$28, U$30: 22_#_SCL22
U$29, U$111: 27_#_#ETH_CS#0
U$31, U$32: ZED_RX223
U$33, U$36: ZED_TX2224
U$34, U$99: 1_#_TX20
U$35, U$100: 3_#_RX20
U$37, U$38: ZED_EXTINT2225
U$39, U$40: ZED_TP2226
U$42, U$94: ANT_DET2227
U$43, U$95: #ANT_SHT#2228
U$44, U$106: 9#2230
U$47, U$104: 99#2230
U$49, U$105: V_ANT2229
U$55, U$76: RTS2231
U$56, U$77: DTR2232
U$57, U$66: 2_#_LED0
U$58: #LED#2234
U$59, U$88: 3V3_SW25
U$60, U$87: 3V325
U$61, U$86: 5V25
U$62, U$84: MEAS2
U$63, U$70: VIN#0
U$64: 36_#_SD_DET0
U$67: #PMODE0#0
U$68: #PMODE1#1
U$69: #PMODE2#2
U$71, U$72: VIN#1
U$73, U$108: 14_#_RXDO0
U$74: #RESET#0
U$75, U$103: 13_#_TXDI15
U$78: ESP320
U$79, U$110: 39_#_#ETH_INT#0
U$80, U$141: PWR_EN2233
U$81: V_POE0
U$82: V_USB3
U$83: V_USB24
U$85: VIN1
U$89: 4_#_#SD_CS#15
U$90: 25_#_ZED_TXO0
U$91, U$92: NO0
U$96: CELLULAR2
U$97: L#BAND1
U$98: 23_#_PICO23
U$101: 19_#_POCI19
U$102: 18_#_SCK6
U$115, U$116: VCCIO0
U$117: #3V3_SW_EN#0
U$118: #3V3_SW2_EN#0
U$135, U$143: GND12
U$136: POE_LOAD0
U$146, U$147: HIGH_TEMP_WARNING
U$148: RESET0
U$152, U$153: RTK5#SVG0
U$154: #GNSS_RESET#0

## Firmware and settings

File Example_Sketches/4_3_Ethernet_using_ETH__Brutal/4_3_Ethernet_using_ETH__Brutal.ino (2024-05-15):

/*
  SparkFun RTK EVK Test Sketch

  W5500 Ethernet using the Espressif ESP32 ETH. Based on:
  https://github.com/espressif/arduino-esp32/blob/master/libraries/Ethernet/examples/ETH_W5500_Arduino_SPI/ETH_W5500_Arduino_SPI.ino

  Select ESP32 Wrover as the board

  NOTE: this requires arduino-esp32 v3.0.0

  Tested with v3.0.0 RC2:
  https://github.com/espressif/arduino-esp32/releases/tag/3.0.0-rc2

  See: https://docs.espressif.com/projects/arduino-esp32/en/latest/installing.html
  Add this link to the Additional Boards Manager URLs: https://espressif.github.io/arduino-esp32/package_esp32_dev_index.json

  See also:
  https://docs.espressif.com/projects/arduino-esp32/en/latest/migration_guides/2.x_to_3.0.html
  https://docs.espressif.com/projects/arduino-esp32/en/latest/migration_guides/2.x_to_3.0.html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

  Prints updates to the OLED - to ensure simultaneous SPI and I2C is possible

  Connects the STAT LED to the GNSS Time Pulse - to ensure Arduino interrupts still work correctly

  Accesses the microSD - to ensure simultaneous Arduino SPI is possible
  The SD SPI communication is intentionally brutal - with repeated SPI.begin() and forced SPI_MODE0

  License: MIT. Please see LICENSE.md for more details

  ESP32-WROVER-IE Pin Allocations:
  D0  : Boot + Boot Button
  D1  : Serial TX (CH340 RX)
  D2  : STAT LED
  D3  : Serial RX (CH340 TX)
  D4  : SD CS
  D5  : GNSS Time Pulse - via 74HC4066 switch and PWREN
  D12 : SDA2 - Qwiic OLED - via 74HC4066 switch and PWREN
  D13 : Serial1 TX - LARA_TXDI
  D14 : Serial1 RX - LARA RXDO
  D15 : SCL2 - Qwiic OLED - via 74HC4066 switch and PWREN
  D16 : N/A
  D17 : N/A
  D18 : SPI SCK
  D19 : SPI POCI
  D21 : I2C SDA
  D22 : I2C SCL
  D23 : SPI PICO
  D25 : Serial2 RX - ZED-F9P TXO
  D26 : LARA Power On
  D27 : Ethernet Chip Select
  D32 : PWREN
  D33 : Serial2 TX - ZED-F9P RXI
  A34 : LARA Network Indicator
  A35 : Board Detect (3.0V)
  A36 : SD Card Detect
  A39 : Ethernet Interrupt
*/

// -=-=-=-=-=-=-=-=-=-=-=-=-=-=-=-=-=-=-=-=-=-=-=-=-=-=-=-=-=-=-=-=-=-=-=-=-=-=-=-=-=-=-=-=-=-=-=-=-=-=
// I2C OLED

#include <Wire.h>
TwoWire I2C_2 = TwoWire(1);

#include <SparkFun_Qwiic_OLED.h> //http://librarymanager/All#SparkFun_Qwiic_OLED
Qwiic1in3OLED myOLED;            // 128x64

// Fonts
#include <res/qw_fnt_5x7.h>

// -=-=-=-=-=-=-=-=-=-=-=-=-=-=-=-=-=-=-=-=-=-=-=-=-=-=-=-=-=-=-=-=-=-=-=-=-=-=-=-=-=-=-=-=-=-=-=-=-=-=
// arduino-esp32 Ethernet

#include <SPI.h>
#include <ETH.h>

const int STAT_LED = 2;
const int SD_CS = 4;         // Chip select for the microSD card
const int GNSS_INT = 5;      // ZED_F9P time pulse interrupt
const int SDA_2 = 12;        // OLED
const int SERIAL1_TX = 13;   // LARA_TXDI
const int SERIAL1_RX = 14;   // LARA RXDO
const int SCL_2 = 15;        // OLED
const int SDA_1 = 21;        // ZED-F9P and NEO-D9S
const int SCL_1 = 22;        // ZED-F9P and NEO-D9S
const int SERIAL2_RX = 25;   // ZED-F9P TXO
const int LARA_PWR = 26;     // LARA_PWR_ON - inverted - set LARA_PWR high to pull LARA_PWR_ON low
const int ETHERNET_CS = 27;  // Chip select for the WizNet W5500
const int PWREN = 32;        // 74HC4066 switch Enable - pull high to enable SCL2/SDA2 and GNSS_INT
const int SERIAL2_TX = 33;   // ZED-F9P RXI
const int LARA_NI = 34;      // LARA Network Indicator - only valid when the LARA is powered on
const int SD_PRESENT = 36;   // microSD card card present - from the microSD socket switch
const int ETHERNET_INT = 39; // WizNet W5500 interrupt

#define ETH_PHY_TYPE ETH_PHY_W5500
#define ETH_PHY_ADDR 0
#define ETH_PHY_CS ETHERNET_CS
#define ETH_PHY_IRQ ETHERNET_INT
#define ETH_PHY_RST -1

#define ETH_SPI_SCK 18
#define ETH_SPI_MISO 19
#define ETH_SPI_MOSI 23

static bool eth_connected = false;

void onEvent(arduino_event_id_t event, arduino_event_info_t info)
{
    switch (event)
    {
    case ARDUINO_EVENT_ETH_START:
        Serial.println("ETH Started");
        // set eth hostname here
        ETH.setHostname("esp32-eth0");
        break;
    case ARDUINO_EVENT_ETH_CONNECTED:
        Serial.println("ETH Connected");
        break;
    case ARDUINO_EVENT_ETH_GOT_IP:
        Serial.printf("ETH Got IP: '%s'\n", esp_netif_get_desc(info.got_ip.esp_netif));
        Serial.println(ETH);
        eth_connected = true;
        break;
    case ARDUINO_EVENT_ETH_LOST_IP:
        Serial.println("ETH Lost IP");
        eth_connected = false;
        break;
    case ARDUINO_EVENT_ETH_DISCONNECTED:
        Serial.println("ETH Disconnected");
        eth_connected = false;
        break;
    case ARDUINO_EVENT_ETH_STOP:
        Serial.println("ETH Stopped");
        eth_connected = false;
        break;
    default:
        break;
    }
}

void testClient(const char *host, uint16_t port)
{
    Serial.print("\nConnecting to ");
    Serial.println(host);

    myOLED.erase();

    myOLED.setFont(QW_FONT_5X7);
    myOLED.text(0, 0, "Connecting to");
    myOLED.text(0, 8, host);
    myOLED.display();

    NetworkClient client;
    if (!client.connect(host, port))
    {
        Serial.println("Connection failed");
        myOLED.text(0, 16, "Connection failed");
        myOLED.display();
        return;
    }

    client.printf("GET / HTTP/1.1\r\nHost: %s\r\n\r\n", host);

    while (client.connected() && !client.available())
        ;

    if (client.available())
    {
        myOLED.text(0, 16, "Client connected");
        myOLED.display();
    }

    // NOTE: don't call sdPresent here. It causes SdFat SPI to fail...
    // if (sdPresent() == true)
    // {
    //     Serial.println("\nSD present\n");
    //     myOLED.text(0, 40, "SD present");
    //     myOLED.display();

        int files = countFiles();
        Serial.printf("\nFiles found: %d\n\n", files);
        char printMe[21];
        snprintf(printMe, sizeof(printMe), "Files found: %d", files);
        myOLED.text(0, 48, printMe);
        myOLED.display();
    // }
    // else
    // {
    //     Serial.println("\nSD NOT present\n");
    //     myOLED.text(0, 40, "SD NOT present");
    //     myOLED.display();
    // }

    while (client.available())
    {
        Serial.write(client.read());
    }

    Serial.println("Closing connection\n");
    myOLED.text(0, 24, "Closing connection");
    myOLED.display();

    client.stop();
}

// -=-=-=-=-=-=-=-=-=-=-=-=-=-=-=-=-=-=-=-=-=-=-=-=-=-=-=-=-=-=-=-=-=-=-=-=-=-=-=-=-=-=-=-=-=-=-=-=-=-=

void tpISR()
{
    digitalWrite(STAT_LED, digitalRead(GNSS_INT)); // Make the LED follow TP
}

// -=-=-=-=-=-=-=-=-=-=-=-=-=-=-=-=-=-=-=-=-=-=-=-=-=-=-=-=-=-=-=-=-=-=-=-=-=-=-=-=-=-=-=-=-=-=-=-=-=-=
// Brutal microSD card access - with SPI.begin() and modified SPISettings

// Attempt to de-init the SD card - SPI only
// https://github.com/greiman/SdFat/issues/351
void resetSPI()
{
    pinMode(SD_CS, OUTPUT);
    digitalWrite(SD_CS, HIGH); // De-select SD card

    // Flush SPI interface
    SPI.begin();
    SPI.beginTransaction(SPISettings(400000, MSBFIRST, SPI_MODE0));
    for (int x = 0; x < 10; x++)
        SPI.transfer(0XFF);
    SPI.endTransaction();
    SPI.end();

    digitalWrite(SD_CS, LOW); // Select SD card

    // Flush SD interface
    SPI.begin();
    SPI.beginTransaction(SPISettings(400000, MSBFIRST, SPI_MODE0));
    for (int x = 0; x < 10; x++)
        SPI.transfer(0XFF);
    SPI.endTransaction();
    SPI.end();

    digitalWrite(SD_CS, HIGH); // Deselet SD card
}

// Define commands for the SD card
#define SD_GO_IDLE (0x40 + 0)      // CMD0 - go to idle state
#define SD_INIT (0x40 + 1)         // CMD1 - start initialization
#define SD_SEND_IF_COND (0x40 + 8) // CMD8 - send interface (conditional), works for SDHC only
#define SD_SEND_STATUS (0x40 + 13) // CMD13 - send card status
#define SD_SET_BLK_LEN (0x40 + 16) // CMD16 - set length of block in bytes
#define SD_LOCK_UNLOCK (0x40 + 42) // CMD42 - lock/unlock card
#define SD_CMD55 (0x40 + 55)       // multi-byte preface command
#define SD_READ_OCR (0x40 + 58)    // read OCR
#define SD_ADV_INIT (0xc0 + 41)    // ACMD41, for SDHC cards - advanced start initialization

// Define options for accessing the SD card's PWD (CMD42)
#define MASK_ERASE 0x08       // erase the entire card
#define MASK_LOCK_UNLOCK 0x04 // lock or unlock the card with password
#define MASK_CLR_PWD 0x02     // clear password
#define MASK_SET_PWD 0x01     // set password

// Define bit masks for fields in the lock/unlock command (CMD42) data structure
#define SET_PWD_MASK (1 << 0)
#define CLR_PWD_MASK (1 << 1)
#define LOCK_UNLOCK_MASK (1 << 2)
#define ERASE_MASK (1 << 3)

// Begin initialization by sending CMD0 and waiting until SD card
// responds with In Idle Mode (0x01). If the response is not 0x01
// within a reasonable amount of time, there is no SD card on the bus.
// Returns false if not card is detected
// Returns true if a card responds
bool sdPresent(void)
{
    byte response = 0;

    SPI.begin();
    SPI.setClockDivider(SPI_CLOCK_DIV2);
    SPI.setDataMode(SPI_MODE0);
    SPI.setBitOrder(MSBFIRST);
    pinMode(SD_CS, OUTPUT);

    // Sending clocks while card power stabilizes...
    deselectCard();               // always make sure
    for (byte i = 0; i < 30; i++) // send several clocks while card power stabilizes
        xchg(0xff);

    // Sending CMD0 - GO IDLE...
    for (byte i = 0; i < 0x10; i++) // Attempt to go idle
    {
        response = sdSendCommand(SD_GO_IDLE, 0); // send CMD0 - go to idle state
        if (response == 1)
            break;
    }
    if (response != 1)
        return (false); // Card failed to respond to idle

    return (true);
}

/*
    sdSendCommand      send raw command to SD card, return response

    This routine accepts a single SD command and a 4-byte argument.  It sends
    the command plus argument, adding the appropriate CRC.  It then returns
    the one-byte response from the SD card.

    For advanced commands (those with a command byte having bit 7 set), this
    routine automatically sends the required preface command (CMD55) before
    sending the requested command.

    Upon exit, this routine returns the response byte from the SD card.
    Possible responses are:
      0xff  No response from card; card might actually be missing
      0x01  SD card returned 0x01, which is OK for most commands
      0x??  other responses are command-specific
*/
byte sdSendCommand(byte command, unsigned long arg)
{
    byte response;

    if (command & 0x80) // special case, ACMD(n) is sent as CMD55 and CMDn
    {
        command &= 0x7f;                    // strip high bit for later
        response = sdSendCommand(SD_CMD55, 0); // send first part (recursion)
        if (response > 1)
            return (response);
    }

    deselectCard();
    xchg(0xFF);
    selectCard(); // enable CS
    xchg(0xFF);

    xchg(command | 0x40);    // command always has bit 6 set!
    xchg((byte)(arg >> 24)); // send data, starting with top byte
    xchg((byte)(arg >> 16));
    xchg((byte)(arg >> 8));
    xchg((byte)(arg & 0xFF));

    byte crc = 0x01; // good for most cases
    if (command == SD_GO_IDLE)
        crc = 0x95; // this will be good enough for most commands
    if (command == SD_SEND_IF_COND)
        crc = 0x87; // special case, have to use different CRC
    xchg(crc);      // send final byte

    for (int i = 0; i < 30; i++) // loop until timeout or response
    {
        response = xchg(0xFF);
        if ((response & 0x80) == 0)
            break; // high bit cleared means we got a response
    }

    /*
        We have issued the command but the SD card is still selected.  We
        only deselectCard the card if the command we just sent is NOT a command
        that requires additional data exchange, such as reading or writing
        a block.
    */
    if ((command != SD_READ_OCR) && (command != SD_SEND_STATUS) && (command != SD_SEND_IF_COND) &&
        (command != SD_LOCK_UNLOCK))
    {
        deselectCard(); // all done
        xchg(0xFF);     // close with eight more clocks
    }

    return (response); // let the caller sort it out
}

// Select (enable) the SD card
void selectCard(void)
{
    digitalWrite(SD_CS, LOW);
}

// Deselect (disable) the SD card
void deselectCard(void)
{
    digitalWrite(SD_CS, HIGH);
}

// Exchange a byte of data with the SD card via host's SPI bus
byte xchg(byte val)
{
    byte receivedVal = SPI.transfer(val);
    return receivedVal;
}

// -=-=-=-=-=-=-=-=-=-=-=-=-=-=-=-=-=-=-=-=-=-=-=-=-=-=-=-=-=-=-=-=-=-=-=-=-=-=-=-=-=-=-=-=-=-=-=-=-=-=
// SD access using SdFat

#include "SdFat.h"

SdFat *sd = nullptr;

// Make size of files human readable
void stringHumanReadableSize(String &returnText, uint64_t bytes)
{
    char suffix[5] = {'\0'};
    char readableSize[50] = {'\0'};
    float cardSize = 0.0;

    if (bytes < 1024)
        strcpy(suffix, "B");
    else if (bytes < (1024 * 1024))
        strcpy(suffix, "KB");
    else if (bytes < (1024 * 1024 * 1024))
        strcpy(suffix, "MB");
    else
        strcpy(suffix, "GB");

    if (bytes < (1024))
        cardSize = bytes; // B
    else if (bytes < (1024 * 1024))
        cardSize = bytes / 1024.0; // KB
    else if (bytes < (1024 * 1024 * 1024))
        cardSize = bytes / 1024.0 / 1024.0; // MB
    else
        cardSize = bytes / 1024.0 / 1024.0 / 1024.0; // GB

    if (strcmp(suffix, "GB") == 0)
        snprintf(readableSize, sizeof(readableSize), "%0.1f %s", cardSize, suffix); // Print decimal portion
    else if (strcmp(suffix, "MB") == 0)
        snprintf(readableSize, sizeof(readableSize), "%0.1f %s", cardSize, suffix); // Print decimal portion
    else if (strcmp(suffix, "KB") == 0)
        snprintf(readableSize, sizeof(readableSize), "%0.1f %s", cardSize, suffix); // Print decimal portion
    else
        snprintf(readableSize, sizeof(readableSize), "%.0f %s", cardSize, suffix); // Don't print decimal portion

    returnText = String(readableSize);
}

// Create a test file in file structure to make sure we can
bool createTestFile()
{
    SdFile testFile;

    // TODO: double-check that SdFat tollerates preceding slashes
    char testFileName[40] = "/testfile.txt";

    unsigned long startTime = millis();

    // Attempt to write to the file system
    if (testFile.open(testFileName, O_CREAT | O_APPEND | O_WRITE) != true)
    {
        Serial.println("createTestFile: failed to create (open) test file");
        return (false);
    }

    for (int i = 0; i < 1048576; i++)
        testFile.write(uint8_t(i & 0xFF));

    // File successfully created
    testFile.close();

    unsigned long endTime = millis();

    Serial.printf("createTestFile: wrote 1048576 bytes in %ldms\r\n", endTime - startTime);

    startTime = millis();

    // Attempt to read from the file system
    if (testFile.open(testFileName, O_READ) != true)
    {
        Serial.println("createTestFile: failed to open test file for reading");
        return (false);
    }

    for (int i = 0; i < 1048576; i++)
    {
        uint8_t c;
        testFile.read(&c, 1);
        if (c != (i & 0xFF))
            Serial.println("File read error!");
    }

    testFile.close();

    endTime = millis();

    Serial.printf("createTestFile: read 1048576 bytes in %ldms\r\n", endTime - startTime);

    SdFile dir;
    dir.open("/"); // Open root
    uint16_t fileCount = 0;

    SdFile tempFile;

    Serial.println("Files found:");

    while (tempFile.openNext(&dir, O_READ))
    {
        if (tempFile.isFile())
        {
            fileCount++;

            // 2017-05-19 187362648 800_0291.MOV

            // Get File Date from sdFat
            uint16_t fileDate;
            uint16_t fileTime;
            tempFile.getCreateDateTime(&fileDate, &fileTime);

            // Convert sdFat file date fromat into YYYY-MM-DD
            char fileDateChar[20];
            snprintf(fileDateChar, sizeof(fileDateChar), "%d-%02d-%02d",
                     ((fileDate >> 9) + 1980),   // Year
                     ((fileDate >> 5) & 0b1111), // Month
                     (fileDate & 0b11111)        // Day
            );

            char fileSizeChar[20];
            String fileSize;
            stringHumanReadableSize(fileSize, tempFile.fileSize());
            fileSize.toCharArray(fileSizeChar, sizeof(fileSizeChar));

            char fileName[50]; // Handle long file names
            tempFile.getName(fileName, sizeof(fileName));

            char fileRecord[100];
            snprintf(fileRecord, sizeof(fileRecord), "%s\t%s\t%s", fileDateChar, fileSizeChar, fileName);

            Serial.println(fileRecord);
        }
    }

    dir.close();
    tempFile.close();

    if (fileCount == 0)
        Serial.println("No files found");

    if (sd->exists(testFileName))
        sd->remove(testFileName);

    return (!sd->exists(testFileName));
}

// Count the files in the file structure to make sure we can
int countFiles()
{
    SdFile dir;
    dir.open("/"); // Open root
    int fileCount = 0;

    SdFile tempFile;

    while (tempFile.openNext(&dir, O_READ))
    {
        if (tempFile.isFile())
        {
            fileCount++;
        }
    }

    dir.close();
    tempFile.close();

    return (fileCount);
}

// -=-=-=-=-=-=-=-=-=-=-=-=-=-=-=-=-=-=-=-=-=-=-=-=-=-=-=-=-=-=-=-=-=-=-=-=-=-=-=-=-=-=-=-=-=-=-=-=-=-=

void setup()
{
    pinMode(SD_CS, OUTPUT);
    digitalWrite(SD_CS, HIGH);
    pinMode(ETHERNET_CS, OUTPUT);
    digitalWrite(ETHERNET_CS, HIGH);
    pinMode(GNSS_INT, INPUT);
    pinMode(STAT_LED, OUTPUT);
    digitalWrite(STAT_LED, HIGH);
    pinMode(PWREN, OUTPUT);
    digitalWrite(PWREN, HIGH);

    delay(1000);

    Serial.begin(115200);
    Serial.println("SparkFun RTK EVK - Test Sketch");

    // -=-=-=-=-=-=-=-=-=-=-=-=-=-=-=-=-=-=-=-=-=-=-=-=-=-=-=-=-=-=-=-=-=-=-=-=-=-=-=-=-=-=-=-=-=-=-=-=-=

    I2C_2.begin((int)SDA_2, (int)SCL_2, (uint32_t)400000);

    // Initalize the OLED device and related graphics system
    if (myOLED.begin(I2C_2) == false)
    {
        Serial.println("OLED begin failed...");
        return;
    }

    // -=-=-=-=-=-=-=-=-=-=-=-=-=-=-=-=-=-=-=-=-=-=-=-=-=-=-=-=-=-=-=-=-=-=-=-=-=-=-=-=-=-=-=-=-=-=-=-=-=

    attachInterrupt(GNSS_INT, tpISR, CHANGE);

    // -=-=-=-=-=-=-=-=-=-=-=-=-=-=-=-=-=-=-=-=-=-=-=-=-=-=-=-=-=-=-=-=-=-=-=-=-=-=-=-=-=-=-=-=-=-=-=-=-=
    // Begin SPI

    SPI.begin(ETH_SPI_SCK, ETH_SPI_MISO, ETH_SPI_MOSI);

    // -=-=-=-=-=-=-=-=-=-=-=-=-=-=-=-=-=-=-=-=-=-=-=-=-=-=-=-=-=-=-=-=-=-=-=-=-=-=-=-=-=-=-=-=-=-=-=-=-=
    // Brutal re-initialize the SPI/SD interface

    resetSPI();

    // Do a quick test to see if a card is present
    int tries1 = 0;
    int maxTries1 = 5;
    while (tries1 < maxTries1)
    {
        if (sdPresent() == true)
            break;
        Serial.printf("SD present failed (1). Trying again %d out of %d\r\n", tries1 + 1, maxTries1);

        // Max power up time is 250ms: https://www.kingston.com/datasheets/SDCIT-specsheet-64gb_en.pdf
        // Max current is 200mA average across 1s, peak 300mA
        delay(10);
        tries1++;
    }
    if (tries1 == maxTries1)
        return; // Give up loop

    // -=-=-=-=-=-=-=-=-=-=-=-=-=-=-=-=-=-=-=-=-=-=-=-=-=-=-=-=-=-=-=-=-=-=-=-=-=-=-=-=-=-=-=-=-=-=-=-=-=
    // Begin ETHernet

    Network.onEvent(onEvent);

    ETH.begin(ETH_PHY_TYPE, ETH_PHY_ADDR, ETH_PHY_CS, ETH_PHY_IRQ, ETH_PHY_RST, SPI);

    // -=-=-=-=-=-=-=-=-=-=-=-=-=-=-=-=-=-=-=-=-=-=-=-=-=-=-=-=-=-=-=-=-=-=-=-=-=-=-=-=-=-=-=-=-=-=-=-=-=
    // Brutal re-initialize the SPI/SD interface

    resetSPI();

    // Do a quick test to see if a card is present
    int tries2 = 0;
    int maxTries2 = 5;
    while (tries2 < maxTries2)
    {
        if (sdPresent() == true)
            break;
        Serial.printf("SD present failed (2). Trying again %d out of %d\r\n", tries2 + 1, maxTries2);

        // Max power up time is 250ms: https://www.kingston.com/datasheets/SDCIT-specsheet-64gb_en.pdf
        // Max current is 200mA average across 1s, peak 300mA
        delay(10);
        tries2++;
    }
    if (tries2 == maxTries2)
        return; // Give up loop

    // -=-=-=-=-=-=-=-=-=-=-=-=-=-=-=-=-=-=-=-=-=-=-=-=-=-=-=-=-=-=-=-=-=-=-=-=-=-=-=-=-=-=-=-=-=-=-=-=-=
    // Allocate the data structure that manages the microSD card

    if (!sd)
    {
        sd = new SdFat();
        if (!sd)
        {
            Serial.println("Failed to allocate the SdFat structure!");
            return;
        }
    }

    // -=-=-=-=-=-=-=-=-=-=-=-=-=-=-=-=-=-=-=-=-=-=-=-=-=-=-=-=-=-=-=-=-=-=-=-=-=-=-=-=-=-=-=-=-=-=-=-=-=
    // Begin SdFat microSD communication
    
    // resetSPI(); // Re-initialize the SPI/SD interface

    if (sd->begin(SdSpiConfig(SD_CS, SHARED_SPI, SD_SCK_MHZ(16))) == false)
    {
        int tries3 = 0;
        int maxTries3 = 2;
        for (; tries3 < maxTries3; tries3++)
        {
            Serial.printf("SD init failed - using SPI and SdFat. Trying again %d out of %d\r\n", tries3 + 1, maxTries3);

            delay(250); // Give SD more time to power up, then try again
            if (sd->begin(SdSpiConfig(SD_CS, SHARED_SPI, SD_SCK_MHZ(16))) == true)
                return;
        }

        if (tries3 == maxTries3)
        {
            Serial.println("SD init failed - using SPI and SdFat. Is card formatted?");
            digitalWrite(SD_CS, HIGH); // Be sure SD is deselected

            return;
        }
    }

    // -=-=-=-=-=-=-=-=-=-=-=-=-=-=-=-=-=-=-=-=-=-=-=-=-=-=-=-=-=-=-=-=-=-=-=-=-=-=-=-=-=-=-=-=-=-=-=-=-=
    // Access the file system using SdFat
    
    // Change to root directory. All new file creation will be in root.
    if (sd->chdir() == false)
    {
        Serial.println("SD change directory failed");
    }

    if (createTestFile())
        Serial.println("\nmicroSD + SdFat : success\n");
    else
        Serial.println("\nmicroSD + SdFat : FAIL\n");
}

void loop()
{
    if (eth_connected)
    {
        testClient("google.com", 80);
    }
    delay(10000);
}

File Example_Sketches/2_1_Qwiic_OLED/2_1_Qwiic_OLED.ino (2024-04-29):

/*
  SparkFun RTK EVK Test Sketch

  License: MIT. Please see LICENSE.md for more details

  ESP32-WROVER-IE Pin Allocations:
  D0  : Boot + Boot Button
  D1  : Serial TX (CH340 RX)
  D2  : STAT LED
  D3  : Serial RX (CH340 TX)
  D4  : SD CS
  D5  : GNSS Time Pulse - via 74HC4066 switch and PWREN
  D12 : SDA2 - Qwiic OLED - via 74HC4066 switch and PWREN
  D13 : Serial1 TX - LARA_TXDI
  D14 : Serial1 RX - LARA RXDO
  D15 : SCL2 - Qwiic OLED - via 74HC4066 switch and PWREN
  D16 : N/A
  D17 : N/A
  D18 : SPI SCK
  D19 : SPI POCI
  D21 : I2C SDA
  D22 : I2C SCL
  D23 : SPI PICO
  D25 : Serial2 RX - ZED-F9P TXO
  D26 : LARA Power On
  D27 : Ethernet Chip Select
  D32 : PWREN
  D33 : Serial2 TX - ZED-F9P RXI
  A34 : LARA Network Indicator
  A35 : Board Detect (3.0V)
  A36 : SD Card Detect
  A39 : Ethernet Interrupt
*/

const int STAT_LED = 2;
const int SD_CS = 4; // Chip select for the microSD card
const int GNSS_INT = 5; // ZED_F9P time pulse interrupt
const int SDA_2 = 12; // OLED
const int SERIAL1_TX = 13; // LARA_TXDI
const int SERIAL1_RX = 14; // LARA RXDO
const int SCL_2 = 15; // OLED
const int SDA_1 = 21; // ZED-F9P and NEO-D9S
const int SCL_1 = 22; // ZED-F9P and NEO-D9S
const int SERIAL2_RX = 25; // ZED-F9P TXO
const int LARA_PWR = 26; // LARA_PWR_ON - inverted - set LARA_PWR high to pull LARA_PWR_ON low
const int ETHERNET_CS = 27; // Chip select for the WizNet W5500
const int PWREN = 32; // 74HC4066 switch Enable - pull high to enable SCL2/SDA2 and GNSS_INT
const int SERIAL2_TX = 33; // ZED-F9P RXI
const int LARA_NI = 34; // LARA Network Indicator - only valid when the LARA is powered on
const int SD_PRESENT = 36; // microSD card card present - from the microSD socket switch
const int ETHERNET_INT = 39; // WizNet W5500 interrupt

#include <SparkFun_Qwiic_OLED.h> //http://librarymanager/All#SparkFun_Qwiic_OLED
Qwiic1in3OLED myOLED; // 128x64

TwoWire I2C_2 = TwoWire(1);

int width;
int height;

void setup()
{
  pinMode(SD_CS, OUTPUT);
  digitalWrite(SD_CS, HIGH);
  pinMode(ETHERNET_CS, OUTPUT);
  digitalWrite(ETHERNET_CS, HIGH);
  pinMode(PWREN, OUTPUT);
  digitalWrite(PWREN, HIGH);

  delay(1000);

  Serial.begin(115200);
  Serial.println("SparkFun RTK EVK - Test Sketch");

  I2C_2.begin((int)SDA_2, (int)SCL_2, (uint32_t)400000);

  // Initalize the OLED device and related graphics system
  if (myOLED.begin(I2C_2) == false)
  {
      Serial.println("OLED begin failed. Freezing...");
      while (true)
          ;
  }

  width = myOLED.getWidth();
  height = myOLED.getHeight();
}

void loop()
{
    pixelExample();
    lineExample();
    shapeExample();
}

void pixelExample()
{
    myOLED.erase();
    for (int i = 0; i < 512; i++)
    {
        myOLED.pixel(random(width), random(height));
        myOLED.display();
        delay(10);
    }
}

void lineExample()
{
    int middleX = width / 2;
    int middleY = height / 2;
    int xEnd, yEnd;
    int lineWidth = min(middleX, middleY);

    myOLED.erase();
    int deg;

    for (int i = 0; i < 3; i++)
    {

        for (deg = 0; deg < 360; deg += 15)
        {

            xEnd = lineWidth * cos(deg * PI / 180.0);
            yEnd = lineWidth * sin(deg * PI / 180.0);

            myOLED.line(middleX, middleY, middleX + xEnd, middleY + yEnd);
            myOLED.display();
            delay(10);
        }

        for (deg = 0; deg < 360; deg += 15)
        {

            xEnd = lineWidth * cos(deg * PI / 180.0);
            yEnd = lineWidth * sin(deg * PI / 180.0);

            myOLED.line(middleX, middleY, middleX + xEnd, middleY + yEnd, 0);
            myOLED.display();
            delay(10);
        }
    }
}

void shapeExample()
{
    // Silly pong demo. It takes a lot of work to fake pong...
    int paddleW = 3;  // Paddle width
    int paddleH = 15; // Paddle height

    // Paddle 0 (left) position coordinates
    int paddle0_Y = (height / 2) - (paddleH / 2);
    int paddle0_X = 2;

    // Paddle 1 (right) position coordinates
    int paddle1_Y = (height / 2) - (paddleH / 2);
    int paddle1_X = width - 3 - paddleW;
    int ball_rad = 4; // Ball radius

    // Ball position coordinates
    int ball_X = paddle0_X + paddleW + ball_rad;
    int ball_Y = random(1 + ball_rad, height - ball_rad); // paddle0_Y + ball_rad;
    int ballVelocityX = 1;                                // Ball left/right velocity
    int ballVelocityY = 1;                                // Ball up/down velocity
    int paddle0Velocity = -1;                             // Paddle 0 velocity
    int paddle1Velocity = 1;                              // Paddle 1 velocity

    // Draw the Pong Field
    myOLED.erase();

    // Draw an outline of the screen:
    myOLED.rectangle(0, 0, width - 1, height);

    // Draw the center line
    myOLED.rectangleFill(width / 2 - 1, 0, 2, height);

    bool firstLoop = true;

    while ((ball_X - ball_rad > 1) && (ball_X + ball_rad < width - 2))
    {

        if (!firstLoop)
        {

            // Erase the old ball. In XOR mode, so just draw old values again!
            // Draw the Paddles:
            myOLED.rectangleFill(paddle0_X, paddle0_Y, paddleW, paddleH);
            myOLED.rectangleFill(paddle1_X, paddle1_Y, paddleW, paddleH);
            // Draw the ball: - use rect - xor and circle fails b/c of circle algorithm overdraws
            myOLED.rectangleFill(ball_X, ball_Y, ball_rad, ball_rad);
        }
        // Increment ball's position
        ball_X += ballVelocityX;
        ball_Y += ballVelocityY;

        // Check if the ball is colliding with the left paddle
        if (ball_X - ball_rad < paddle0_X + paddleW)
        {

            // Check if ball is within paddle's height
            if ((ball_Y > paddle0_Y) && (ball_Y < paddle0_Y + paddleH))
            {

                ball_X++;                       // Move ball over one to the right
                ballVelocityX = -ballVelocityX; // Change velocity
            }
        }

        // Check if the ball hit the right paddle
        if (ball_X + ball_rad > paddle1_X)
        {

            // Check if ball is within paddle's height
            if ((ball_Y > paddle1_Y) && (ball_Y < paddle1_Y + paddleH))
            {

                ball_X--;                       // Move ball over one to the left
                ballVelocityX = -ballVelocityX; // change velocity
            }
        }

        // Check if the ball hit the top or bottom
        if ((ball_Y <= 1) || (ball_Y >= (height - ball_rad - 1)))
        {

            // Change up/down velocity direction
            ballVelocityY = -ballVelocityY;
        }

        // Move the paddles up and down
        paddle0_Y += paddle0Velocity;
        paddle1_Y += paddle1Velocity;

        // Change paddle 0's direction if it hit top/bottom
        if ((paddle0_Y <= 1) || (paddle0_Y > height - 2 - paddleH))
            paddle0Velocity = -paddle0Velocity;
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

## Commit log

2023-07-03 Airwire review
    [RTK_Control.brd, RTK_Control.sch]
2023-07-03 Update DC-DC and PoE voltages and currents
    [RTK_Control.sch]
2023-07-03 Updates after airwire review
    [RTK_Control.brd, RTK_Control.sch]
2023-07-04 Ready for routing
    [RTK_Control.brd, RTK_Control.sch]
2023-07-05 Partially routed
    [RTK_Control.brd, RTK_Control.sch]
2023-07-05 Almost routed
    [RTK_Control.brd, RTK_Control.sch]
2023-07-06 Change layer 15 polygon to 3.3V_SW
    [RTK_Control.brd]
2023-07-07 Ready for Proto Review
    [RTK_Control-Panel.GBL, RTK_Control-Panel.GBO, RTK_Control-Panel.GBP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]
2023-07-07 Correct v-score dimensions
    [RTK_Control-Panel.brd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]
2023-07-07 Add Route-Out gaps on panel
    [RTK_Control-Panel.brd, RTK_Control.brd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]
2023-07-07 Add schematic page 2
2023-07-10 Update Libraries, PROD_IDs etc.
    [RTK_Control.brd, RTK_Control.sch]
2023-07-10 Add prototype panel - with missing gaps
    [RTK_Control-Panel.GBL, RTK_Control-Panel.GBO, RTK_Control-Panel.GBP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]
2023-07-10 Update attribute positions
    [RTK_Control-Panel.brd]
2023-07-11 Add the panels
    [RTK_Control_Front_Panel.brd, RTK_Control_Front_Panel.sch, RTK_Control_Rear_Panel.brd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]
2023-07-12 Add images and gerbers
    [RTK_Control_Rear_Panel.brd]
2023-07-26 Add no L-Band bypass. Update silk. Increase display cutout.
    [RTK_Control-Panel.GBL, RTK_Control-Panel.GBO, RTK_Control-Panel.GBP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]
2023-07-27 Update RF Bypass SOIC Pad jumpers
    [RTK_Everywhere_L-Band_Cellular-Panel.brd, RTK_Everywhere_L-Band_Cellular.brd, RTK_Everywhere_L-Band_Cellular.sch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]
2023-09-05 Add 1.3" OLED
    [RTK_Control_Front_Panel.brd, RTK_Control_Front_Panel.sch]
2023-11-23 Add V10 PCB files
    [RTK_Everywhere_L-Band_Cellular-Panel.brd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]
2023-11-28 Add front panel drawings
    [RTK_Everywhere_Front_Panel.dxf]
2023-11-29 Add panel and sticker drawings
    [RTK_Everywhere_Front_Sticker.dxf, RTK_Everywhere_L-Band_Cellular_Rear_Panel.dxf, RTK_Everywhere_L-Band_Cellular_Rear_Sticker.dxf]
2023-12-04 Update filenames. Add datasheets
    [RTK_Control_Front_Panel.brd, RTK_Control_Front_Panel.sch, RTK_Control_Rear_Panel.brd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]
2024-02-07 Example 8_5: Disable PMP output on the NEO to stop the ZED getting correction data twice!
    [8_5_PointPerfect_MQTT.ino]
2024-02-07 Move I2C.begin into initPins
2024-02-08 v11 PCB
    [SparkFun_RTK_EVK-Panel.GBL, SparkFun_RTK_EVK-Panel.GBO, SparkFun_RTK_EVK-Panel.GBP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]
2024-02-09 Final tweaks
    [SparkFun_RTK_EVK-Panel.brd, SparkFun_RTK_EVK.brd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]
2024-02-09 docs updates
    [SparkFun_RTK_EVK-Panel.GBL, SparkFun_RTK_EVK-Panel.GBO, SparkFun_RTK_EVK-Panel.GBP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]
2024-02-12 Update examples for v1.1 PCB (RTK EVK)
2024-05-15 Add arduino-esp32 v3.0.0 W5500 Ethernet examples
2024-05-27 Correct clientID print
2024-05-28 Add link to ArduinoMqttClient
2024-05-28 Switch to us topic
2024-06-17 Update front sticker files
    [RTK_EVK_Front_Sticker_Dimensions.dxf]
2024-06-17 Update panel files
    [RTK_EVK_Front_Panel.dxf, RTK_EVK_Rear_Panel.dxf, RTK_Everywhere_Front_Panel.brd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]
2024-06-17 Update rear sticker files
    [RTK_EVK_Rear_Sticker_Dimensions.dxf]
2024-06-21 Adjust Related Documents and Assets for Product Page
    [RTK_EVK_Front_Panel.dxf, RTK_EVK_Front_Sticker_Dimensions.dxf, RTK_EVK_Rear_Panel.dxf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]
2024-06-22 Add Arduino Example Sketch
2024-06-22 Include OLED Display Outputs for Antenna Open and Short
2024-08-20 4_5: Add example 4_5_WiFi_HTTP for Arduino v3
2024-08-20 4_6: Add example 4_6_WiFi_HTTPS for Arduino v3
2024-08-20 4_7: Add example 4_7_Ethernet_HTTPS for Arduino v3
2024-08-20 9_1: Add example 9_1_PPP_Google for Arduino v3
2024-08-20 9_5: Add example 9_5_PPP_HTTPS for Arduino v3
2024-08-20 9_3: Add example 9_3_PPP_NTRIP_Client for Arduino v3
2024-08-20 9_4: Add example 9_4_PPP_Multiple_Clients for Arduino v3
2024-08-20 9_2: Add example 9_2_PPP_State_Machine for Arduino v3
2024-08-22 Restructure the power on sequence. Make the event queue optional
2024-09-01 9_6: Add example 9_6_Network_Failover for Arduino v3
2024-12-02 Fix compile errors for 4_9_ESP_NOW and 4_10_WIFI_AP_Server
    [4_10_WiFi_AP_Server.ino, 4_9_ESP_NOW.ino]

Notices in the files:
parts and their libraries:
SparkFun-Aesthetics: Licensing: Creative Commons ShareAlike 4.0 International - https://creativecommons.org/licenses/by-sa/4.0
